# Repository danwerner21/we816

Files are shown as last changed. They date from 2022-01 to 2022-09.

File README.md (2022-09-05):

# WE816
The WE816 is a 16-bit 65816 based system with 512K of System RAM, 96K of System ROM, 32K of video RAM, a TMS9918 graphics processor and an AY-3-8910 Sound chip.  The system runs a custom version of BASIC and supports commodore compatible IEC disk drives.

EhBASIC by Lee Davison was ported to the 65816 CPU on the WE816 computer.   It is designed to allow a full 64K bank for BASIC code and variables with the BASIC interpreter running in a totally different bank. Full documentation on the basic intrepreter can be found in the support folder

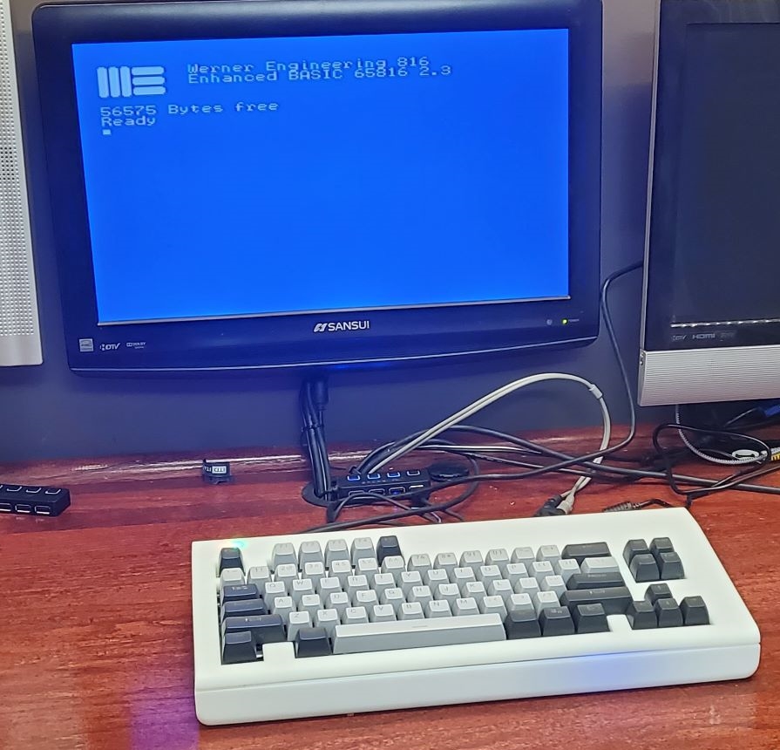
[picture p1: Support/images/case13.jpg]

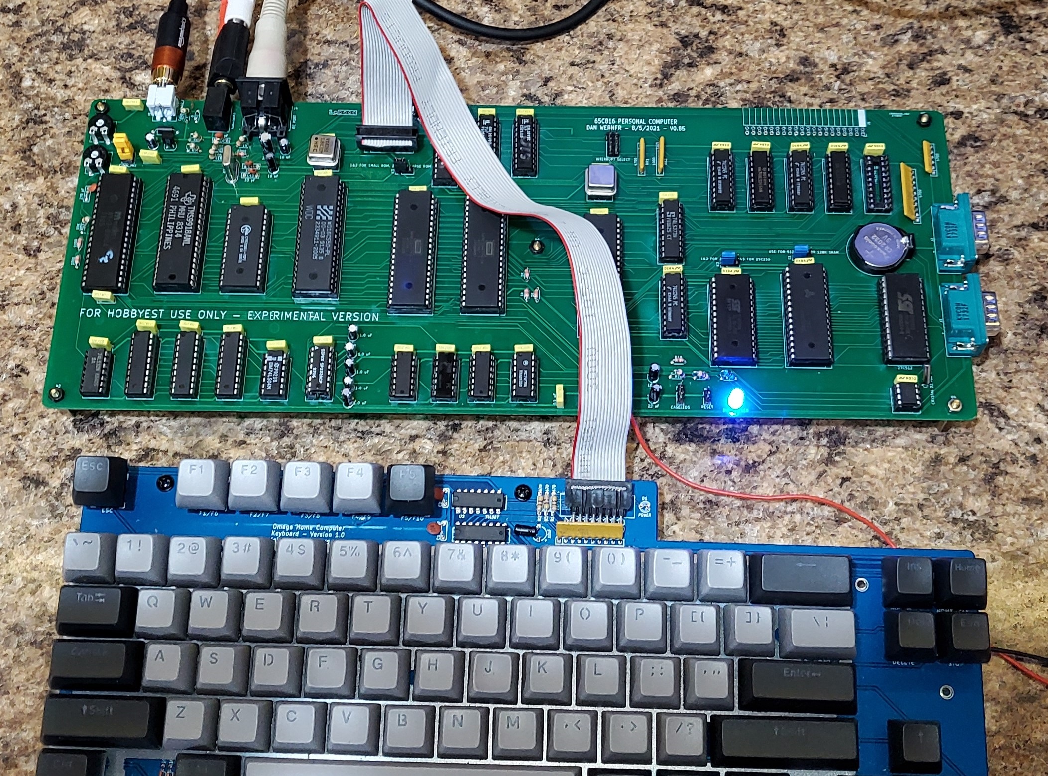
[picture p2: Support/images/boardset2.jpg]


---

## To Do:

* RTC Hardware (fixed needs PCB created and tested)

* BIOS RTC Code

* Basic Access to RTC

* Fix Video RAM paging

* Document BIOS Calls

---

## What is included in this repo?
As of this time, the repo includes

1. The WE816 Mainboard PCB Kicad design and Gerber files
2. The source code and binaries for the WE816 BASIC interpreter
3. The source code and binaries for the WE816 BIOS firmware
4. The source code and binaries for several hardware test programs
5. The logic equasions for the 3 GALs
6. **OpenSCAD and STL files for a 3d printed case

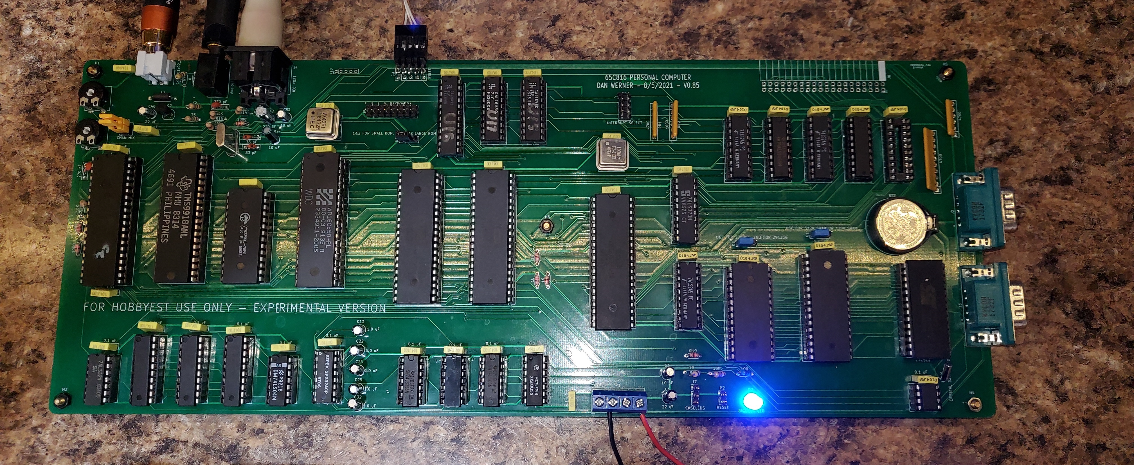
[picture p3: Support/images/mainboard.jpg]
Mainboard

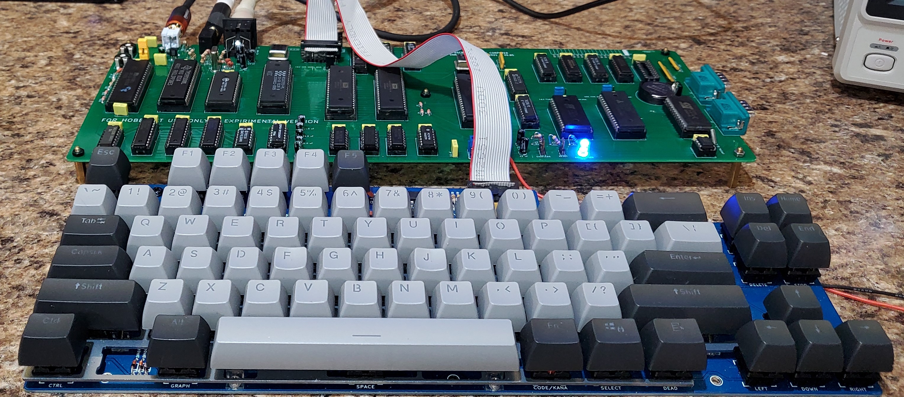
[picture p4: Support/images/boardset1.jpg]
Assembled


---

## Known Bugs

 * Note that the Real Time clock circuit on the 8/5/2021 .85 verson of the board is broken and will not work.  The schematic in this repo has been updated to a working version, but this board still has U12 Pin 6 & 7  connected to CB1 & 2 of U36 which has a broken shift register implementation.   I was under the mistaken impression that the shift register bug had been corrected on the WDC version of the 6522, but this is not the case.

### System Jumpers

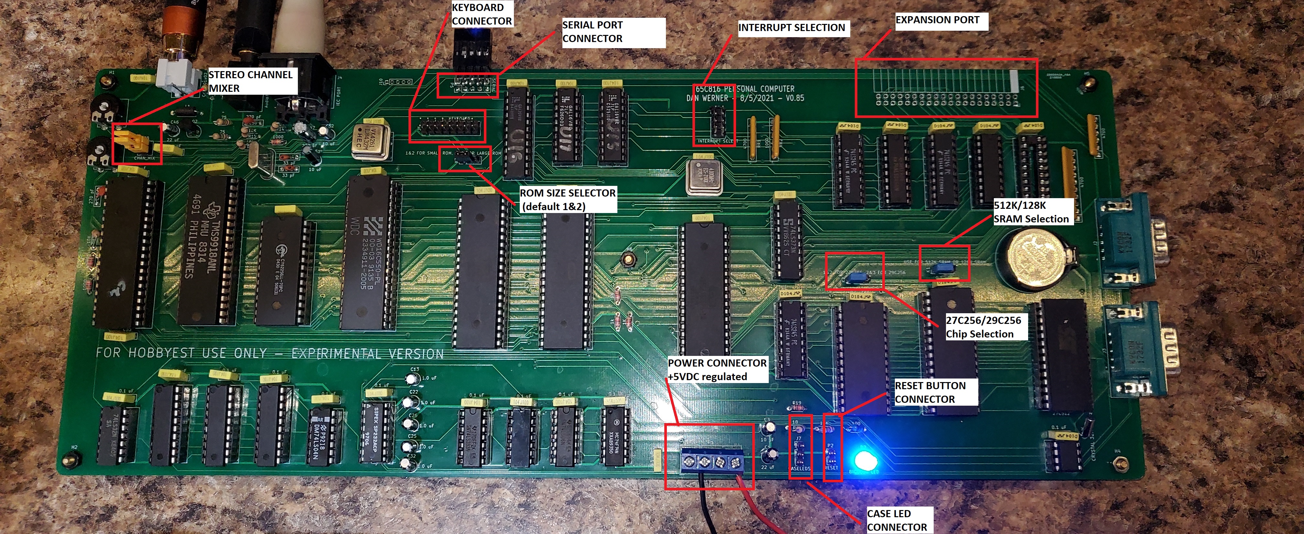
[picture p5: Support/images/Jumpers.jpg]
jumpers


Jumper P9 -- stereo channel mixer

 *  no jumpers, channel a left, channel c right, channel b left and right
 *  1-2 and 2-3 , channel a,b,c mixed to left and right

Jumper K1 - SRAM chip selection

 * 1&2 - 512K chip used (AS6C4008)
 * 2&3 - 128K chip used (AS6C1008)

Jumper K2 - ROM chip selection

 * 1&2 - 27c256 chip used
 * 2&3 - 29c256 chip used

Jumper K3 - ROM size

 * 1&2 - 16K rom page 0 memory map @ $C000
 * 2&3 - 32K rom page 0 memory map @ $8000

Power P1

 * 1- NC
 * 2-GND
 * 3-GND
 * 4-+5VDC 2A Regulated

Reset P2

 * NO Switch (Short to put system in reset)

Jumper J1, Interrupt Select

* 1&8 UART Interrupt enabled
* 2&7 VIA 1 Interrupt enabled
* 3&6 VIA 2 Interrupt enabled
* 4&5 TMS9918 Interrupt enabled

interrupt

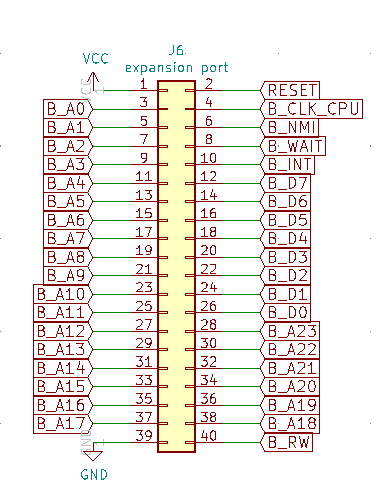
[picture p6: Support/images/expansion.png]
expansion


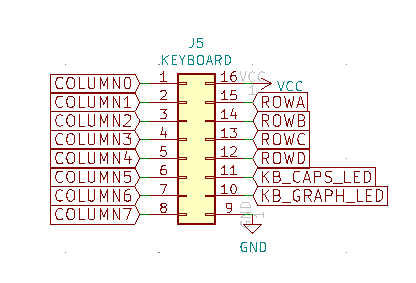
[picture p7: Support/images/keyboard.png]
keyboard


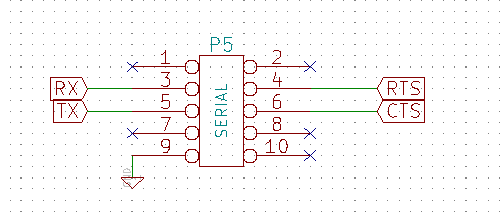
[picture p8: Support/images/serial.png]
serial


---

## Bill Of Materials

### Mainboard

Qty|Reference(s)|Value
--------|--------|----------
1|BT1|Battery_Cell
35|C1-C33, C37, C49|0.1 uF
2|C34, C35|33 pF
2|C36, C48|22 uF
1|C38|220 uF
5|C39-C43|1.0 uF
2|C44, C45|270 pF
3|C46, C47, C50|10 uF
1|D1|BICOLOR LED
1|J1|Conn_01x02_Male
1|J2|Conn_01x06_Male
1|J3|Conn_02x08_Counter_Clockwise
1|J4|DIN-5
1|J5|Conn_01x03_Male
1|J6|Conn_02x04_Counter_Clockwise
1|J7|Conn_02x20_Odd_Even
1|J8|AudioJack3
2|J9, J10|DB9_Male
1|K1|Conn_01x03_Male
1|K2|Conn_01x03_Male
1|K3|Conn_01x03_Male
1|L1|INDUCTOR (BEAD)
1|P1|Conn_02x05_Odd_Even
1|P2|Conn_02x02_Odd_Even
1|P3|Screw_Terminal_01x02
1|P4|Conn_01x02_Male
1|P5|Oscillator:CXO_DIP8
1|Q1|2N3904
1|R1|0 ohm
1|R2|470 ohm
2|R3, R4|75 ohm
3|R5, R6, R7|1K ohm
4|R8, R9, R10, R18|1K ohm
5|R11, R12, R13, R14, R17|10K ohm
1|R15|100 ohm
1|R16|10 ohm
1|RR1|1K ohm Bussed 6 pin
2|RR2, RR3|4700 ohm Bussed 6 pin
1|RR4|4700 ohm Bussed 10 pin
2|RV1, RV2|4700 ohm variable
1|U1|74LS393
1|U2|7406
1|U3|74LS06N
1|U4|74F14  (should be F)
1|U5|74LS04
1|U6|TMS9918
1|U7|74LS574
2|U8, U9|74LS574
1|U10|RAM_32KO
1|U11|74LS32
2|U12, U14|GAL16V8 (7ns)
1|U13|GAL20V8 (7ns)
1|U15|16550
1|U16|DS1302
1|U17|MAX232
2|U18, U19|W65C22NxP
5|U20, U22, U23, U24, U31|74LS245
1|U21|74LS244
1|U25|AY-3-8910
1|U26|SRAM_512KO
1|U27|658C16
1|U28|27C256
1|U29|27C512
1|U30|74LS373
1|X1|10.7 MHz
1|X2|CXO_DIP8
1|X3|CRYSTAL 32.768 KHz

### Keyboard
The Keyboard used in the WE816 is identical to the keyboard used in Sergey Kiselev's MSX compatible OMEGA computer.  See the Schematics, PCB layout and build instructions
[here](https://github.com/skiselev/omega/blob/master/Keyboard.md)

### Case
The case in the following images is a 3D print manufactured by the 3D print service offered by JLCPCB.com.  The case was originally designed to be 3D printed by a FDM printer such as the Anycubic Chiron.   It was originally intended that threaded inserts be melted into the stand off posts so the diameter of the holes were sized accordingly.  If a printing service (such as JLCPCB) is used that uses resin printing, it is necessary to slightly drill out the holes in the stand offs so that threaded inserts can be glued in.   It should also be noted that the design tolerances are quite tight and variations in printing can mean that some slight adjusting may be needed in order to get a good fit.

A 12V to 5V converter can be seen in the image that was added into the case in order to convert the 12V power input to the 5B required by the main board.

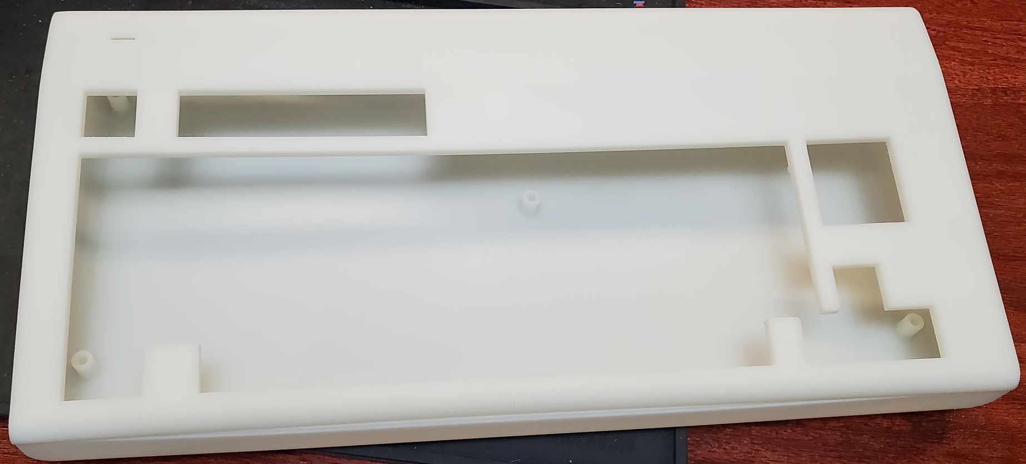
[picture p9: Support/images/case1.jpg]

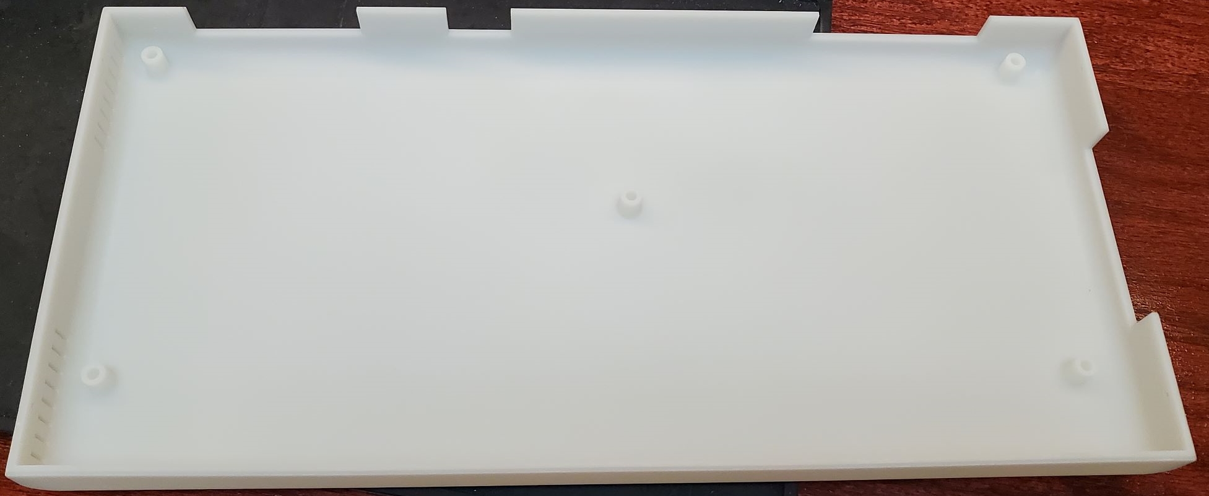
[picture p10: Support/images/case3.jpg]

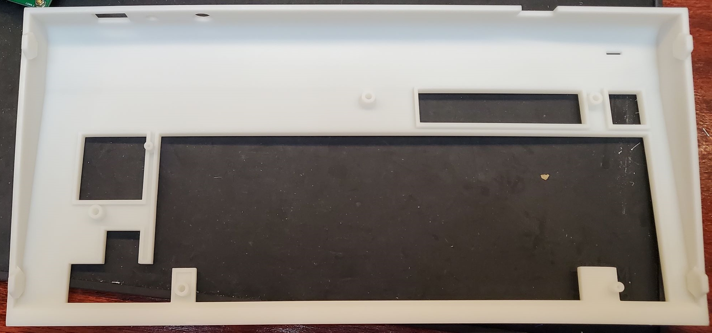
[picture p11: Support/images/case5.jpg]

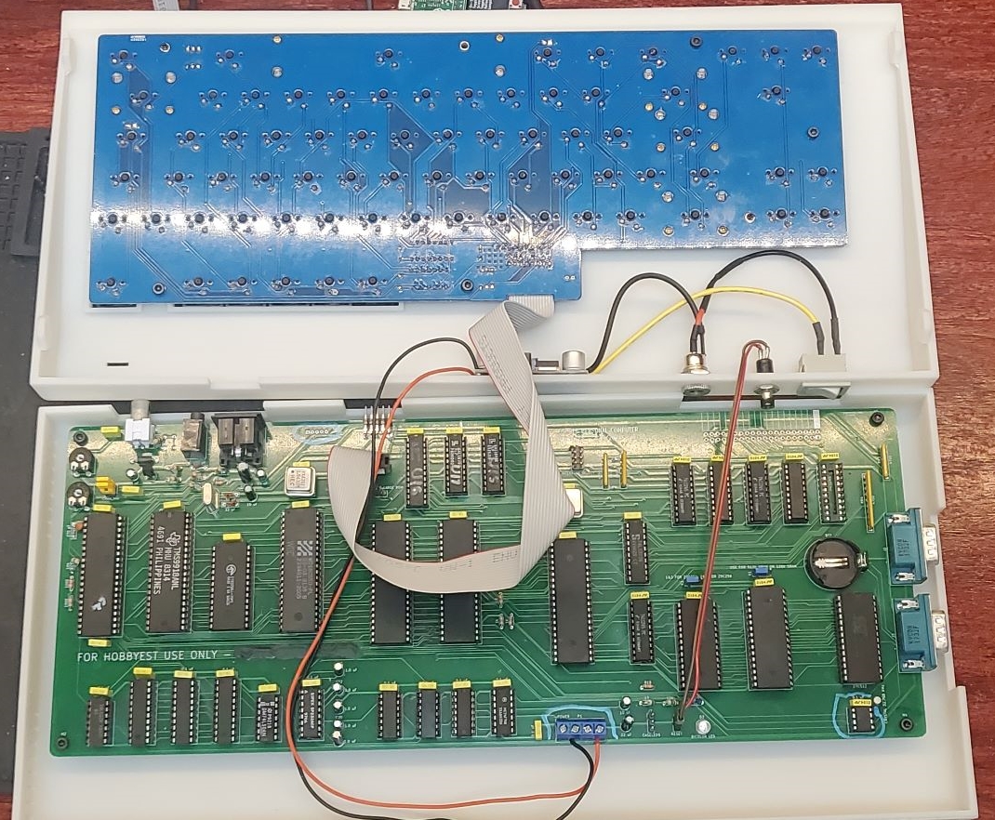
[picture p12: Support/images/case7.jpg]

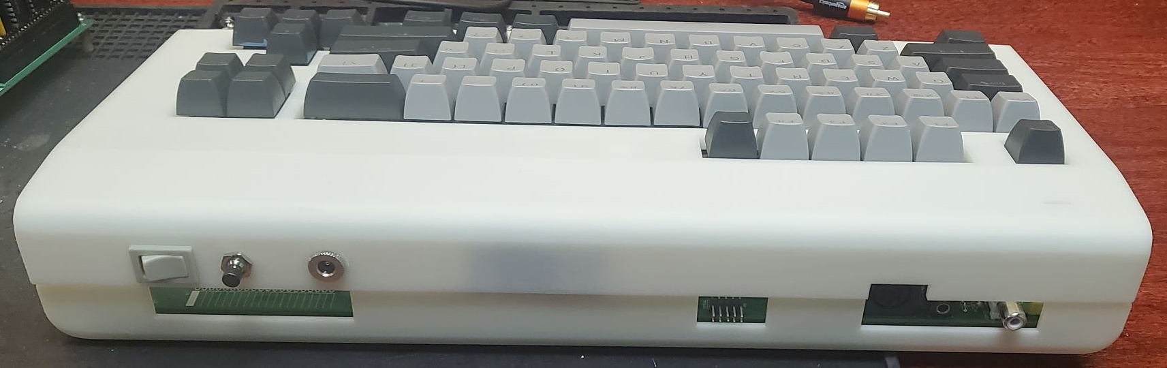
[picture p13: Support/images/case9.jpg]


### Questions?

If there are any questions, I can be reached at vic2020Dan at gmail dot com.

---

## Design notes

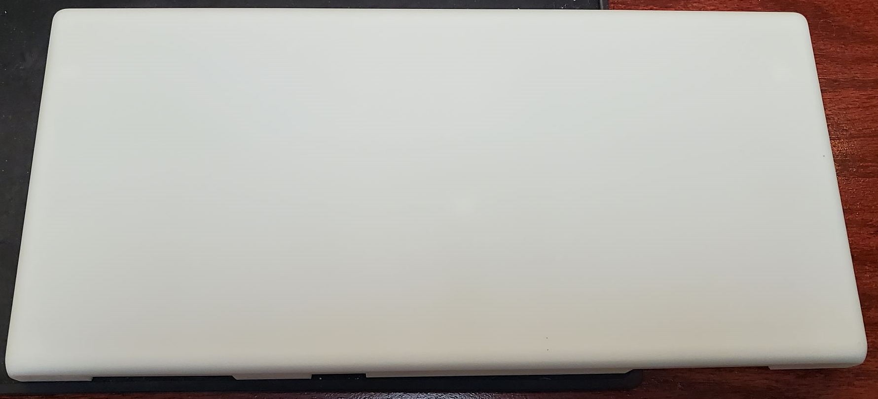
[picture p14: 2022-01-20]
Support/images/case4.jpg

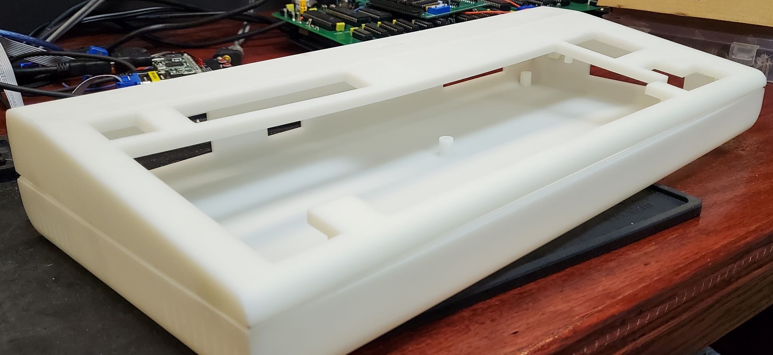
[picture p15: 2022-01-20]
Support/images/case2.jpg

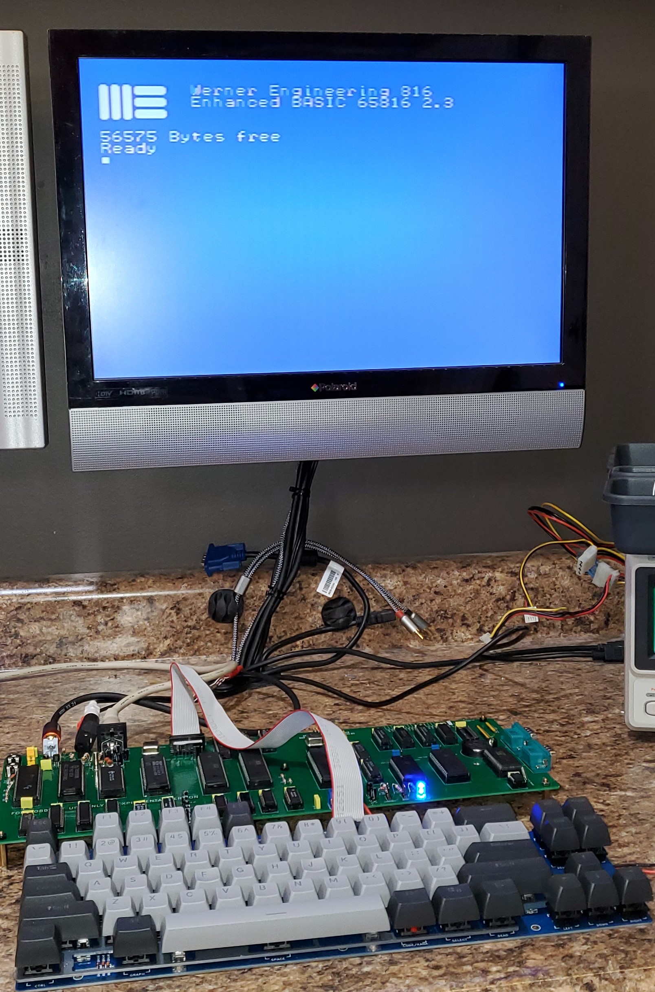
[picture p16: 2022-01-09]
Support/images/bare_system.jpg

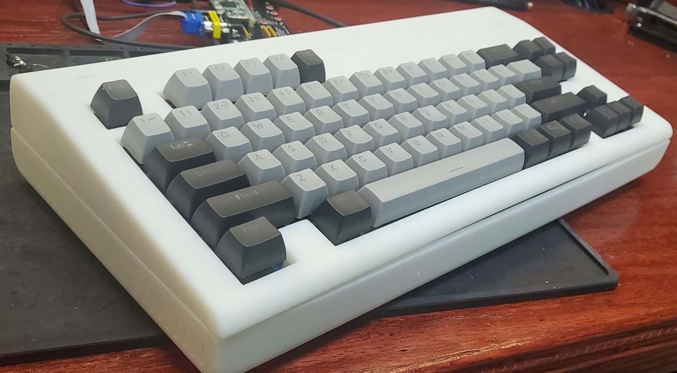
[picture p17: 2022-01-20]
Support/images/case10.jpg

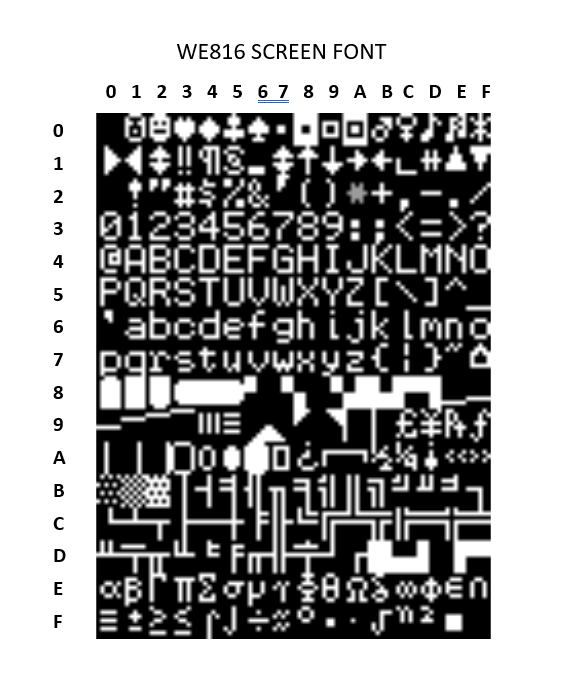
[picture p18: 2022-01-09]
Support/images/font.png

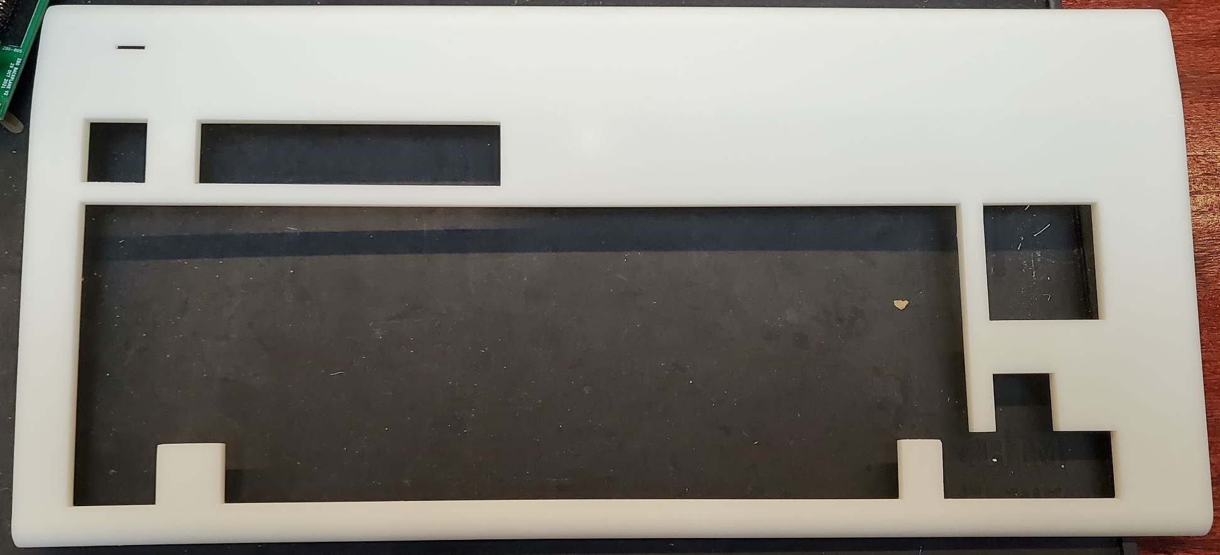
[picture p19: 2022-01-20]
Support/images/case6.jpg

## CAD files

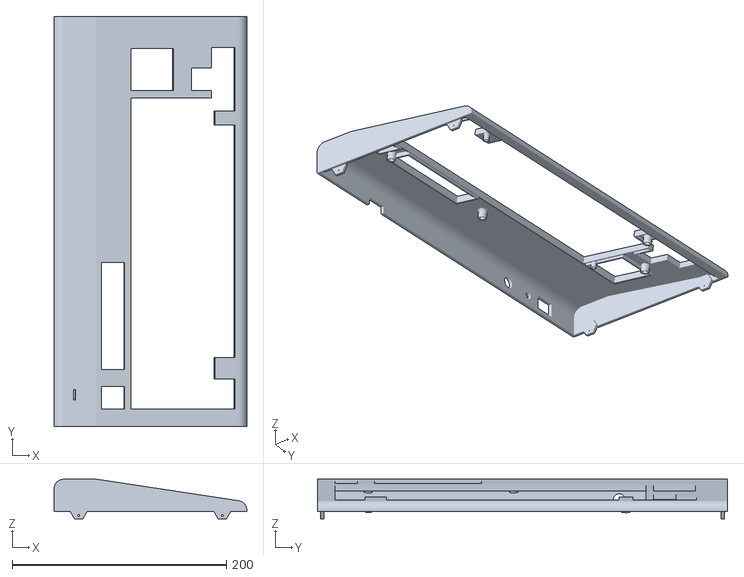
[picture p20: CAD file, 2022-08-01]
Support/WE816case_top.stl
180.0 x 382.5 x 36.9

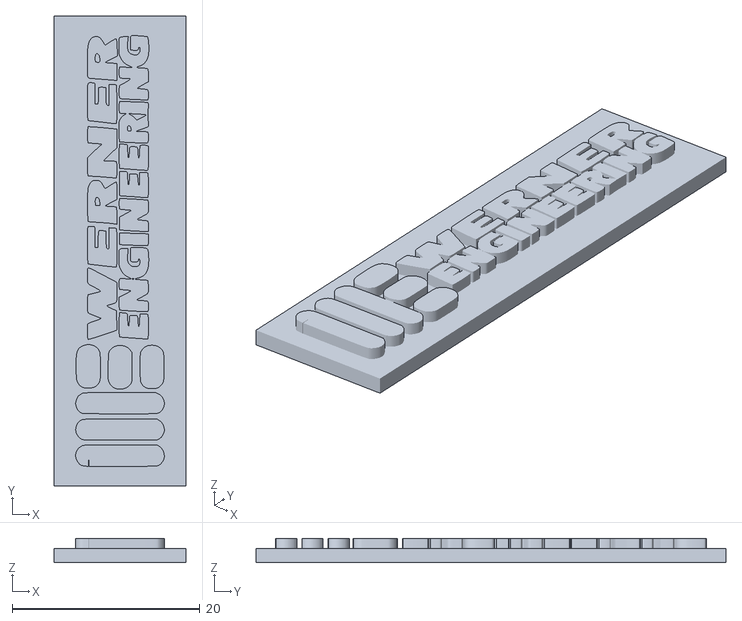
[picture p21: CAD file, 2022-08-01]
Support/WE816case_logo.stl
14.0 x 50.0 x 2.60

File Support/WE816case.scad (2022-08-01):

/* [Box dimensions] */
  Length        = 180;       
  Width         = 385;                     
  TopHeight        = 10;  
  BottomHeight     = 21;  
  SlopeHeight      = 20;
  Thick         = 3;//[2:5]  


  
/* [Box options] */
  PCBFeet       = 1;// [0:No, 1:Yes]
  Vent          = 1;// [0:No, 1:Yes]
  Vent_width    = 1.5;   



  Filet         = 9;//[0.1:12] 
  Resolution    = 50;//[1:100] 
  m             = 0.9;
  
/* [PCB_Feet--the_board_will_not_be_exported) ] */
PCBPosX         = 0;
PCBPosY         = 0;
PCBLength       = 142;
PCBWidth        = 360;
FootHeight      = 5;
FootDia         = 8;
FootHole        = 4.4;  
  

/* [STL element to export] */
//Top shell
  TShell        = 1;// [0:No, 1:Yes]
//Bottom shell
  BShell        = 0;// [0:No, 1:Yes]
// logo plate  
  RLogo         = 0;// Logo


  
/* [Hidden] */
Couleur1        = "Orange";       
Couleur2        = "OrangeRed";    
Dec_Thick       = Vent ? Thick*2 : Thick; 
Dec_size        = Vent ? Thick*2 : 0.8;

PCBL=PCBLength;
PCBW=PCBWidth;



   
module SlopeRoundBox($a=Length, $b=Width, $c=TopHeight+BottomHeight){
                    $fn=Resolution;     
                         
                        translate([Filet,-Filet/2,Filet])
                        {  
                    minkowski ()
                    {  
              
                    translate([0,($b/2)+1,TopHeight])
                       rotate(a=[0,-90,90])
                          linear_extrude(height =(($b/2)-Filet/2)+1, center = false, convexity = 0, twist = 0)
                              polygon(points=[[0,0],[(SlopeHeight+TopHeight)*-1,0],[(SlopeHeight+TopHeight)*-1,-30],  [TopHeight*-1,($a-Filet*2)*-1],[0,($a-Filet*2)*-1]], paths=[[3,2,1,0]]);                      
                        
                     rotate([270,0,0]){    
                        cylinder(r=Filet,h=Width/2+1, center = false);
                            } 
                        }
                    }
                }// End of SlopeRoundBox Module                


module RoundBox($a=Length, $b=Width, $c=TopHeight+BottomHeight){
                    $fn=Resolution;            
                    translate([0,Filet,Filet]){  
                    minkowski (){                                              
                        cube ([$a-(Length/2),$b-(2*Filet),$c-(2*Filet)], center = false);
                        rotate([0,90,0]){   
                           translate([0,0,Filet]){  
                        cylinder(r=Filet,h=Length/2-(2*Filet), center = false);}
                            } 
                        rotate([270,0,0]){    
                        cylinder(r=Filet,h=.1, center = false);
                            } 
                        }
                    }
                }// End of RoundBox Module

      


module TopShell(){
    Thick = Thick*2;  
    difference(){    
        difference(){
            union(){    
                     difference() {
                      
                        difference(){
                            union() {
                                        KeyboardCutoutReinforcement();

                            difference(){
                                SlopeRoundBox();
                                translate([Thick/2,Thick/2,Thick/2]){     
                                        SlopeRoundBox($a=Length-Thick*2, $b=Width-Thick*2, $c=TopHeight+BottomHeight-Thick);
                                        }
                                        }
                                    }
                               translate([-Thick,-Thick,TopHeight]){
                                   cube ([Length+100, Width+100, TopHeight+BottomHeight], center=false);
                                            }                                            
                                      }
                                }                                          

                difference(){
                    union(){
                        translate([3*Thick +5,Thick,TopHeight]){
                            rotate([90,0,0]){
                                    $fn=6;
                                    cylinder(d=16,Thick/2);
                                    }   
                            }
                            
                       translate([Length-((3*Thick)+5),Thick,TopHeight]){
                            rotate([90,0,0]){
                                    $fn=6;
                                    cylinder(d=16,Thick/2);
                                    }   
                            }

                    translate([3*Thick +5,Width-Thick/2-2.4,TopHeight]){
                            rotate([90,0,0]){
                                    $fn=6;
                                    cylinder(d=16,Thick/2);
                                    }   
                            }
                            
                       translate([Length-((3*Thick)+5),Width-Thick/2-2.4,TopHeight]){
                            rotate([90,0,0]){
                                    $fn=6;
                                    cylinder(d=16,Thick/2);
                                    }   
                            }


                        }
                            
                    } 
                    
                    
            }

       }


///Put Difference Keyboard Cutout Here

            union(){ //sides holes
                $fn=50;
                translate([3*Thick+5,20,TopHeight+4]){
                    rotate([90,0,0]){
                    cylinder(d=2,20);
                    }
                }
                translate([Length-((3*Thick)+5),20,TopHeight+4]){
                    rotate([90,0,0]){
                    cylinder(d=2,20);
                    }
                }
                translate([3*Thick+5,Width+5,TopHeight+4]){
                    rotate([90,0,0]){
                    cylinder(d=2,20);
                    }
                }
                translate([Length-((3*Thick)+5),Width+5,TopHeight+4]){
                    rotate([90,0,0]){
                    cylinder(d=2,20);
                    }
                }
            }//fin de sides holes

         // IEC Opening    
            translate([-1,(Thick)+281,Thick-3]){
              cube([21,21,BottomHeight-7]);
            }   

         // Power Switch Opening    
            translate([-1,(Thick)+31,Thick-13]){
              cube([13,20,13]);
            }   


         // Reset Switch Opening    
            translate([-1,(Thick)+65,Thick-7]){
             rotate([0,90,0])
                    cylinder(d=7,20);
            }   


        // Power Jack Opening    
            translate([-1,(Thick)+95,Thick-7]){
             rotate([0,90,0])
                    cylinder(d=11,20);
            }   

        KeyboardCutout();

        }//fin de difference holes
        KeyboardFeet();
        

        
        

}// fin coque 





module BottomShell(){
    Thick = Thick*2;  
    translate([0,2,0]){
    
    difference(){    
        difference(){
            //Main Box
            union(){    
                     difference() {
                      
                        difference(){
                            union() {
                            difference(){
                                RoundBox($a=Length, $b=Width-2, $c=TopHeight+BottomHeight);
                                translate([Thick/2,Thick/2,Thick/2]){     
                                        RoundBox($a=Length-Thick, $b=Width-Thick-2, $c=TopHeight+BottomHeight-Thick);
                                        }
                                        }

                                    }
                               translate([-Thick,-Thick,BottomHeight]){// Cube à soustraire
                                   cube ([Length+100, Width+100, TopHeight+BottomHeight], center=false);
                                            }                                            
                                      }
                                }                                          


              
            }

       
            // vent holes
            union(){           
            for(i=[0:Thick:Length/4]){
                    translate([10+i,-Dec_Thick+Dec_size,1]){
                    cube([Vent_width,Dec_Thick,BottomHeight/2]);
                    }
                    translate([(Length-10) - i,-Dec_Thick+Dec_size,1]){
                    cube([Vent_width,Dec_Thick,BottomHeight/2]);
                    }
               
                  }
                }
                
        
            // Joystick Opening    
            translate([53,Width-Dec_size-2,Thick]){    
              cube([75,Dec_Thick+2,BottomHeight-5]);
            }
                

            // expansion Opening    
            translate([-1,(Thick)+270,Thick]){
              cube([12,70,BottomHeight-3]);
            }
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

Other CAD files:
BASIC/DBASIC816.obj
firmware/ROMBIOS816.obj
firmware/supermon816.obj

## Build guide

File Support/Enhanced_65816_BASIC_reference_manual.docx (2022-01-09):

Enhanced 65816 BASIC reference manual

Preface

The manual this was based on was compiled in October 2013 from a snapshot of Lee Davison’s website http://mycorner.no-ip.org/6502/ehbasic/index.html after it had been off air for quite a while.

Most of the content of this manual is the sole intellectual property of the original author Lee Davison. See the copyright notice in the introduction, for what you can and what you cannot do with the source code and with the documentation. Conversion to run on the WE816 platform and the associated disk, graphics, and sound commands was done by Dan Werner.

Content

# The original Enhanced 6502 BASIC By Lee Davison

## Introduction

Enhanced BASIC is a BASIC interpreter for the 6502 and compatible microprocessors. It is constructed to be quick and powerful and easily ported to most 6502 systems. It requires few resources to run and includes instructions to facilitate easy low level handling of hardware devices. It also retains most of the powerful high level instructions from similar BASICs.

EhBASIC represents hundreds of hours work over nearly three years, lots of frustration, lots of joy and the occasional twinge from RSI induced tendonitis.

EhBASIC is free but not copyright free. For non commercial use there is only one restriction, any derivative work should include, in any binary image distributed, the string "Derived from EhBASIC" and in any distribution that includes human readable files a file that includes the above string in a human readable form e.g. not as a comment in an HTML file.

## EhBasic 65C816 Port

EhBASIC was ported to the 65816 CPU on the WE816 computer. It is designed to allow a full 64K bank for BASIC code and variables with the BASIC interpreter running in a totally different bank. Program Bank, Data Bank and Stack parameters can be adjusted in the definitions.asm file included in the archive, and zero page usage can be found in the zeropage.asm file.

# Enhanced BASIC language reference

Numbers

Numbers may range from zero to plus or minus 1.70141173x10^38 and will have an accuracy of just under 1 part in 1.68 x 10^7.

Numbers can be preceded by a sign, + or -, and are written as a string of numeric digits with or without a decimal point and can also have a positive or negative exponent as a power of 10 multiplier e.g.

-142 96.3 0.25 -136.42E-3 -1.3E7 1

.. are all valid numbers.

Integer numbers, i.e. with no decimal fraction or exponent, can also be in either hexadecimal or binary. Hexadecimal numbers should be preceded by $ and binary numbers preceded by %, e.g.

%101010 -$FFE0 $A0127BD -%10011001 %00001010 $0A

.. again are all valid numbers.

Strings

Strings are any string of printable characters enclosed in a pair of quotation marks. Non printing characters may be converted to single character strings using the CHR$() functions.

"Hello world" "-136.42E-3" "+----+----+" "[Y/n]" "Y"

Are all valid strings.

Variables

Variables of both numeric and string type are available. String variables are distinguished by the $ suffix. As well as simple variables arrays are also available and these may be either numeric or string and are distinguished by their bracketed indices after the variable name.

Variable names may be any length but only the first two name characters are significant so BL and BLANK will refer to the same variable. The first character must be one of "A" to "Z" or "a" to "z", following characters may also include numbers. E.g.

A A$ NAME$ x2LIM y colour s1 s2

Variable names are case sensitive so AB, Ab, aB and ab are all separate variables.

Variable names may not contain BASIC keywords. Keywords are only valid in upper case so 'PRINTER' is not allowed (it would be interpreted as PRINT ER) but 'printer' is.

Note that spaces in variable names are ignored so 'print e r', 'print er' and 'pri nter' will all be interpreted the same way.

### BASIC Keywords

Here is a list of BASIC keywords. They are only valid when entered in upper case as shown and spaces may not be included in them. So GOTO is a valid BASIC keyword but GO TO is not.

ABS | AND | ASC | ATN | BIN$ | BITCLR
BITSET | BITTST | CALL | CHR$ | CLEAR | CLOSE
COLOR | CON | CONT | COS | DATA | DEC
DEEK | DEF | DIM | DIRECTORY | DISKCMD | DISKSTATUS
DO | ELSE | END | EOR | EXP | FN
FOR | FRE | GET# | GET | GOSUB | GOTO
HEX$ | IECINPUT | IECOUTPUT | IECST | IF | INC
INPUT | INT | LCASE$ | LEFT$ | LEN | LET
LIST | LOAD | LOCATE | LOG | LOOP | MAX
MID$ | MIN | MONITOR | NEW | NEXT | NOISE
NOT | NULL | OFF | ON | OPEN | OR
PATTERN | PEEK | PI | PLOT | POKE | POS
PRINT | PUT# | READ | REM | RESTORE | RETURN
RIGHT$ | RND | RUN | SADD | SAVE | SCNCLR
SCREEN | SGN | SIN | SOUND | SPC | SPEEK
SPOKE | SPRDEF | SPRITE | SPRSIZE | SQR | STEP
STOP | STR$ | SWAP | SYS | TAB | TAN
THEN | TO | TONE | UCASE$ | UNTIL | USR
VAL | VARPTR | VOICE | VOLUME | WAIT | WHILE
WIDTH | * | + | - | / | <<
= | >> | < | >

### Manual Conventions

- Anything in upper case is part of the command/function structure and must be present
- Anything in lower case enclosed in < > is to be supplied by the user
- Anything enclosed in [ ] is optional
- Anything enclosed in { } and separated by | characters are multi choice options
- Any items followed by an ellipsis, ... , may be repeated any number of times
- Any punctuation and symbols, except those above, are part of the structure and must be included
- var is a valid variable name
- var$ is a valid string variable name
- var() is a valid array name
- var$() is a valid string array name
- expression is any expression returning a result
- expression$ is any expression returning a string result
- addr is an integer in the range +/- 16777215 that will be wrapped to the range 0 to 65535
- b is a byte value 0 to 255
- n is an integer in the range 0 to 63999 w is an integer in the range -32768 to 32767
- i is a positive integer value
- r is real number
- +r is a positive value real number (0 is considered positive)
- $ is a string literal

### BASIC Commands

#### BITCLR <addr>,<b>

Clears bit b of address addr. Valid bit numbers are 0, the least significant bit, to 7, the most significant bit. Values outside this range will cause a function call error.

#### BITSET <addr>,<b>

Sets bit b of address addr. Valid bit numbers are 0, the least significant bit, to 7, the most significant bit. Values outside this range will cause a function call error.

#### CALL <addr>

CALLs a user subroutine at address addr. No values are passed or returned and so this is much faster than using USR(). See extending CALL for details.

#### CLEAR

Erases all variables and functions and resets FOR .. NEXT, GOSUB .. RETURN and DO ..LOOP states.

#### CLOSE <Logical file b>

Close IEC logical File <b>. See Working with Files for more information.

#### COLOR <background b>,<foreground b>

Sets the background and foreground colors on the text screen.

1 Transparent
2 Black
3 Medium Green
4 Light Green
5 Dark Blue
6 Light Blue
7 Dark Red
8 Cyan
9 Medium Red
10 Light Red
11 Dark Yellow
12 Light Yellow
13 Dark Green
14 Magenta
15 Grey
16 White

#### CONT

Continues program execution after CTRL-C has been typed, a STOP has been encountered during program execution or a null input was given to an INPUT request.

#### DATA [{r|$}[,{r|$}]...]

Defines a constant or series of constants. Real constants are held as strings in program memory and can be read as numeric values or string values. String constants may contain spaces but if they need to contain commas then they must be enclosed in quotes.

DEC <var>[,var]...

Decrement variables. The variables listed will have their values decremented by one. Trying to decrement a string variable will give a type mismatch error. DEC A is much faster than doing A=A-1 and DEC A,A is slightly faster than doing A=A-2.

#### DEF FN <name>(<var>) = <statement>

Defines <statement> as function <name>. <name> can be any valid numeric variable name of one or more characters. <var> must be a simple variable and is used to pass a numeric argument into the function.

Note that the value of <var> will be unchanged if it is used in the function so <var> should be considered to be a local variable name.

DIM <var[$](i1[,i2[,in]...])>[,var[$](i1[,i2[,in]...])]...

Dimension arrays. Creates arrays of either string or numeric variables. The arrays can have one or more dimensions. The lower limit of any dimension is always zero and the upper limit is i. If you do not explicitly dimension an array then it's number of dimensions will be set when you first access it and the upper bound will be set to 10 for each dimension.

#### DIRECTORY <IEC DEVICE b>

Prints the disk directory from device <b>.

#### DISKCMD <command$>,<IEC DEVICE b>

Sends the disk command to device b. See the disk device documentation for a list of commands and syntax.

Example: DISKCMD “S0:FILENAME”,8

DO

Marks the beginning of a DO .. LOOP loop (See LOOP). No parameters. This command can be nested like FOR .. NEXT or GOSUB .. RETURN.

ELSE

See IF.

#### END

Terminates program execution and returns control to the command line (direct mode). END may be placed anywhere in a program, it does not have to be on the last line, and there may be any number, including none, of ENDs in total.

Note. CONT may be used after an END to resume execution from the next statement.

FN<name>(<expression>)

See DEF.

#### FOR <var> = <expression> TO <expression> [STEP expression]

Assigns a variable to a loop counter and optionally sets the start value, the end value and the step size. If STEP expression is omitted then a default step size of +1 will be assumed.

#### GET# <Logical File b>,<var[$]>

Gets a character, if there is one, from the input channel <b>. This command must be preceded by OPEN and IECINPUT commands. See Working with Files for more information.

#### GET <var[$]>

Gets a key, if there is one, from the input device. If there is no key waiting then var will be set to 0 and var$ will return a null string "". GET does not halt and execution will continue.

#### GOSUB <n>

Call a subroutine at line n. Program execution is diverted to line n but the calling point is remembered. Upon encountering a RETURN statement program execution will continue with the next statement (line) after the GOSUB.

GOTO <n>

Continue execution from line number n.

IECINPUT <Logical File b>

Designate IEC channel <b> as input. See Working with Files for more information.

IECOUTPUT <Logical File b>

Designate IEC channel <b> as output. See Working with Files for more information.

#### IF <expression> {GOTO<n>|THEN<{n|statement}>}[ELSE<{n|statement}>]

Evaluates expression. If the result of expression is non zero then the GOTO or the statement after the THEN is executed. If the result of expression is zero then execution continues with the next line.

If the result of expression is zero and the optional ELSE clause is included then the statement after the ELSE is executed.

IF .. THEN .. ELSE .. behaves as a single statement so in the line ..

IF <expression> THEN <statement one> ELSE <statement two> :

<statement three>

.. statement three will always be executed regardless of the outcome of the IF as long as the executed statement was not a GOTO.

INC <var>[,var]...

Increment variables. The variables listed will have their values incremented by one. Trying to increment a string variable will give a type mismatch error. INC A is much faster than doing A=A+1 and INC A,A is slightly faster than doing A=A+2.

INPUT ["$";] <var>[,var]...

Get a variable, or list of variables from the input stream. A question mark, "?", is always output, after the string if there is one, and if further input is required, i.e. there are more variables in the list than the user entered values, then a double question mark, "??", will be output until enough values have been entered.

There are two possible messages that may appear during the execution of an input statement:

##### Extra ignored

The user has attempted to enter more values than are required. Program execution will continue but the extraneous data entered has been discarded.

##### Redo from start

The user has attempted to enter a string where a number was expected. The reverse never causes an error as numbers are also valid strings.

#### LET <var> = <expression>

Assign the value of expression to var. Both var and expression bust be of the same type. The LET command word is optional and just <var> = <expression> will give exactly the same result. It is only maintained for historical reasons.

#### LIST [n1][-n2]

Lists the entire program held in memory. If n1 is specified then the listing will start from line n1 and run to the end of the program. If -n2 is specified then the listing will terminate after line n2 has been listed. If n1 and -n2 are specified then all the lines from n1 to n2 inclusive will be listed.

Note. If n1 does not exist then the list will start from the next line numbered after n1. If n2 does not exist then the listing will stop with the last line numbered before n2.

Also note. LIST can be executed from within a program, first a [CR][LF] is printed and then the specified lines, if any, each terminated with another [CR][LF]. Program execution then continues as normal.

LOAD var[$] ,<b>

Load a program named var[$] from IEC channel <b>.

#### LOOP [{UNTIL|WHILE} expression]

Marks the end of a DO .. LOOP loop. There are three possible variations on the LOOP command ..

#### LOOP

This loop repeats forever. With just this command control is passed back to the next command after the corresponding DO.

#### LOOP UNTIL expression

This loop will repeat until the value of expression is non zero. Once that occurs execution will continue with the next command after the LOOP UNTIL.

#### LOOP WHILE expression

This loop will repeat while the value of expression is non zero. When the value of expression is zero execution will continue with the next command after the LOOP WHILE.

MONITOR

Exit to the system monitor. See WE816 system documentation for more information on how to use the system monitor.

NEW

Deletes the current program and all variables from memory.

#### NEXT [var[,var]...]

Increments or decrements a loop variable and checks for the terminating condition. If the terminating condition has been reached then execution continues with the next command, else execution continues with the command after the FOR assignment. See FOR.

NOISE <channel b>,<noise period b>

Selects a given channel (0-2) to generate NOISE, rather than TONE, and configures the noise period.

NOT <expression>

Generates the bitwise NOT of then signed integer value of <expression>.

#### NULL <n>

Sets the number of null characters printed by BASIC after every carriage return. n may be specified in the range 0 to 255.

ON <expression> {GOTO|GOSUB} <n>[,n]...

The integer value of expression is calculated and then the nth number after the GOTO or GOSUB is taken (where n is the result of expression). Note that valid results for expression range only from zero to 255. Any result outside this range will cause a Function call error.

#### OPEN <Logical File b>,<IEC Device Number b>,<Secondary Address b>,<file name var[$]>

Open a file to an IEC Device. See Working with Files for more information.

PATTERN <pattern number b>,<Color b>, <b>,<b>,<b>,<b>, <b>,<b>,<b>,<b>

Defines Pattern for a graphics Character. See Working with Graphics for more information.

PLOT <b>,<b>,<b>,<b>

Video Mode 0 and 3:

Plot a pattern to the screen X,Y,Pattern

Video Mode 1:

Plot a pixel to the screen X,Y,Color

Video Mode 4:

Plot a pixel to the screen X,Y,Priority,Color.

See Working with Graphics for more information.

POKE <addr,b>

Writes the byte value b into the address addr.

#### PRINT [expression][{;|,}expression]...[{;|,}]

Outputs the value of each expressions. If the list of expressions to be output does not end with a comma or a semi-colon, then a carriage return and linefeed is output after the values.

Expressions on the line can be separated with either a semi-colon, causing the next expression to follow immediately, or a comma which will advance the output to the next tab stop before continuing to print. If there are no expressions and no comma or semi-colon after the PRINT statement then a carriage return and linefeed is output.

When entering a program line, or immediate statement, PRINT can be abbreviated to ?

#### PUT# <Logical File b>,<var[$]>

Outputs the char value to IEC channel <b>. This must be preceded with Open and IECOUTPUT commands. See Working with Files for more information.

READ <var>[,var]...

Reads values from DATA statements and assigns them to variables. Trying to read a string literal into a numeric variable will cause a syntax error.

REM

Everything following this statement on this program line will be ignored, even colons.

#### RESTORE [n]

Reset the DATA pointer. If n is specified then the pointer will be reset to the beginning of line n else it will be reset to the start of the program. If n is specified but doesn't exist an error will be generated.

#### RETURN

Returns program execution to the next statement (line) after the last GOSUB encountered. See GOSUB. Also returns program execution to the next statement after an interrupt but does not restore the enabled flags.

#### RUN [n]

Begins execution of the program currently in memory at the lowest numbered line. RUN erases all variables and functions, resets FOR .. NEXT, GOSUB .. RETURN and DO ..LOOP states and sets the data pointer to the program start.

If n is specified then programme execution will start at the specified line number.

#### SAVE <var[$]>,<b>

Save the program in memory to filename <$> on IEC Device <b>.

#### SCNCLR

Clear the Text Screen.

#### SCREEN <b>

Set the graphics screen mode. Note that this will only change modes within a running basic program, immediate mode must always be in the text screen mode. See Working with Graphics for more information.

1 Graphics Mode (32x24 patterns)
2 Multicolor (64x64 blocks)
3 Text Mode (40x24)

4 Hires Graphics Mode (256x192)

SOUND <channel b>, <frequency var>

Play a sound on channel (0-2), at the frequency var. See Appendix for musical note to frequency values. Note that “frequency” does not equate to actual frequency of the note provided.

SPC(<expression>)

Prints <expression> spaces. This command is only valid in a PRINT statement.

SPOKE <addr>,<b>

Poke a value <b> into screen memory at address <addr>.

SPRDEF <b>,<b> . . . <b>

Define a sprite pattern <b>, followed by a pattern of 8 bytes.

SPRITE <Sprite #b>,<Sprite Pattern b>,<X b>,<Y b>,<Color b>,<LeftShift b>

Set sprite parameters, SpriteNum,SpritePattern,X,Y,Color,LeftShift(0/1). See Working with Sprites for more information.

SPRSIZE <b>

Set Sprite sizes.

1 8x8 Sprites, 1x magnification
2 8x8 Sprites, 2x magnification
3 16x16 Sprites, 1x magnification
4 16x16 Sprites, 2x magnification

STEP

Sets the step size in a FOR .. NEXT loop. See FOR.

#### STOP

Halts program execution and generates a "Break in line n" message where n is the line in which the STOP was encountered.

#### SWAP <var[$]>,<var[$]>

Swap two variables. The variables listed will have their values exchanged. Both must be of the same type, numeric or string, and either, or both, may be array elements. Trying to swap a numeric and string variable will give a type mismatch error.

#### TAB(<expression>)

Sets the cursor position to <expression>. If the cursor is already beyond that point then the cursor will be left where it is. This command is only valid in a PRINT statement.

THEN

See IF.

TO

Sets the range in a FOR .. NEXT loop. See FOR.

TONE <channel b>

Sets the channel (0-2) to generate TONEs rather than NOISE.

UNTIL

See DO and LOOP.

#### VOICE <shape b>,<period var>

Set the envelope generator on the chip to a given shape, and period (duration of one cycle).

Shapes:

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
#### VOLUME <channel b>,<volume b>

Set the volume of a given channel (0-2) to <B>.

For solid tones, use values 0-15. To use the envelope generator on the chip, use values 16-31.

#### WAIT <addr,b1>[,b2]

Program execution will wait at this point until the value of the location addr exclusive ORed with b2 then ANDed with b1 is non zero. If b2 is not defined then it is assumed to be zero. Note b1 and b2 must both be byte values.

WHILE

See DO and LOOP.

#### WIDTH {b1|,b2|b1,b2}

Sets the terminal width and TAB spacing. b1 is the terminal width and b2 is the tab spacing, default is 80 and 14. Width can be zero, for "infinite" terminal width, or from 16 to 255. The tab size is from 2 to width-1 or 127, whichever is smaller.

### BASIC Operators

Operators perform mathematical or logical operations on values and return the result. The operation is usually preceded by a variable name and equality sign or is part of an IF .. THEN statement.

+ Add. c = a + b will assign the sum of a and b to c.

- Subtract. c = a - b will assign the result of a minus b to c.

* Multiply. c = a * b will assign the product of a and b to c.

/ Divide. c = a / b will assign the result of a divided by b to c.

^ Raise to the power of. c = a ^ b will assign the result of a raised to the power of b to c.

AND Logical AND. c = a AND b will assign the logical AND of a and b to c

EOR Logical Exclusive OR. c = a EOR b will assign the logical exclusive OR of a and b to c.

OR Logical OR. c = a OR b will assign the logical inclusive OR of a and b to c.

<< Shift left. c = a << b will assign the result of a shifted left by b bits to c.

>> Shift right. c = a >> b will assign the result of a shifted right by b bits to c.

= Equals. c = a = b will assign the result of the comparison a = b to c.

> Greater than. c = a < b will assign the result of the comparison a > b to c.

< Less than. c = a < b will assign the result of the comparison of a < b to c.

The three comparison operators can be mixed to provide further operators ..

>= or => Greater than or equal to.

<= or =< Less than or equal to.

<> or >< Not equal to (greater than or less than).

<=> any order Always true (greater than or equal to or less than).

### BASIC Functions

Functions always return a value, be it numeric or string, so are used on the right hand side of the = sign in assignments, on either side of operators and in commands requiring an expression e.g. after PRINT, within expressions, or in other functions.

ABS(<expression>)

Returns the absolute value of <expression>.

ASC(<expression$>)

Returns the ASCII value of the first character of <expression$>.

ATN(<expression>)

Returns, in radians, the arctangent of <expression>.

#### BIN$(<expression>[,b])

Returns <expression> as a binary string. If b is omitted, or if b = 0, then the string is returned with all leading zeroes removed and is of variable length. If b is set, permissible values range from 1 to 24, then a string of length b will be returned. The result is always unsigned and calling this function with expression > 2^24-1 or b > 24 will cause a function call error.

#### BITTST(<addr>,<b>)

Tests bit b of address addr. Valid bit numbers are 0, the least significant bit, to 7, the most significant bit. Values outside this range will cause a function call error. Returns zero if the bit was zero, returns -1 if the bit was 1.

#### CON(<b>)

Takes game controller number as one parameter (0,1) and returns the state of that game controller. The status of the controller is encoded like this:

BIT 7 | BIT 6 | BIT 5 | BIT 4 | BIT 3 | BIT 2 | BIT 1 | BIT 0
| | BUTTON B | BUTTON A | RIGHT | LEFT | DOWN | UP

COS(<expression>)

Returns the cosine of the angle <expression> radians.

#### DISKSTATUS(<b>)

Returns the string value of the disk status of device <b>

EXP(<expression>)

Returns e^<expression>. Natural antilog.

#### FRE(<expression>)

Returns the amount of free program memory. The value of expression is ignored and can be numeric or string.

#### HEX$(<expression>[,b])

Returns <expression> as a hex string. If b is omitted, or if b = 0, then the string is returned with all leading zeroes removed and is of variable length. If b is set, permissible values range from 1 to 6, then a string of length b will be returned. The result is always unsigned and calling this function with expression > 2^24-1 or b > 6 will cause a function call error.

IECST(<b>)

Returns the IEC status of channel <b>.

INT(<expression>)

Returns the integer of <expression>.

LCASE$(<expression$>)

Returns <expression$> with all the alpha characters in lower case.

LEFT$(<expression$,b>)

Returns the leftmost b characters of <expression$>.

LEN(<expression$>)

Returns the length of <expression$>.

LOG(<expression>)

Returns the natural logarithm (base e) of <expression>.

#### MAX(<expression>[,<expression>]...)

Returns the maximum value from a list of numeric expressions. There must be at least one expression but the upper limit is dictated by the line length. Each expression is evaluated in turn and the largest of them returned.

#### MID$(<expression$,b1>[,b2])

Returns the substring string from character b1 of expression$ of length b2. The characters of expression$ are numbered from 1 starting with the leftmost. If b2 is omitted then all the characters from b1 to the end of the string are returned.

#### MIN(<expression>[,<expression>]...)

Returns the minimum value from a list of numeric expressions. There must be at least one expression but the upper limit is dictated by the line length. Each expression is evaluated in turn and the smallest of them returned.

PEEK(<addr>)

Returns the byte value of <addr>.

PI

Returns the value of pi as 3.14159274 (closest floating value).

POS(<expression>)

Returns the POSition of the cursor on the terminal line. The value of expression is ignored.

RIGHT$(<expression$,b>)

Returns the rightmost b characters of <expression$>.

#### RND(<expression>)

Returns a random number in the range 0 to 1. If the value of <expression> is non zero then it will be used as the seed for the returned pseudo random number otherwise the next number in the sequence will be returned.

#### SADD(<{var$|var$()}>)

Returns the address of var$ or var$(). This returns a pointer to the actual string in memory not the descriptor. If you want the pointer to the descriptor use VARPTR instead.

#### SGN(<expression>)

Returns the sign of <expression>. If the value is positive SGN returns +1, if the value is negative then SGN returns -1. If expression=0 then SGN returns 0.

SIN(<expression>)

Returns the sine of the angle <expression> radians.

SPEEK (<addr>)

Return the value at screen memory address <addr>.

SQR(<expression>)

Returns the square root of <expression>.

STR$(<expression>)

Returns the result of <expression> as a string.

TAN(<expression>)

Returns the tangent of the angle <expression> radians.

UCASE$(<expression$>)

Returns <expression$> with all the alpha characters in upper case.

CHR$(b)

Returns single character string of character <b>.

#### USR(<expression>)

Takes the value of <expression> and places it in FAC1 and then calls the USeR routine pointed to by the vector at $0B,$0C. What the routine does with this value is entirely up to the user, it can even be safely ignored if it isn't needed. The routine, after the user code has done an RTS, takes whatever is in FAC1 and returns that. Note it can be either a numeric or string value. See using USR() for details.

If no value needs to be passed or returned then CALL is a better option.

VAL(<expression$>)

Returns the value of <expression$>.

#### VARPTR(<var[$]>)

Returns a pointer to the variable memory space. If the variable is numeric, or a numeric array element, then VARPTR returns the pointer to the packed value of that variable in memory. If the variable is a string, or a string array element, then VARPTR returns a pointer to the descriptor for that string. If you want the pointer to the string itself use SADD instead.

### BASIC Error Messages

These all occur from time to time and, if the error occurred while executing a program, will be followed by "in line " where is the number of the line in which the error occurred.

##### Array bounds Error

An attempt was made to access an element of an array that was outside it's bounding dimensions.

##### Can't continue Error

Execution can't be continued because either the program execution ended because an error occurred, NEW or CLEAR have been executed since the program was interrupted or the program has been edited.

Divide by zero Error

The right hand side of an A/B expression was zero.

##### Double dimension Error

An attempt has been made to dimension an already dimensioned array. This could be because the array was accessed previously causing it to be dimensioned by default.

##### Function call Error

Some parameter of a function was outside it's limits. E.g. Trying to POKE a value of less than 0 or greater than 255.

##### Illegal direct Error

An attempt was made to execute a command or function in direct mode which is disallowed in that mode e.g. INPUT or DEF.

LOOP without DO Error

LOOP has been encountered and no matching DO could be found.

NEXT without FOR Error

NEXT has been encountered and no matching FOR could be found.

##### Out of DATA Error

A READ has tried to read data beyond the last item. Usually because you either mistyped the DATA lines, miscounted the DATA, RESTOREd to the wrong place or just plain forgot to restore.

##### Overflow Error

The result of a calculation has exceeded the numerical range of BASIC. This is plus or minus

1.7014117+E38

##### Out of memory Error

Anything that uses memory can cause this but mostly it's writing and running programmes that does it.

RETURN without GOSUB Error

RETURN has been encountered and no matching GOSUB could be found.

##### String too complex Error

A string expression caused an overflow on the descriptor stack. Try splitting the expression into smaller pieces.

String too long Error

String lengths can be from zero to 255 characters, more than that and you will see this.

Syntax Error

Just generally wrong. 8^)=

##### Type mismatch Error

An attempt was made to assign a numeric value to a string variable, a string value to a numeric variable or a value of one type was returned when a value of the other type was expected or an attempt at a relational operation between a string and a number was made.

Undefined function Error

FN <var> was called but not found.

##### Undefined statement Error

Either a GOTO, GOSUB, RUN or RESTORE was attempted to a line that doesn't exist or the line referred to in an ON <expression> {GOTO|GOSUB} or ON {IRQ|NMI} doesn't exist.

## Enhanced BASIC, advanced examples

Working with Files.

The following is an example BASIC program that writes and reads back a sequential file to the Commodore 1541 Disk Drive. For more advanced drive functions, please see the reference guide for the IEC device you are communicating with.

10 OPEN 3,8,4,"TFI2,SEQ,W"

20 IECOUTPUT 3

30 PUT#3,"OUT"+CHR$(13)

31 PUT#3,"OUT1"+CHR$(13)+CHR$(5)

32 PUT#3,"OUT2"+CHR$(13)+CHR$(10)+CHR$(5)

40 CLOSE 3

70 OPEN 4,8,8,"TFI2,SEQ,R"

80 IECINPUT 4

90 GET#4,A

100 PRINT A, IECST

101 IF IECST=0 THEN GOTO 90

110 CLOSE 4

Working with Sound.

The AY-3-8910 sound chip is a simple (by today’s standards) sound generation chip. It contains 3 voices that can be configured as either tone or noise, and has a simple envelope generator. More specific information on the AY-3-8910 can be found online or in the AY-3-8910 datasheet.

Here are a few sample BASIC programs to generate a series of tones from the WE816.

Program 1:

5 REM SIMPLE SERIES OF TONES ON VOICE 0

10 VOLUME 0,15

20 TONE 0

30 I=100

30 FOR I = 100 TO 4000 STEP 100

40 SOUND 0,I

50 FOR X = 0 TO 500: NEXT X

60 NEXT I

70 SOUND 0,0

Program 2:

4 REM MORE COMPLEX SOUNDS USING THE ENVELOPE

6 REM GENERATOR AND A SAWTOOTH WAVEFORM

10 VOLUME 0,31

20 TONE 0

25 VOICE 8,2000

30 FOR I = 100 TO 4000 STEP 100

40 SOUND 0,I

50 FOR X = 0 TO 500: NEXT X

60 NEXT I

70 SOUND 0,0

Working with Graphics.

EhBasic supports working with graphics in 3 modes, on the WE816.

- 0 - Graphics Mode (32x24 tiled patterns)
- 1 - Multicolor (64x64 blocks)
- 4 - Hires Graphics Mode (256x192)

Each mode has different constraints and a different mode of operation. Note that graphics modes can only be accessed from inside a running BASIC program. Direct mode operation is not allowed.

Mode 0 Example:

10 SCREEN 0 Set screen mode 0

20 REM BUILD A GRAPHICS PATTERN

30 PATTERN 1,5,255,0,255,0,255,0,255,0 Define a pattern

40 PLOT 5,5,1 Place the pattern on the screen

50 INPUT G$ Wait!! (stop program from exiting out of graphics mode)

Mode 1 Example:

10 SCREEN 1 Set screen mode 1

20 PLOT 5,5,3 Place A block on the screen (location 5,5 color 3)

30 PLOT 6,6,4 Place A block on the screen (location 6,6 color 4)

40 PLOT 7,7,5 Place A block on the screen (location 7,7 color 5)

50 INPUT G$ Wait!! (stop program from exiting out of graphics mode)

Mode 4 Example:

10 SCREEN 4 Set screen mode 4

20 PLOT 5,5,0,3 Place A block on the screen (location 5,5 color 3)

30 PLOT 6,6,0,4 Place A block on the screen (location 6,6 color 4)

40 PLOT 7,7,0,5 Place A block on the screen (location 7,7 color 5)

50 INPUT G$ Wait!! (stop program from exiting out of graphics mode)

Working with Sprites.

Sprites are a powerful feature of the TMS9918 graphics chip. All modes except for 2 can render sprites. There can be up to 32 monochrome sprites of either 8×8 or 16×16 pixels on screen, each sprite with its own, single color. The illusion of multicolor sprites can be created by stacking multiple sprites on top of each other. There can be no more than 4 sprites on a single scanline; any additional sprites' horizontal pixels are dropped. Sprites with a higher priority are drawn first. See the TI TMS9918 programmers guide for more information on sprites.

10 SCREEN 1 place the system in a graphics mode, no sprites in mode 2.

20 SPRDEF 0,255,0,255,0,255,0,255,0 define sprite patten 0

30 SPRSIZE 0 set 1x 8x8 sprites

40 FOR I = 0 TO 255 let’s loop to move our sprite! (location 7,7 color 5)

50 SPRITE 0,0,I,40,3,0 Place sprite 0, pattern 0 at I,40 on the screen color 3

60 NEXT I loop!

70 GOTO 40 Rinse and repeat

Creating buffer space.

Sometimes there is a need for a byte oriented buffer space. This can be achieved by lowering the top of BASIC memory and using the "protected" space created thus. The main problem with this is that there may not be the same RAM configuration in all the systems this code is to run on.

One way round this is to allocate the space from BASIC's array memory by dimensioning an array big enough to hold your data. As arrays always start from zero then to work out the array size needed you do ..

Array dimension = (bytes needed/4)-1. E.g.

10 DIM b1(19) : REM need 80 bytes for input buffer

20 DIM b2($100) : REM need $0400 bytes for screen buffer

So you've allocated the buffer but where is it? This is one use of the VARPTR function, it is used in this case to return the start of the array's data space.

E.g.

100 a1 = VARPTR(b1(0)) : REM get the address of the buffer space

But wait, there is another problem here. Because variables are created when they are first assigned a value any new variable created after the array is dimensioned will move the array in memory. So the following will not work..

10 DIM b1(19) : REM 80 bytes for buffer

20 a1 = VARPTR(b1(0)) : REM get the address of the buffer space

40 FOR x = 0 to 79

50 POKE a1+x,ASC(" ") 60 NEXT

When we get to line 40, a1, the pointer to the array data space, is wrong because the variable x has been created and moved all the arrays up by six bytes. The way round this is to ensure that all variables that you will use have been created prior to getting the pointer. This also means you start with known values in all your variables.

10 DIM b1(19) : REM 80 bytes for buffer

20 x = 0 : REM loop counter

30 a1 = VARPTR(b1(0)) : REM get the address of the buffer space

40 FOR x = 0 to 79

50 POKE a1+x,ASC(" ") 60 NEXT

Another way is to get the pointer every time you use it. This has the advantage of always being correct but is somewhat slower.

10 DIM b1(19) : REM 80 bytes for buffer

40 FOR x = 0 to 79

50 POKE VARPTR(b1(0))+x,ASC(" ") 60 NEXT

One thing to remember, never try to use a string array as a buffer. Everything will seem to work until you run out of string space and the garbage collection routine is called. Once this happens it's likely that your buffer will get trashed and you may even find that the program freezes because the garbage collection routine now thinks that there are more string bytes than there are memory.

Creating short code space.

While the techniques explained above can also be used to create space for machine code routines there is a simpler way for position independent routines up to 255 bytes long to be held in memory.

Assemble the code and use the hex output from your assembler to create a set of BASIC data statements.

E.g.

1000 DATA $A5,$11,$C9,$3A,$B0,$08,$38,$E9

1010 DATA $30,$38,$E9,$D0,$90,$0D,$09,$20

1020 DATA $38,$E9,$61,$90,$0B,$C9,$06,$B0

1030 DATA $07,$69,$3A,$E9,$2F,$85,$11,$60

1040 DATA $18,$60 1050 DATA -1

Now we just use a loop like this to load this hex code into a string.

10 RESTORE 1000

20 READ by : REM assume at least one byte

30 DO

40 co$ = co$+CHR$(by)

50 READ by

60 LOOP UNTIL by=-1

The code can now be called by doing ..

140 CALL(SADD(co$))

Note that you must always use the SADD() function to get the address for the CALL as the garbage collection routine may move the string in memory and this is the best way to ensure that the address is always correct.

Coding for speed

Spaces

Remove spaces from your code. Spaces, while they don't affect the program flow, do take a finite time to skip over. The only space you don't need to worry about is the one between the line number and the code as this is stripped during input parsing and the apparent space is generated by the LIST command output.

E.g. the following ..

10 REM line 10

20 REM line 20

30 REM line 30

.. reads as follows when LISTed

10 REM line 10

20 REM line 20

30 REM line 30

Removing REM.

Remove remarks from your code. Remarks like spaces don't do anything, program wise, but take time to skip. Removing remarks, especially from time critical code, can make a big difference.

Variables.

Use variables. One place where time is wasted, especially in loops, is repeatedly interpreting numeric values or unchanging functions.

E.g.

140 FOR x = 0 to 79

150 POKE $F400+x,ASC(" ") 160 NEXT .

This loop can be improved in a number of ways. First assign a variable the value $F400 and use that. Doing this is faster after only three uses.

E.g.

10 a1 = $F400 .

140 FOR x = 0 to 79

150 POKE a1+x,ASC(" ") 160 NEXT

The other way to make this loop faster is to assign the value of the (unchanging) function to a variable, then move the function outside the loop.

E.g.

10 a1 = $F400 .

130 sp = ASC(" ")

140 FOR x = 0 to 79

150 POKE a1+x,sp 160 NEXT

Now the ASC(" ") is only evaluated once and the loop is executed faster.

GOTO and GOSUB

When EhBASIC encounters a GOTO or GOSUB it has to search through memory for the target line. If the target line follows the command then it searches from the next line, if the target line precedes the command then the search starts from the beginning of program memory. So keeping this distance, in lines, as short as possible will make the program run faster.

One place that this is difficult is in a conditional loop. In calculating points in the Mandelbrot set, for example, code like this is used ..

230 INC it

235 tp = mx*mx-my*my+x

240 my = 2*mx*my+y

245 mx = tp

250 co = (mx*mx + my*my)

255 IF (it<128) AND (co<4.0) THEN 230 .

Each time the condition in line 255 is met the interpreter has to search from the start of memory for line 230. While this may not take long if the program is short it can slow longer programs considerably.

This can easily be resolved though by using a DO .. LOOP instead. So our example code becomes..

220 DO

230 INC it

235 tp = mx*mx-my*my+x

240 my = 2*mx*my+y

245 mx = tp

250 co = (mx*mx + my*my)

255 LOOP WHILE (it<128) AND (co<4.0) .

This is quicker because the location of the start of the loop, the DO, is placed on the stack and the interpreter doesn't have to search for it.

Packing them in.

Another way to speed up time critical code is to place as many commands as possible on each line, this can make a noticeable speed gain.

E.g.

10 a1 = $F400 .

130 sp = ASC(" ")

140 FOR x = 0 to 79 : POKE a1+x,sp : NEXT .

INC and DEC.

INCrement and DECrement are quick and clear ways of altering a numeric value by plus or minus one and are faster than using add or subtract.

E.g.

100 INC a

.. is quicker than ..

100 a = a+1

.. and ..

100 INC a,a

.. is still quicker than ..

100 a = a+2

Also combine increments or decrements if you can.

E.g.

100 INC so,d

.. is quicker than ..

100 INC so : INC de

>> and <<

Using >> and << can be quicker than using / or * where integer math and a power of two is involved.

E.g. you want to find the byte that holds the pixel at x,y in a 256 x 32 display

100 ad = y*32 + INT(x/8) : REM pixel address

.. is done quicker with.

100 ad = y<<5 + x>>3 : REM pixel address

Coding for space

Most of the techniques used to improve the speed of a program can also reduce the number of bytes used by that program.

Spaces.

Remove spaces from your code. The only space you don't need to worry about is the one between the line number and the code as this is stripped during input parsing and the apparent space is generated by the LIST command output.

Removing REM.

Remove remarks from your code. Remarks like spaces don't do anything, removing remarks, can save a lot of space.

Variables.

Use variables. Often you will find yourself using the same numeric value again and again. If this value has many digits, such as the value for e (2.718282), then assigning that value at the beginning of the program can start to save space with the third use.

Re-use variables. Every time you assign a new variable a value it takes up six more bytes of the available memory. If you have a variable that is only used as a loop counter then try to use it for temporary values or GET values elsewhere in the program.

Constants.

There are two constants defined in EhBASIC, PI and TWOPI. They are the closest floating values to pi and 2*pi and will save you seven bytes each time you can use them.

Packing them in.

Another way to save space is to place as many commands as possible on each line, this will save you five bytes every time you put another command on an existing line compared to using a new line.

INC and DEC.

INCrement and DECrement also save space. Either will save you three bytes for each variable INCremented or DECremented.

Derived functions

The following functions, while not part of BASIC, can be calculated using the existing BASIC functions.

Secant | SEC(X)=1/COS(X)
Cosecant | CSC(X)=1/SIN(X)
Cotangent | COT(X)=1/TAN(X)
Inverse sine | ARCSIN(X)=ATN(X/SQR(X*X+1))
Inverse cosine | ARCCOS(X)=-ATN(X/SQR(X*X+1))+PI/2
Inverse secant | ARCSEC(X)=ATN(SQR(X*X-1))+(SGN(X)-1)*PI/2
Inverse cosecant | ARCCSC(X)=ATN(1/SQR(X*X-1))+(SGN(X)- 1)*PI/2
Inverse cotangent | ARCCOT(X)=-ATN(X)+PI/2
Hyperbolic sine | SINH(X)=(EXP(X)-EXP(-X))/2
Hyperbolic cosine | COSH(X)=(EXP(X)+EXP(-X))/2
Hyperbolic tangent | TANH(X)=-EXP(-X)/(EXP(X)+EXP(-X))*2+1
Hyperbolic secant | SECH(X)=2/(EXP(X)+EXP(-X))
Hyperbolic cosecant | CSCH(X)=2/(EXP(X)-EXP(-X))
Hyperbolic cotangent | COTH(X)=EXP(-X)/(EXP(X)-EXP(-X))*2+1
Inverse hyperbolic sine | ARCSINH(X)=LOG(X+SQR(X*X+1))
Inverse hyperbolic cosine | ARCCOSH(X)=LOG(X+SQR(X*X-1))
Inverse hyperbolic tangent | ARCTANH(X)=LOG((1+X)/(X))/2
Inverse hyperbolic secant | ARCSECH(X)=LOG((SQR(X*X+1)+1)/X)
Inverse hyperbolic cosecant | ARCCSCH(X)=LOG((SGN(X)*SQR(X*X+1)+1)/X)
Inverse hyperbolic cotangent | ARCCOTH(X)=LOG((X+1)/(X-1))/2

## Enhanced BASIC, extending CALL

Introduction.

CALL <address> calls a machine code routine at location address. While this in itself is useful it can be extended by adding parameters to the CALL and parsing them from within the routine.

This technique can also be used to pass extra parameters to the USR() function.

How to.

First you need to define the parameters for your CALL. This example is for an imaginary bitmapped graphic device.

CALL PLOT,x,y Set the pixel at x,y

PLOT routine address

x x axis value, range 0 to 255

y y axis value, range 0 to 64

This will then be the form that the call will always take.

Now you need to write the code.

.include BASIC.DIS ; include the BASIC labels file. this allows you

; easy access to the internal routines you need

; to parse the command stream and access some of

; the internals of BASIC. It is usually output ; by the assembler as part of the listing or as a ; separate, optional, file.

; for now we'll put this in the spare RAM @ $F400

*= $F400

PLOT

JSR LAB_SCGB ; scan for "," and get byte

STX PLOT_XBYT ; save plot x

JSR LAB_SCGB ; scan for "," and get byte

CPX #$40 ; compare with max+1

BCS PLOT_FCER ; if 64d or greater do function call error

STX PLOT_YBYT ; save plot y

; now would be your code to perform the plot command

;.

;.

;.

;.

;.

RTS ; return to BASIC

; does BASIC function call error

PLOT_FCER

JMP LAB_FCER ; do function call error, then warm start

; now we just need the variable storage

PLOT_XBYT

.byte $00 ; set default

PLOT_YBYT

.byte $00 ; set default

END

Finally you need to set the value of PLOT in your BASIC program and use that to call it.

E.g.

10 PLOT = $F400

145 CALL PLOT,25,14 : REM set pixel .

## Enhanced BASIC, using USR()

Introduction.

USR(<expression[$]>) calls the machine code function pointed to by the user jump vector after evaluating <expression[$]> and placing the result in the first floating accumulator. Once the user function exits, via an RTS, the value in the floating accumulator is passed back to EhBASIC.

Either a numeric value or a string can be passed, and either type can be returned depending on the setting of the data type flag at the end of the user code and the return point (see code examples for details).

It can also be extended by adding parameters to USR() and parsing them from within the routine in the same way that CALL can be extended, just remember to get the value from FAC1 first.

How to - numeric source, numeric result.

First you need to write the code.

; this code demonstrates the use of USR() to quickly calculate the square of a

; byte value. Compare this with doing SQ=A*A or even SQ=A^2.

.include BASIC.DIS ; include the BASIC labels file. this allows

; you easy access to the internal routines you

; need to parse the command stream and access

; some of the internals of BASIC. It is usually ; output by the assembler as part of the listing ; or as a separate, optional, file.

; for now we'll put this in the spare RAM @ $F400

*= $F400

Square

JSR LAB_EVBY ; evaluate byte expression, result in X and FAC1_3

LDA #$00 ; clear A

STA FAC1_2 ; clear square low byte (use FAC1 as the workspace)

; (no need to clear the high byte, it gets shifted out)

TXA ; copy byte to A

LDX #$08 ; set bit count

Nextr2bit

ASL FAC1_2 ; low byte *2

ROL FAC1_1 ; high byte *2+carry from low
ASL | A | ; shift byte
BCC | NoSqadd | ; don't do add if C = 0
TAY | | ; save A
CLC | | ; clear carry for add
LDA | FAC1_3 | ; get number
ADC | FAC1_2 | ; add number^2 low byte
STA | FAC1_2 | ; save number^2 low byte
LDA | #$00 | ; clear A
ADC | FAC1_1 | ; add number^2 high byte
STA | FAC1_1 | ; save number^2 high byte
TYA | | ; get A back
NoSqadd DEX | | ; decrement bit count
BNE | Nextr2bit | ; go do next bit
LDX | #$90 | ; set exponent=2^16 (integer)
SEC | | ; set carry for positive result
JMP | LAB_STFA | ; set exp=X, clearFAC1 mantissa3, normalise & return

Now you need to set up the address for your function. This is done by DOKEing an address into the USR() vector e.g.

DOKE $0B,$F400 | ; set the user function address to addr ; $0B - user function vector address ; $F400 - routine address

Finally you need to set the vector in your BASIC program and use that to call the function

10 DOKE $0B,$F400

145 SQ=USR(A) .

How to - numeric source, string result.

AS before, first you need to write the code.

; this code demonstrates the use of USR() to generate a string of # characters.

; the length of the required string is the parameter passed.

.include BASIC.DIS ; include the BASIC labels file. this allows

; you easy access to the internal routines you

; need to parse the command stream and access

; some of the internals of BASIC. It is usually ; output by the assembler as part of the listing ; or as a separate, optional, file.

; for now we'll put this in the spare RAM @ $F400

*= $F400

STRING

JSR LAB_EVBY ; evaluate byte expression, result in X and FAC1_3

TXA ; string is byte length

BEQ | NUL_STRN | ; branch if null string
JSR | LAB_MSSP | ; make string space A bytes long A=$AC=length, ; X=$AD=Sutill=ptr low byte, ; Y=$AE=Sutilh=ptr high byte
LDA | #"#" | ; set character
LDY | FAC1_3 | ; get length
SAV_HASH DEY | | ; decrement bytes to do
STA | (str_pl),Y | ; save byte in string
BNE | SAV_HASH | ; loop if not all done
NUL_STRN PLA | | ; dump return address (return via get value
PLA | | ; from line, this skips the type checking and ; so allows a string result to be returned)
JMP | LAB_RTST | ; check for space on descriptor stack then put ; string address and length on descriptor stack ; & update stack pointers

Now you need to set up the address for your function. This is done by DOKEing an address into the USR() vector e.g.

DOKE $0B,$F400 | ; set the user function address to addr ; $0B - user function vector address ; $F400 - routine address

Finally you need to set the vector in your BASIC program and use that to call the function

10 DOKE $0B,$F400

145 HA$=USR(A) .

How to - string source, numeric result.

AS before, first you need to write the code.

; this code demonstrates the use of USR() to test a string of characters.

; if all the string is alpha -1 is returned, else 0 is returned.

.include BASIC.DIS ; include the BASIC labels file. this allows

; you easy access to the internal routines you

; need to parse the command stream and access

; some of the internals of BASIC. It is usually ; output by the assembler as part of the listing ; or as a separate, optional, file.

; for now we'll put this in the spare RAM @ $F400

*= $F400

ALPHA

JSR LAB_EVST ; evaluate string

TAX | | ; copy length to X
BEQ | NOT_ALPH | ; branch if null string
LDY | #$00 | ; clear index
ALP_LOOP LDA | (ut1_pl),Y | ; get byte from string
JSR | LAB_CASC | ; is character "a" to "z" (or "A" to "Z")
BCC | NOT_ALPH | ; branch if not alpha
INY | | ; increment index
DEX | | ; decrement count
BNE | ALP_LOOP | ; loop if not all done
LDA | #$FF | ; set for -1
BNE | IS_ALPHA | ; branch always
NOT_ALPH LDA | #$00 | ; set for 0
IS_ALPHA TAY | | ; copy byte
LDX | #$00 | ; clear byte
STX | Dtypef | ; clear data type flag, $00=numeric
JMP | LAB_AYFC | ; save & convert integer AY to FAC1 & return

Now you need to set up the address for your function. This is done by DOKEing an address into the USR() vector e.g.

DOKE $0B,$F400 | ; set the user function address to addr ; $0B - user function vector address ; $F400 - routine address

Finally you need to set the vector in your BASIC program and use that to call the function

10 DOKE $0B,$F400

145 AL=USR(A$) .

How to - string source, string result.

AS before, first you need to write the code.

; this code demonstrates the use of USR() invert the case of a string of

; characters. only alpha characters will be affected.

.include BASIC.DIS ; include the BASIC labels file. this allows

; you easy access to the internal routines you

; need to parse the command stream and access

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

; for now we'll put this in the spare RAM @ $F400

*= $F400

ALPHA JSR | LAB_EVST | ; evaluate string
STA | str_ln | ; set string length
STX | str_pl | ; set string pointer low byte
STY | str_ph | ; set string pointer high byte
TAX | | ; copy length to X
BEQ | NO_STRNG | ; branch if null string
LDY | #$00 | ; clear index
ALP_LOOP LDA | (ut1_pl),Y | ; get byte from string
JSR | LAB_CASC | ; is character "a" to "z" (or "A" to "Z")
BCC | NOT_ALPH | ; branch if not alpha
EOR | #$20 | ; toggle case
STA | (ut1_pl),Y | ; save byte back to string
NOT_ALPH INY | | ; increment index
DEX | | ; decrement count
BNE | ALP_LOOP | ; loop if not all done
NO_STRNG PLA | | ; dump return address (return via get value
PLA | | ; from line, this skips the type checking and ; so allows a string result to be returned)
JMP | LAB_RTST | ; check for space on descriptor stack then put ; string address and length on descriptor stack ; & update stack pointers

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

10 DOKE $0B,$F400

145 A$=USR(A$) .

## Enhanced BASIC internals

Floating point numbers.

Floating point numbers are stored in memory in four bytes. The format of the numbers is as follows.

Exponent | S | Mantissa 1 | Mantissa 2 | Mantissa 3

#### Exponent

This is the power of two to which the mantissa is to be raised. This number is biased to +$80 i.e. 2^0 is represented by $80, 2^1 by $81 etc. Zero is a special case and is used to represent the value zero for the whole of the number.

S

Sign bit. This bit (b7 of mantissa 1) is one if the number is negative.

#### Mantissa 1/2/3

This is the 24 bit mantissa of the number and is normalised to make the highest bit (b7 of mantissa 1) always one. So the absolute value of the mantissa varies between 0.5 and 0.9999999403954 . As we know that the highest bit is always one it is replaced by the sign bit in memory.

Example.

$82,$49,$0F,$DB = +3.14159274 nearest floating equivalent to pi

| |\--+---+- = 0.785398185 absolute value of mantissa | |

| \--------- = + b7 of mantissa 1 is zero

\------------- = x 2^2 = 4 mantissa to be multiplied by 4

Values represented in this way range between + and - 1.70141173x10^38

BASIC program memory use.

A BASIC program is stored in memory from Ram_base upwards. It's format is ..

$00 Start of program marker byte

.. then each BASIC program line which is stored as ..

start of next line pointer low byte start of next line pointer high byte

line number low byte line number high byte code byte(s)

$00 End of line marker byte

.. and finally ..

$00 End of program marker byte 1 $00 End of program marker byte 2

If there is no program in memory only the start and end marker bytes are present.

BASIC variables memory use.

After the program come the variables and function references, all six bytes long, which are stored as ..

1st character of variable or function name (+$80 if FN name)

2nd character of variable or function name (+$80 if string)

.. then for each type ..

Numeric String Function

Exponent String length BASIC execute pointer low byte

Sign (bit 7) + mantissa 1 String pointer low byte BASIC execute pointer high byte

Mantissa 2 String pointer high byte Function variable name 1st character

Mantissa 3 $00 Function variable name 2nd character

After the variables come the arrays, which are stored as ..

1st character of variable name

2nd character of variable name (+$80 if string) array size in bytes low byte (size includes this header) array size in bytes high byte number of dimensions

[dimension 3 size high byte] (lowest element is zero)

[dimension 3 size low byte]

[dimension 2 size high byte] (lowest element is zero)

[dimension 2 size low byte]

dimension 1 size high byte (lowest element is zero) dimension 1 size low byte

.. and then each element ..

Numeric String

Exponent String length

Sign (bit 7) + mantissa 1 String pointer low byte

Mantissa 2 String pointer high byte

Mantissa 3 $00

The elements of every array are stored in the order ..

index1 [0-n], index2 [0-n], index3 [0-n]

i.e. element (1,2,3) in an array of (3,4,5) would be the ..

1 + 1 + 2*(3+1) + 3*(3+1)*(4+1) = 70th element

(As array dimensions range from 0 to n element n will always be the (n+1)th element in memory.)

String placement in memory.

Strings are generally stored from the top of available RAM, Ram_top, working down, however if the interpreter encounters a line such as ..

100 A$ = "This is a string"

.. then the high/low pointer in the A$ descriptor will point to the string in program memory and will not make a copy of the string in the string memory.

String descriptors in BASIC.

A string descriptor is a three byte table that describes a string, it is of the format ..

base = string length base+1 = string pointer low byte base+2 = string pointer high byte

Stack use in BASIC.

GOSUB and DO both push on the stack ..

BASIC execute pointer high byte BASIC execute pointer low byte

current line high byte

current line low byte

command token (TK_GOSUB or TK_DO)

FOR pushes on the stack ..

BASIC execute pointer low byte

BASIC execute pointer high byte

FOR line high byte

FOR line low byte

TO value mantissa3

TO value mantissa2

TO value mantissa1

TO value exponent

STEP sign

STEP value mantissa3

STEP value mantissa2

STEP value mantissa1 STEP value exponent var pointer for FOR/NEXT high byte var pointer for FOR/NEXT low byte token for FOR (TK_FOR)

## Enhanced BASIC, useful routines

Introduction.

There are many subroutines within BASIC that can be useful if you wish to use your own assembly routines with it. Here are some of them with a brief description of their function. For full details see the source code.

Note that most, if not all, of these routines need EhBASIC to be initialised before they will work properly and can not be used in isolation from EhBASIC.

The routines.

#### LAB_IGBY

BASIC increment and get byte routine. gets the next byte from the BASIC command stream. If the byte is a numeric character then the carry flag will be set, if the byte is a termination byte, either null or a statement separator, then the zero flag will be set. Spaces in the command stream will automatically be ignored.

#### LAB_GBYT

BASIC get byte routine. Gets the current byte from the BASIC command stream but does not change the pointer. Otherwise the same as above.

LAB_COLD

Performs a cold start. BASIC is reset and all BASIC memory is cleared.

LAB_WARM

Performs a warm start. Execution is stopped and BASIC returns to immediate mode.

LAB_OMER

Do "Out of memory" error, then warm start. The same as error $0C below.

#### LAB_XERR

With X set, do error #X, then warm start.

X | Error | X | Error
$00 | NEXT without FOR | $02 | syntax
$04 | RETURN without GOSUB | $06 | out of data
$08 | function call | $0A | overflow
$0C | out of memory | $0E | undefined statement
$10 | array bounds | $12 | double dimension array
$14 | divide by 0 | $16 | illegal direct
$18 | type mismatch | $1A | long string
$1C | string too complex | $1E | continue error
$20 | undefined function | $22 | LOOP without DO

#### LAB_INLN

Print "? " and get BASIC input. Returns XY (low/high) as a pointer to the start of the input line. The input is null terminated.

#### LAB_SSLN

Search Basic for a line, the line number required is held in the temporary integer, from start of program memory. Returns carry set and a pointer to the line in Baslnl/Baslnh if found, if not it returns carry and a pointer to the next numbered line in Baslnl/Baslnh.

#### LAB_SHLN

Search Basic for temporary integer line number from AX. Same as above but starts the search from AX (low/high).

LAB_SNBS

Scan for next BASIC statement (: or [EOL]). Returns Y as index to : or [EOL] from (Bpntrl).

LAB_SNBL

Scan for next BASIC line. Same as above but only returns on [EOL].

LAB_REM

Perform REM, skip (rest of) line.

LAB_GFPN

Get fixed-point number into temporary integer.

LAB_CRLF

Print [CR]/[LF] to output device.

LAB_PRNA

Print character in A to output device.

#### LAB_GVAR

Get variable address. Returns a pointer to the variable in Lvarpl/h and sets the data type flag, $FF=string, $00=numeric.

#### LAB_EVNM

Evaluates an expression and checks the result is numeric, if not it does a type mismatch. The result of the expression is returned in FAC1.

LAB_CTNM

Check if source is numeric, else do type mismatch.

LAB_CTST

Check if source is string, else do type mismatch.

LAB_CKTM

Type match check, set carry for string, clear carry for numeric.

LAB_EVEX

Evaluate expression.

LAB_GVAL

Get numeric value from line. Returns the result in FAC1.

LAB_SCCA

Scan for the byte in A as the next byte. If so return here, else do syntax error then warm start.

LAB_SNER

Do syntax error, then warm start.

LAB_CASC

Check byte is alpha ("A" to "Z" or "a" to "z"), return carry clear if so.

LAB_EVIN

Evaluate integer expression. Return integer in FAC1_3/FAC1_2 (low/high).

LAB_EVPI

Evaluate positive integer expression.

LAB_EVIR

Evaluate integer expression, check is in range -32786 to 32767

LAB_FCER

Do function call error, then warm start.

#### LAB_CKRN

Check that the interpreter is not in immediate mode. If not then return, if so do illegal direct error.

LAB_GARB

Perform garbage collection routine.

LAB_EVST

Evaluate string.

LAB_ESGL

Evaluate string, return string length in Y.

LAB_SGBY

Scan and get byte parameter, return the byte in X.

#### LAB_GTBY

Get byte parameter and ensure numeric type, else do type mismatch error. Return the byte in X.

LAB_EVBY

Evaluate byte expression, return the byte in X.

#### LAB_GADB

Get two parameters as in POKE or WAIT. Return the byte (second parameter) in X and the integer (first parameter) in the temporary integer pair, Itempl/Itemph.

LAB_SCGB

Scan for "," and get byte, else do Syntax error then warm start. Return the byte in X.

#### LAB_F2FX

New convert float to fixed routine. accepts any value that fits into 24 bits, positive or negative and converts it into a right truncated integer in the temporary integer pair, Itempl/Itemph.

LAB_UFAC

Unpack the four bytes starting (AY) into FAC1 as a floating point number.

LAB_PFAC

Pack the floating point number in FAC1 into the current variable (Lvarpl).

#### LAB_STFA

Stores a 16 bit number in FAC1. Set X to the exponent required (usually $90) and the carry set for positive numbers and clear for negative numbers. The routine will clear FAC1 mantissa3 and then normalise it.

#### LAB_AYFC

Save integer AY (A = high byte, Y = low byte) in FAC1 and convert to float. The result will be -32768 to +32767.

#### LAB_MSSP

Make string space A bytes long. This returns the following. str_ln = A = string length str_pl = Sutill = string pointer low byte str_ph = Sutilh = string pointer high byte

#### LAB_RTST

Return string. Takes the string described instr_ln, str_pl and str_ph and puts it on the string stack. This is how you return a string to BASIC.

## WE816 Hardware Reference

Using Supermon

The WE816 computer utilizes BCS Technology’s (http://sbc.bcstechnology.net/) Supermon 816 monitor program for its machine language monitor. To access Supermon, type ‘MONITOR’ from BASIC. You will be greeted by Supermon’s welcome screen.

__ _____ ___ __ __

/ /| ____|/ _ \/_ | / /

/ /_| |__ | (_) || |/ /_

| _ \___ \ > _ < | | _ \

| (_) |__) | (_) || | (_) |

\___/____/ \___/ |_|\___/

65c816 BIOS (NATIVE MODE)

v0.55 4/9/2021 - D.WERNER

PB PC NVmxDIZC .C .X .Y SP

F2 4F58 00110000 0000 0000 0000 7FFF

DP DB

0000 00

From the ‘.’ Prompt, you can enter any of Supermon’s commands.

- A Assemble code
- C Compare memory regions
- D Disassemble code
- F Fill memory region (cannot span banks)
- G Execute code (stops at BRK)
- H Search (hunt) memory
- J Execute code as a subroutine (stops at BRK or RTS)
- L Load Motorola S28-records
- M Dump & display memory range
- R Dump & display 65C816 registers
- T Copy (transfer) memory region
- > Modify up to 32 bytes of memory
- ; Modify 65C816 registers

Supermon 816 accepts binary (%), octal (@), decimal (+) and hexadecimal ($) as input for numeric parameters. Additionally, the H and > operations accept an ASCII string in place of numeric values by preceding the string with ', e.g.:

h 042000 042FFF 'BCS Technology Limited

If no radix symbol is entered hex is assumed.

Numeric conversion is also available. For example, typing:

+1234567 [CR]

at the monitor's prompt will display:

$12D687

+1234567

@04553207

%100101101011010000111

In the above example, [CR] means the console keyboard's return or enter key.

All numeric values are internally processed as 32 bit unsigned integers. Addresses may be entered as 8, 16 or 24 bit values. During instruction assembly immediate mode operands may be forced to 16 bits by preceding the operand with an exclamation point if the instruction can accept a 16 bit operand, e.g.:

a 1f2000 lda !#4

The above will assemble as:

A 1F2000 A9 04 00 LDA #$0004

Entering:

a 1f2000 ldx !#+157

will assemble as:

A 1F2000 A2 9D 00 LDX #$009D

Absent the ! in the operand field, the above would have been assembled as:

A 1F2000 A2 9D LDX #$9D

If an immediate mode operand is greater than $FF, assembly of a 16 bit operand is implied.

Redirecting Console to the Serial Port

The WE816 computer defaults console input/output to it’s built in keyboard and display, however it is possible to change the console display from internal to the serial port. Location $0341 in memory tells the computer which to use. If $341 contains a $01, the system will use the internal console, and value $00 designates the serial port.

To change the console using Supermon 816, enter:

>0341 00[ENTER]

And the system will change to the serial console. Entering:

>0341 01[ENTER]

Will change back to the internal video and keyboard.

Returning to BASIC

To return to BASIC from Supermon 816, just execute the “G” command with the address of the BASIC startup code.

G FF1000[ENTER]

## Screen Font

The following is the screen font for the WE816.


## Musical Note to “Frequencies”

value | Produced freq | note | Note freq | variance | out of tune
14 | 7990.313 | B8 | 7902.13 | -88.1825 | 1%
15 | 7457.625 | A8 | 7040 | -417.625 | 6%
16 | 6991.523 | G#8/Ab8 | 6644.88 | -346.643 | 5%
17 | 6580.257 | G8 | 6271.93 | -308.327 | 5%
18 | 6214.688 | F#8/Gb8 | 5919.91 | -294.778 | 5%
20 | 5593.219 | F8 | 5587.65 | -5.56875 | 0%
21 | 5326.875 | E8 | 5274.04 | -52.835 | 1%
22 | 5084.744 | D#8/Eb8 | 4978.03 | -106.714 | 2%
23 | 4863.668 | D8 | 4698.63 | -165.038 | 3%
25 | 4474.575 | C#8/Db8 | 4434.92 | -39.655 | 1%
26 | 4302.476 | C8 | 4186.01 | -116.466 | 3%
28 | 3995.156 | B7 | 3951.07 | -44.0862 | 1%
29 | 3857.392 | A#7/Bb7 | 3729.31 | -128.082 | 3%
31 | 3608.528 | A7 | 3520 | -88.5282 | 2%
33 | 3389.83 | G#7/Ab7 | 3322.44 | -67.3895 | 2%
37 | 3023.361 | F#7/Gb7 | 2959.96 | -63.4015 | 2%
42 | 2663.438 | E7 | 2637.02 | -26.4175 | 1%
44 | 2542.372 | D#7/Eb7 | 2489.02 | -53.3522 | 2%
47 | 2380.093 | D7 | 2349.32 | -30.7731 | 1%
50 | 2237.288 | C#7/Db7 | 2217.46 | -19.8275 | 1%
53 | 2110.649 | C7 | 2093 | -17.6486 | 1%
56 | 1997.578 | B6 | 1975.53 | -22.0481 | 1%
59 | 1896.006 | A#6/Bb6 | 1864.66 | -31.3464 | 2%
63 | 1775.625 | A6 | 1760 | -15.625 | 1%
67 | 1669.618 | G#6/Ab6 | 1661.22 | -8.39754 | 1%
71 | 1575.555 | G6 | 1567.98 | -7.57458 | 0%
75 | 1491.525 | F#6/Gb6 | 1479.98 | -11.545 | 1%
84 | 1331.719 | E6 | 1318.51 | -13.2088 | 1%
89 | 1256.903 | D#6/Eb6 | 1244.51 | -12.3931 | 1%
95 | 1177.52 | D6 | 1174.66 | -2.85974 | 0%
100 | 1118.644 | C#6/Db6 | 1108.73 | -9.91375 | 1%
106 | 1055.324 | C6 | 1046.5 | -8.82429 | 1%
113 | 989.9502 | B5 | 987.77 | -2.18022 | 0%
119 | 940.0368 | A#5/Bb5 | 932.33 | -7.70676 | 1%
127 | 880.8219 | A5 | 880 | -0.82185 | 0%
134 | 834.8088 | G#5/Ab5 | 830.61 | -4.19877 | 1%
142 | 787.7773 | G5 | 783.99 | -3.78729 | 0%
151 | 740.8237 | F#5/Gb5 | 739.99 | -0.83368 | 0%
160 | 699.1523 | F5 | 698.46 | -0.69234 | 0%
169 | 661.9194 | E5 | 659.25 | -2.66938 | 0%
179 | 624.9406 | D#5/Eb5 | 622.25 | -2.69064 | 0%
190 | 588.7599 | D5 | 587.33 | -1.42987 | 0%
201 | 556.5392 | C#5/Db5 | 554.37 | -2.16918 | 0%
213 | 525.1849 | C5 | 523.25 | -1.93486 | 0%
226 | 494.9751 | B4 | 493.88 | -1.09511 | 0%
239 | 468.0518 | A#4/Bb4 | 466.16 | -1.89178 | 0%
254 | 440.4109 | A4 | 440 | -0.41093 | 0%
269 | 415.8527 | G#4/Ab4 | 415.3 | -0.5527 | 0%
285 | 392.5066 | G4 | 392 | -0.50658 | 0%
302 | 370.4118 | F#4/Gb4 | 369.99 | -0.42184 | 0%
339 | 329.9834 | E4 | 329.63 | -0.35341 | 0%
359 | 311.5999 | D#4/Eb4 | 311.13 | -0.46993 | 0%
380 | 294.3799 | D4 | 293.66 | -0.71993 | 0%
403 | 277.5791 | C#4/Db4 | 277.18 | -0.39909 | 0%
427 | 261.9775 | C4 | 261.63 | -0.34746 | 0%
453 | 246.9412 | B3 | 246.94 | -0.00123 | 0%
479 | 233.5373 | A#3/Bb3 | 233.08 | -0.45732 | 0%
508 | 220.2055 | A3 | 220 | -0.20546 | 0%
570 | 196.2533 | G3 | 196 | -0.25329 | 0%
604 | 185.2059 | F#3/Gb3 | 185 | -0.20592 | 0%
640 | 174.7881 | F3 | 174.61 | -0.17809 | 0%
678 | 164.9917 | E3 | 164.81 | -0.1817 | 0%
719 | 155.5833 | D#3/Eb3 | 155.56 | -0.02328 | 0%
761 | 146.9966 | D3 | 146.83 | -0.16655 | 0%
807 | 138.6176 | C#3/Db3 | 138.59 | -0.02757 | 0%
855 | 130.8355 | C3 | 130.81 | -0.02553 | 0%
906 | 123.4706 | B2 | 123.47 | -0.00061 | 0%
959 | 116.6469 | A#2/Bb2 | 116.54 | -0.1069 | 0%
1016 | 110.1027 | A2 | 110 | -0.10273 | 0%
1077 | 103.8666 | G#2/Ab2 | 103.83 | -0.03664 | 0%
1141 | 98.04064 | G2 | 98 | -0.04064 | 0%
1209 | 92.52636 | F#2/Gb2 | 92.5 | -0.02636 | 0%
1281 | 87.32582 | F2 | 87.31 | -0.01582 | 0%
1357 | 82.43506 | E2 | 82.41 | -0.02506 | 0%
1438 | 77.79164 | D#2/Eb2 | 77.78 | -0.01164 | 0%
1523 | 73.45002 | D2 | 73.42 | -0.03002 | 0%
1614 | 69.30878 | C#2/Db2 | 69.3 | -0.00878 | 0%
1710 | 65.41776 | C2 | 65.41 | -0.00776 | 0%
1811 | 61.7694 | B1 | 61.74 | -0.0294 | 0%
1919 | 58.29306 | A#1/Bb1 | 58.27 | -0.02306 | 0%
2033 | 55.02429 | A1 | 55 | -0.02429 | 0%
2154 | 51.93332 | G#1/Ab1 | 51.91 | -0.02332 | 0%
2282 | 49.02032 | G1 | 49 | -0.02032 | 0%
2418 | 46.26318 | F#1/Gb1 | 46.25 | -0.01318 | 0%
2562 | 43.66291 | F1 | 43.65 | -0.01291 | 0%
2715 | 41.20235 | E1 | 41.2 | -0.00235 | 0%
2876 | 38.89582 | D#1/Eb1 | 38.89 | -0.00582 | 0%
3047 | 36.71296 | D1 | 36.71 | -0.00296 | 0%
3228 | 34.65439 | C#1/Db1 | 34.65 | -0.00439 | 0%
3420 | 32.70888 | C1 | 32.7 | -0.00888 | 0%
3623 | 30.87617 | B0 | 30.87 | -0.00617 | 0%
3838 | 29.14653 | A#0/Bb0 | 29.14 | -0.00653 | 0%
4067 | 27.50538 | A0 | 27.5 | -0.00538 | 0%

## Memory Map

Address (Decimal) | Address (Hex) | Label | Comment
0 | 00:0000 | LAB_WARM | BASIC warm start entry point
1 | 00:0001 | Wrmjpl | BASIC warm start vector jump low byte
2 | 00:0002 | Wrmjph | BASIC warm start vector jump high byte
4 | 00:0004 | TMPFLG | BASIC Temp area
6 | 00:0006 | VIDEOMODE | BASIC Current Video Mode
7 | 00:0007 | LOCALWORK | word (2 bytes)
10 | 00:000A | Usrjmp | USR function JMP address
11 | 00:000B | Usrjpl | USR function JMP vector low byte
12 | 00:000C | Usrjph | USR function JMP vector high byte
13 | 00:000D | Nullct | nulls output after each line
14 | 00:000E | TPos | BASIC terminal position byte
15 | 00:000F | TWidth | BASIC terminal width byte
16 | 00:0010 | Iclim | input column limit
17 | 00:0011 | Itempl | temporary integer low byte
18 | 00:0012 | Itemph | temporary integer high byte
17 | 00:0011 | nums_1 | number to bin/hex string convert MSB
18 | 00:0012 | nums_2 | number to bin/hex string convert
19 | 00:0013 | nums_3 | number to bin/hex string convert LSB
91 | 00:005B | Srchc | search character
91 | 00:005B | Temp3 | temp byte used in number routines
92 | 00:005C | Scnquo | scan-between-quotes flag
92 | 00:005C | Asrch | alt search character
91 | 00:005B | XOAw_l | eXclusive OR, OR and AND word low byte
92 | 00:005C | XOAw_h | eXclusive OR, OR and AND word high byte
93 | 00:005D | Ibptr | input buffer pointer
93 | 00:005D | Dimcnt | # of dimensions
93 | 00:005D | Tindx | token index
94 | 00:005E | Defdim | default DIM flag
95 | 00:005F | Dtypef | data type flag, $FF=string, $00=numeric
96 | 00:0060 | Oquote | open quote flag (b7) (Flag: DATA scan
96 | 00:0060 | Gclctd | garbage collected flag
97 | 00:0061 | Sufnxf | subscript/FNX flag, 1xxx xxx = FN(0xxx xxx)
98 | 00:0062 | Imode | input mode flag, $00=INPUT, $80=READ
99 | 00:0063 | Cflag | comparison evaluation flag
100 | 00:0064 | TabSiz | TAB step size (was input flag)
101 | 00:0065 | next_s | next descriptor stack address
| | | these two bytes form a word pointer to the item
| | | currently on top of the descriptor stack
102 | 00:0066 | last_sl | last descriptor stack address low byte
103 | 00:0067 | last_sh | last descriptor stack address high byte (always $00)
104 | 00:0068 | des_sk | descriptor stack start address (temp strings)
112 | 00:0070 | | End of descriptor stack
113 | 00:0071 | ut1_pl | utility pointer 1 low byte
114 | 00:0072 | ut1_ph | utility pointer 1 high byte
115 | 00:0073 | ut2_pl | utility pointer 2 low byte
116 | 00:0074 | ut2_ph | utility pointer 2 high byte
113 | 00:0071 | Temp_2 | temp byte for block move
117 | 00:0075 | FACt_1 | FAC temp mantissa1
118 | 00:0076 | FACt_2 | FAC temp mantissa2
119 | 00:0077 | FACt_3 | FAC temp mantissa3
118 | 00:0076 | dims_l | array dimension size low byte
119 | 00:0077 | dims_h | array dimension size high byte
120 | 00:0078 | TempB | temp page 0 byte
121 | 00:0079 | Smeml | start of mem low byte (Start-of-Basic)
122 | 00:007A | Smemh | start of mem high byte (Start-of-Basic)
123 | 00:007B | Svarl | start of vars low byte (Start-of-Variables)
124 | 00:007C | Svarh | start of vars high byte (Start-of-Variables)
125 | 00:007D | Sarryl | var mem end low byte (Start-of-Arrays)
126 | 00:007E | Sarryh | var mem end high byte (Start-of-Arrays)
127 | 00:007F | Earryl | array mem end low byte (End-of-Arrays)
128 | 00:0080 | Earryh | array mem end high byte (End-of-Arrays)
129 | 00:0081 | Sstorl | string storage low byte (String storage (moving down))
130 | 00:0082 | Sstorh | string storage high byte (String storage (moving down))
131 | 00:0083 | Sutill | string utility ptr low byte
132 | 00:0084 | Sutilh | string utility ptr high byte
133 | 00:0085 | Ememl | end of mem low byte (Limit-of-memory)
134 | 00:0086 | Ememh | end of mem high byte (Limit-of-memory)
135 | 00:0087 | Clinel | current line low byte (Basic line number)
136 | 00:0088 | Clineh | current line high byte (Basic line number)
137 | 00:0089 | Blinel | break line low byte (Previous Basic line number)
138 | 00:008A | Blineh | break line high byte (Previous Basic line number)
139 | 00:008B | Cpntrl | continue pointer low byte
140 | 00:008C | Cpntrh | continue pointer high byte
141 | 00:008D | Dlinel | current DATA line low byte
142 | 00:008E | Dlineh | current DATA line high byte
143 | 00:008F | Dptrl | DATA pointer low byte
144 | 00:0090 | Dptrh | DATA pointer high byte
145 | 00:0091 | Rdptrl | read pointer low byte
146 | 00:0092 | Rdptrh | read pointer high byte
147 | 00:0093 | Varnm1 | current var name 1st byte
148 | 00:0094 | Varnm2 | current var name 2nd byte
149 | 00:0095 | Cvaral | current var address low byte
150 | 00:0096 | Cvarah | current var address high byte
151 | 00:0097 | Frnxtl | var pointer for FOR/NEXT low byte
151 | 00:0097 | Tidx1 | temp line index
151 | 00:0097 | Lvarpl | let var pointer low byte
152 | 00:0098 | Frnxth | var pointer for FOR/NEXT high byte
152 | 00:0098 | Lvarph | let var pointer high byte
153 | 00:0099 | prstk | precedence stacked flag
155 | 00:009B | comp_f | compare function flag, bits 0,1 and 2 used
| | | bit 2 set if >
| | | bit 1 set if =
| | | bit 0 set if <
156 | 00:009C | func_l | function pointer low byte
157 | 00:009D | func_h | function pointer high byte
156 | 00:009C | garb_l | garbage collection working pointer low byte
157 | 00:009D | garb_h | garbage collection working pointer high byte
158 | 00:009E | des_2l | string descriptor_2 pointer low byte
159 | 00:009F | des_2h | string descriptor_2 pointer high byte
160 | 00:00A0 | g_step | garbage collect step size
161 | 00:00A1 | Fnxjmp | jump vector for functions
162 | 00:00A2 | Fnxjpl | functions jump vector low byte
162 | 00:00A2 | g_indx | garbage collect temp index
163 | 00:00A3 | Fnxjph | functions jump vector high byte
163 | 00:00A3 | FAC2_r | FAC2 rounding byte
164 | 00:00A4 | Adatal | array data pointer low byte
164 | 00:00A4 | Nbendl | new block end pointer low byte
165 | 00:00A5 | Adatah | array data pointer high byte
165 | 00:00A5 | Nbendh | new block end pointer high byte
166 | 00:00A6 | Obendl | old block end pointer low byte
167 | 00:00A7 | Obendh | old block end pointer high byte
168 | 00:00A8 | numexp | string to float number exponent count
168 | 00:00A8 | numbit | bit count for array element calculations
169 | 00:00A9 | expcnt | string to float exponent count
170 | 00:00AA | numdpf | string to float decimal point flag
170 | 00:00AA | Astrtl | array start pointer low byte
171 | 00:00AB | expneg | string to float eval exponent -ve flag
171 | 00:00AB | Astrth | array start pointer high byte
170 | 00:00AA | Histrl | highest string low byte
171 | 00:00AB | Histrh | highest string high byte
170 | 00:00AA | Baslnl | BASIC search line pointer low byte
171 | 00:00AB | Baslnh | BASIC search line pointer high byte
170 | 00:00AA | Fvar_l | find/found variable pointer low byte
171 | 00:00AB | Fvar_h | find/found variable pointer high byte
170 | 00:00AA | Ostrtl | old block start pointer low byte
171 | 00:00AB | Ostrth | old block start pointer high byte
170 | 00:00AA | Vrschl | variable search pointer low byte
171 | 00:00AB | Vrschh | variable search pointer high byte
172 | 00:00AC | FAC1_e | FAC1 exponent
173 | 00:00AD | FAC1_1 | FAC1 mantissa1
174 | 00:00AE | FAC1_2 | FAC1 mantissa2
175 | 00:00AF | FAC1_3 | FAC1 mantissa3
176 | 00:00B0 | FAC1_s | FAC1 sign (b7)
172 | 00:00AC | str_ln | string length
173 | 00:00AD | str_pl | string pointer low byte
174 | 00:00AE | str_ph | string pointer high byte
174 | 00:00AE | des_pl | string descriptor pointer low byte
175 | 00:00AF | des_ph | string descriptor pointer high byte
175 | 00:00AF | mids_l | MID$ string temp length byte
177 | 00:00B1 | negnum | string to float eval -ve flag
177 | 00:00B1 | numcon | series evaluation constant count
178 | 00:00B2 | FAC1_o | FAC1 overflow byte
179 | 00:00B3 | FAC2_e | FAC2 exponent
180 | 00:00B4 | FAC2_1 | FAC2 mantissa1
181 | 00:00B5 | FAC2_2 | FAC2 mantissa2
182 | 00:00B6 | FAC2_3 | FAC2 mantissa3
183 | 00:00B7 | FAC2_s | FAC2 sign (b7)
184 | 00:00B8 | FAC_sc | FAC sign comparison, Acc#1 vs #2
185 | 00:00B9 | FAC1_r | FAC1 rounding byte
184 | 00:00B8 | ssptr_l | string start pointer low byte
185 | 00:00B9 | ssptr_h | string start pointer high byte
184 | 00:00B8 | sdescr | string descriptor pointer
186 | 00:00BA | csidx | line crunch save index
186 | 00:00BA | Asptl | array size/pointer low byte
187 | 00:00BB | Aspth | array size/pointer high byte
186 | 00:00BA | Btmpl | BASIC pointer temp low byte
187 | 00:00BB | Btmph | BASIC pointer temp low byte
186 | 00:00BA | Cptrl | BASIC pointer temp low byte
187 | 00:00BB | Cptrh | BASIC pointer temp low byte
186 | 00:00BA | Sendl | BASIC pointer temp low byte
187 | 00:00BB | Sendh | BASIC pointer temp low byte
188 | 00:00BC | LAB_IGBY | get next BASIC byte subroutine
194 | 00:00C2 | LAB_GBYT | get current BASIC byte subroutine
195 | 00:00C3 | Bpntrl | BASIC execute (get byte) pointer low byte
196 | 00:00C4 | Bpntrh | BASIC execute (get byte) pointer high byte
197 | 00:00C5 | Bpntrp | BASIC execute (get byte) pointer PAGE byte
224 | 00:00E0 | | end of get BASIC char subroutine
225 | 00:00E1 | Rbyte4 | extra PRNG byte
226 | 00:00E2 | Rbyte1 | most significant PRNG byte
227 | 00:00E3 | Rbyte2 | middle PRNG byte
228 | 00:00E4 | Rbyte3 | least significant PRNG byte
229 | 00:00E5 | NmiBase | NMI handler enabled/setup/triggered flags
| | | bit function
| | | === ========
| | | 7 interrupt enabled
| | | 6 interrupt setup
| | | 5 interrupt happened
230 | 00:00E6 | | NMI handler addr low byte
231 | 00:00E7 | | NMI handler addr high byte
232 | 00:00E8 | IrqBase | IRQ handler enabled/setup/triggered flags
233 | 00:00E9 | | IRQ handler addr low byte
234 | 00:00EA | | IRQ handler addr high byte
235 | 00:00EB | FCBPTR | POINTER TO FCB FOR FILE OPS
239 | 00:00EF | Decss | number to decimal string start
240 | 00:00F0 | Decssp1 | number to decimal string start
253 | 00:00FD | TEMPW
255 | 00:00FF | | decimal string end
256-511 | 00:0100-00:01FF | 6502Stack | Left Free for 6502 Emulation Mode Stack
512-767 | 00:0200-00:02FF | KEYBUFF | 256 BYTE KEYBOARD BUFFER
| | | NATIVE VECTORS
768 | 00:0300 | ICOPVECTOR | COP handler indirect vector...
770 | 00:0302 | IBRKVECTOR | BRK handler indirect vector...
772 | 00:0304 | IABTVECTOR | ABT handler indirect vector...
774 | 00:0306 | INMIVECTOR | NMI handler indirect vector...
776 | 00:0308 | IIRQVECTOR | IRQ handler indirect vector...
| | | 6502 Emulation Vectors
778 | 00:030A | IECOPVECTOR | ECOP handler indirect vector...
780 | 00:030C | IEABTVECTOR | EABT handler indirect vector...
782 | 00:030E | IENMIVECTOR | ENMI handler indirect vector...
784 | 00:0310 | IEINTVECTOR | EINT handler indirect vector...
| | | IEC Driver work Area
786 | 00:0312 | IECDCF | Serial output: deferred char flag
787 | 00:0313 | IECDC | Serial deferred character
788 | 00:0314 | IECBCI | Serial bit count/EOI flag
789 | 00:0315 | IECBTC | Countdown, bit count
790 | 00:0316 | IECCYC | Cycle count
791 | 00:0317 | IECSTW | Status word
792 | 00:0318 | IECFNLN | File Name Length
793 | 00:0319 | IECSECAD | IEC Secondary Address
794 | 00:031A | IECBUFFL | low byte IEC buffer Pointer
795 | 00:031B | IECBUFFH | High byte IEC buffer Pointer
796 | 00:031C | IECDEVN | IEC Device Number
797 | 00:031D | IECSTRTL | low byte IEC Start Address Pointer
798 | 00:031E | IECSTRTH | High byte IEC Start Address Pointer
799 | 00:031F | IECMSGM | message mode flag,
| | | $C0 = both control and kernal messages,
| | | $80 = control messages only,
| | | $40 = kernal messages only,
| | | $00 = neither control or kernal messages
800 | 00:0320 | IECFNPL | File Name Pointer Low,
801 | 00:0321 | IECFNPH | File Name Pointer High,
802 | 00:0322 | LOADBUFL | low byte IEC buffer Pointer
803 | 00:0323 | LOADBUFH | High byte IEC buffer Pointer
804 | 00:0324 | LOADBANK | BANK buffer Pointer
805 | 00:0325 | IECOPENF | OPEN FILE COUNT
806 | 00:0326 | IECLFN | IEC LOGICAL FILE NUMBER
807 | 00:0327 | IECIDN | input device number
808 | 00:0328 | IECODN | output device number
| | | VIDEO/KEYBOARD PARAMETER WORK AREA
816 | 00:0330 | CSRX | CURRENT X POSITION
817 | 00:0331 | CSRY | CURRENT Y POSITION
818 | 00:0332 | LEDS | Current Keyboard LED status
819 | 00:0333 | KeyLock | Current Keylock status
820 | 00:0334 | ScannedKey | Current Scanned Key
821 | 00:0335 | ScrollCount | Current Scroll Count
822 | 00:0336 | TEMP | TEMP AREA
833 | 00:0341 | ConsoleDevice | Current Console Device
| | | $00 Serial, $01 On-Board 9918/KB
834 | 00:0342 | CSRCHAR | Character under the Cursor
835 | 00:0343 | VIDEOWIDTH | SCREEN WIDTH -- 32 or 40 (80 in the future)
848 | 00:0350 | ScrollBuffer | at least 80 bytes?
944 | 00:03B0 | PTRLFT | .. to $03B9 logical file table
954 | 00:03BA | PTRDNT | .. to $03C3 device number table
964 | 00:03C4 | PTRSAT | .. to $03CD secondary address table
976-1000 | 00:03D0-00:03E9 | LINEFLGS | 24 BYTES OF LINE POINTERS (3D0 - 3E9 , one ext
1001-32767 | 00:03F0-00:7FFF | | OPEN/STACK
32767 | 00:7FFF | STACK | TOP OF 65816 STACK
32768-65535 | 00:8000-00:FFFF | ROM
32768-37611 | 00:8000-00:92EB | SUPERMON | ROM: SUPERMON
57344-65535 | 00:e000-00:FFFF | BIOS | ROM: BIOS
| | | IO Area
65024 | 00:FE00 | UART0: | DATA IN/OUT
65025 | 00:FE01 | UART1: | CHECK RX
65026 | 00:FE02 | UART2: | INTERRUPTS
65027 | 00:FE03 | UART3: | LINE CONTROL
65028 | 00:FE04 | UART4: | MODEM CONTROL
65029 | 00:FE05 | UART5: | LINE STATUS
65030 | 00:FE06 | UART6: | MODEM STATUS
65034 | 00:FE0A | DATAP: | VDP Data port
65035 | 00:FE0B | CMDP: | VDP Command port
65040 | 00:FE10 | via1regb | Register (Sound Data)
65041 | 00:FE11 | via1rega | Register (IEC,RTC, & Sound)
| | | B0 - Serial Clock in
| | | B1- Serial Data in
| | | B2- Sound BDIR
| | | B3- Sound BC1
| | | B4- Sound BC2
| | | B5- RTC DQ
| | | B6- RTC RST
| | | B7 - Serial ATN Out
65042 | 00:FE12 | via1ddrb | Register
65043 | 00:FE13 | via1ddra | Register
65044 | 00:FE14 | via1t1cl | Register
65045 | 00:FE15 | via1t1ch | Register
65046 | 00:FE16 | via1t1ll | Register
65047 | 00:FE17 | via1t1lh | Register
65048 | 00:FE18 | via1t2cl | Register
65049 | 00:FE19 | via1t2ch | Register
65050 | 00:FE1A | via1sr | Register
65051 | 00:FE1B | via1acr | Register
65052 | 00:FE1C | via1pcr | Register
65053 | 00:FE1D | via1ifr | Register
65054 | 00:FE1E | via1ier | Register
65055 | 00:FE1F | via1ora | Register
65056 | 00:FE20 | via2regb | Register (KB ROW & LED control)
65057 | 00:FE21 | via2rega | Register (KB Column)
65058 | 00:FE22 | via2ddrb | Register
65059 | 00:FE23 | via2ddra | Register
65060 | 00:FE24 | via2t1cl | Register
65061 | 00:FE25 | via2t1ch | Register
65062 | 00:FE26 | via2t1ll | Register
65063 | 00:FE27 | via2t1lh | Register
65064 | 00:FE28 | via2t2cl | Register
65065 | 00:FE29 | via2t2ch | Register
65066 | 00:FE2A | via2sr | Register
65067 | 00:FE2B | via2acr | Register
65068 | 00:FE2C | via2pcr | Register
65069 | 00:FE2D | via2ifr | Register
65070 | 00:FE2E | via2ier | Register
65071 | 00:FE2F | via2ora | Register
| 01:0000-07:FFFF | RAM
| FF:0000-FF:FFFF | BASIC ROM
| | | BIOS Jump Table (Native Long JSR)
64768 | 00:FD00 | LPRINTVEC | Print a character to the active console
64772 | 00:FD04 | LINPVEC | Get a character from the active console (no wait)
64776 | 00:FD08 | LINPWVEC | Get a character from the active console (wait)
64780 | 00:FD0C | LSetXYVEC | Set the Cursor position on the 9918 screen
64784 | 00:FD10 | LCPYVVEC | Copy 9918 VRAM
64788 | 00:FD14 | LSrlUpVEC | Scroll up the 9918 Screen
64792 | 00:FD18 | LSetColorVEC | Set the Color for the 9918 Screen
64796 | 00:FD1C | LCURSORVEC | Turn on the 9918 Cursor
64800 | 00:FD20 | LUNCURSORVEC | Turn Off the 9918 Cursor
64804 | 00:FD24 | LWRITERTC | Write a RTC register
64808 | 00:FD28 | LREADRTC | Read a RTC register
64812 | 00:FD2C | LIECIN | Read byte from serial bus. (Must call TALK and TALKSA beforehands.)
64816 | 00:FD30 | LIECOUT | Write byte to serial bus. (Must call LISTEN and LSTNSA beforehands.)
64820 | 00:FD34 | LUNTALK | Send UNTALK command to serial bus.
64824 | 00:FD38 | LUNLSTN | Send UNLISTEN command to serial bus.
64828 | 00:FD3C | LLISTEN | Send LISTEN command to serial bus.
64832 | 00:FD40 | LTALK | Send TALK command to serial bus.
64836 | 00:FD44 | LSETLFS | Set file parameters.
64840 | 00:FD48 | LSETNAM | Set file name parameters.
64844 | 00:FD4C | LLOAD | Load or verify file. (Must call SETLFS and SETNAM beforehand.)
64848 | 00:FD50 | LSAVE | Save file. (Must call SETLFS and SETNAM beforehand.)
64852 | 00:FD54 | LIECINIT | INIT IEC
64856 | 00:FD58 | LIECCLCH | close input and output channels
64860 | 00:FD5C | LIECOUTC | open a channel for output
64864 | 00:FD60 | LIECINPC | open a channel for input
64868 | 00:FD64 | LIECOPNLF | open a logical file
64872 | 00:FD68 | LIECCLSLF | close a specified logical file
64876 | 00:FD6C | LClearScrVec | clear the 9918 Screen
64880 | 00:FD70 | LLOADFONTVec | LOAD THE FONT
| | | BIOS Jump Table (Emulation, short JSR)
65393 | 00:FF71 | PRINTVEC | Print a character to the active console
65396 | 00:FF74 | INPVEC | Get a character from the active console (no wait)
65399 | 00:FF77 | INPWVEC | Get a character from the active console (wait)
65402 | 00:FF7A | SetXYVEC | Set the Cursor position on the 9918 screen
65405 | 00:FF7D | CPYVVEC | Copy 9918 VRAM
65408 | 00:FF80 | SrlUpVEC | Scroll up the 9918 Screen
65411 | 00:FF83 | SetColorVEC | Set the Color for the 9918 Screen
65414 | 00:FF86 | CURSORVEC | Turn on the 9918 Cursor
65417 | 00:FF89 | UNCURSORVEC | Turn Off the 9918 Cursor
65420 | 00:FF8C | WRITERTC | Write a RTC register
65423 | 00:FF8F | READRTC | Read a RTC register
65426 | 00:FF92 | IECIN | Read byte from serial bus. (Must call TALK and TALKSA beforehands.)
65429 | 00:FF95 | IECOUT | Write byte to serial bus. (Must call LISTEN and LSTNSA beforehands.)
65432 | 00:FF98 | UNTALK | Send UNTALK command to serial bus.
65435 | 00:FF9B | UNLSTN | Send UNLISTEN command to serial bus.
65438 | 00:FF9E | LISTEN | Send LISTEN command to serial bus.
65441 | 00:FFA1 | TALK | Send TALK command to serial bus.
65444 | 00:FFA4 | SETLFS | Set file parameters.
65447 | 00:FFA7 | SETNAM | Set file name parameters.
65450 | 00:FFAA | LOAD | Load or verify file. (Must call SETLFS and SETNAM beforehand.)
65453 | 00:FFAD | SAVE | Save file. (Must call SETLFS and SETNAM beforehand.)
65456 | 00:FFB0 | IECINIT | INIT IEC
65459 | 00:FFB3 | IECCLCH | close input and output channels
65462 | 00:FFB6 | IECOUTC | open a channel for output
65465 | 00:FFB9 | IECINPC | open a channel for input
65468 | 00:FFBC | IECOPNLF | open a logical file
65471 | 00:FFBF | IECCLSLF | close a specified logical file
65474 | 00:FFC2 | ClearScrVec | clear the 9918 Screen
65477 | 00:FFC5 | LOADFONTVec | LOAD THE FONT
| | VRAM Memory Map
0-1023 | $0000-$03FF | | Sprite Patterns
1024-1983 | $0400-$07BF | | Screen Memory ($06FF for Graphics Modes)
1792-2047 | $0700-$07FF | | Sprite Attributes
2048-8191 | $0800-$1FFF | | Patterns
8192-16385 | $2000-$3FFF | | Color Memory

EhBASIC reference manual page 10

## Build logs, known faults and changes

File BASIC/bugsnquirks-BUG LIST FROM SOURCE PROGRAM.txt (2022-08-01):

EhBASIC 2.22 has a few bugs and quirks that you should know about.

1. The interrupt system is severely broken.

When an IRQ occurs and IRQ_vec is called in min_mon.asm the interrupt is only
registered with IRQbase but the interrupt source is not serviced nor is the
interrupt disable bit set at RTI. As a consequence the interrupt is immediately
called again and again and IRQbase is trashed until the interrupt is serviced
by the ON IRQ handler in basic.

The problem is discussed in http://forum.6502.org/viewtopic.php?f=5&t=2411
How I solved the problem for my emulator:
https://github.com/Klaus2m5/AVR_emulated_6502_4SBC/tree/master/EhBASIC

However, you should keep in mind that the interrupt service capacity in EhBASIC
is very limited. In a 2MHz system more than 100 interrupts per second or
interrupts requiring less than 10ms service time should be handled in machine
language. The numbers are worse if the interrupt handler gets more complex.

Of course, a hybrid solution is always possible. You could service the interrupt
in machine language and flag an interrupt to basic only after a buffer is
filled/emptied or a count is reached.

2. String handling when the string is in the input buffer.
fixed in 2.22p3

When a string is entered via the input buffer (Ibuffs - Ibuffe) in Ehbasic it
is transient because it gets overwritten by the next input. In this case it
needs to be copied to the string area. In all other cases the string remains in
place and only a pointer needs to be set to the string location. 

There is a bug in EhBASIC to determine where the string is.

!! The original version of this patch broke the number to string conversion as
in STR$(). Github user mgcaret provided a fix included in version 2 !! 

LAB_20DC
      STX   Sendh             ; save string end high byte
      LDA   ssptr_h           ; get string start high byte
      CMP   #>Ram_base        ; compare with start of program memory
      BCS   LAB_RTST          ; branch if not in utility area
This does not work, if RAM_base is below the input buffer or EhBASIC itself is
below RAM_base. The fix requires the input buffer not to cross a page boundary:

LAB_20DC
      STX   Sendh             ; save string end high byte
      LDA   ssptr_h           ; get string start high byte
; *** begin RAM above code / Ibuff above EhBASIC patch V2 ***
; *** replace
;      CMP   #>Ram_base        ; compare with start of program memory
;      BCS   LAB_RTST          ; branch if not in utility area
; *** with
      BEQ   LAB_MVST          ; fix STR$() using page zero via LAB_296E
      CMP   #>Ibuffs          ; compare with location of input buffer page
      BNE   LAB_RTST          ; branch if not in utility area
LAB_MVST
; *** end   RAM above code / Ibuff above EhBASIC patch V2 ***

3. Output of some functions limited to integers is negative.

This is not a bug but documented behavior.

Affected functions FRE(), SADD(), VARPTR(), DEEK()

If you want to use FRE() with large RAM you must write:

? FRE(0)-(FRE(0)<0)*$10000

If you really want to deviate from the beaten path, you can add a routine to
convert unsigned integers and jump to it from the functions that you want to
respond with an unsigned number. It replaces LAB_AYFC for these functions.

; save and convert unsigned integer AY to FAC1
LAB_UAYFC
      LSR   Dtypef            ; clear data type flag, $FF=string, $00=numeric
      STA   FAC1_1            ; save FAC1 mantissa1
      STY   FAC1_2            ; save FAC1 mantissa2
      LDX   #$90              ; set exponent=2^16 (integer)
      SEC                     ; always positive
      JMP   LAB_STFA          ; set exp=X, clear FAC1_3, normalise and return
      
You cannot apply this routine to operators which also use LAB_AYFC (=, OR, AND
EOR <<, >>) as they require signed integers. The value -1 is asigned to a
comparison evaluating as TRUE. Therefore logical operators must be able to
evaluate -1 correctly.

4. Use of decimal mode and invalid BCD
fixed in 2.22p

There is only one place in EhBASIC where decimal mode is used. HEX$() uses
invalid BCD to convert a number to a hexadecimal string. Some processors do not
support decimal mode and emulators most of the time will not support invalid
BCD (nibbles in the range of $A - $F). 

LAB_AL2X
      CMP   #$0A              ; set carry for +1 if >9
      ADC   #'0'              ; add ASCII "0"
      STA   (str_pl),Y        ; save to temp string
      DEY                     ; decrement counter
      RTS

A patch is available to disable use of decimal mode in EhBASIC.

LAB_AL2X
      CMP   #$0A              ; set carry for +1 if >9
; *** begin disable decimal mode patch ***
; *** insert
      BCC   LAB_AL20          ; skip adjust if <= 9
      ADC   #$06              ; adjust for A to F
LAB_AL20
; *** end   disable decimal mode patch ***
      ADC   #'0'              ; add ASCII "0"
      STA   (str_pl),Y        ; save to temp string
      DEY                     ; decrement counter
      RTS
      
At the same time you must disable SED & CLD at the HEX$() function.

LAB_HEXS
      CPX   #$07              ; max + 1
      BCS   BinFErr           ; exit if too big ( > or = )

      STX   TempB             ; save # of characters

      LDA   #$06              ; need 6 bytes for string
      JSR   LAB_MSSP          ; make string space A bytes long
      LDY   #$05              ; set string index

; *** disable decimal mode patch - comment next line ***
;      SED                     ; need decimal mode for nibble convert
      LDA   nums_3            ; get lowest byte
      JSR   LAB_A2HX          ; convert A to ASCII hex byte and output
      LDA   nums_2            ; get middle byte
      JSR   LAB_A2HX          ; convert A to ASCII hex byte and output
      LDA   nums_1            ; get highest byte
      JSR   LAB_A2HX          ; convert A to ASCII hex byte and output
; *** disable decimal mode patch - comment next line ***
;      CLD                     ; back to binary

5. Ibuffs located at $xx00
fixed in 2.22p

If the input buffer is located at the beginning of a page then any direct
statement (RUN, LIST, ...) is read from Ibuffs-$100 resulting in unexpected
behavior of EhBASIC.

A patch is available from Daryl Rictor. I took the freedom to add conditional
assembly.

LAB_142A
      INY                     ; increment pointer
      INY                     ; increment pointer (makes it next line pointer high byte)
      STA   Ibuffs,Y          ; save [EOL] (marks [EOT] in immediate mode)
      INY                     ; adjust for line copy
      INY                     ; adjust for line copy
      INY                     ; adjust for line copy
; *** begin patch for when Ibuffs is $xx00 - Daryl Rictor ***
; *** insert
      .IF   Ibuffs&$FF==0
      LDA   Bpntrl            ; test for $00
      BNE   LAB_142P          ; not $00
      DEC   Bpntrh            ; allow for increment when $xx00
LAB_142P
      .ENDIF
; *** end   patch for when Ibuffs is $xx00 - Daryl Rictor ***
; end of patch
      DEC   Bpntrl            ; allow for increment
      RTS

The conditional in the patch above requires Ibuffs to be known at pass 1 during
assembly. The standard definition of Ibuffs does not satisfy this requirement.
We need to replace it like below:

; Ibuffs can now be anywhere in RAM, ensure that the max length is < $80,
; the input buffer must not cross a page boundary and must not overlap with
; program RAM pages!

;Ibuffs            = IRQ_vec+$14
Ibuffs            = VEC_SV+$16
                              ; start of input buffer after IRQ/NMI code
Ibuffe            = Ibuffs+$47; end of input buffer

6. First statement after direct mode does not set the continue pointer
fixed in 2.22p2

After a RUN or GOTO in direct mode CONT does not work for the first statement in
run mode. It throws a "Can't continue error". If that first statement is INPUT
then "Redo from start" causes a subsequent syntax error.

It is actually a hen and egg problem as the continue pointer (Cpntrh/l) is saved
during the inner loop if not in direct mode, but direct mode (Clineh = $FF) is
only cleared later in the same loop.

The fix is in the patched folder (version 2.22p2). The continue counter is now
always saved and the decision to continue is postponed until the CONT statement
is executed and based on the fact that the continue pointer must not point to
the input buffer in run mode.

LAB_1491
      LDX   #des_sk           ; set descriptor stack pointer
      STX   next_s            ; save descriptor stack pointer
      PLA                     ; pull return address low byte
      TAX                     ; copy return address low byte
      PLA                     ; pull return address high byte
      STX   LAB_SKFE          ; save to cleared stack
      STA   LAB_SKFF          ; save to cleared stack
      LDX   #$FD              ; new stack pointer
      TXS                     ; reset stack
      LDA   #$00              ; clear byte
;*** fix p2: no longer necessary as the continue pointer is saved anyway
;      STA   Cpntrh            ; clear continue pointer high byte
      STA   Sufnxf            ; clear subscript/FNX flag
.........................................................................
LAB_15C2
      JSR   LAB_1629          ; do CRTL-C check vector
      LDA   Bpntrl            ; get BASIC execute pointer low byte
      LDY   Bpntrh            ; get BASIC execute pointer high byte

      LDX   Clineh            ; continue line is $FFxx for immediate mode
                              ; ($00xx for RUN from immediate mode)
      INX                     ; increment it (now $00 if immediate mode)
;*** fix p2: skip no longer necessary as the continue pointer is saved anyway
;      BEQ   LAB_15D1          ; branch if null (immediate mode)

      STA   Cpntrl            ; save continue pointer low byte
      STY   Cpntrh            ; save continue pointer high byte
.........................................................................
LAB_163B
      BNE   LAB_167A          ; if wasn't CTRL-C or there is a following byte return

      LDA   Bpntrh            ; get the BASIC execute pointer high byte
;*** fix p2: skip no longer necessary as the continue pointer is saved anyway
;      EOR   #>Ibuffs          ; compare with buffer address high byte (Cb unchanged)
;      BEQ   LAB_164F          ; branch if the BASIC pointer is in the input buffer
;                              ; (can't continue in immediate mode)
;                              ; else ..
;      EOR   #>Ibuffs          ; correct the bits
      LDY   Bpntrl            ; get BASIC execute pointer low byte
.........................................................................
LAB_CONT
      BNE   LAB_167A          ; if following byte exit to do syntax error

      LDY   Cpntrh            ; get continue pointer high byte
      CPY   #>Ibuffs          ; *** fix p2: test direct mode
      BNE   LAB_166C          ; go do continue if we can
.........................................................................
LAB_1934
      JSR   LAB_CKRN          ; check not Direct, back here if ok
      JSR   LAB_INLN          ; print "? " and get BASIC input
      LDA   #$00              ; set mode = INPUT
      CMP   Ibuffs            ; test first byte in buffer
      BNE   LAB_1953          ; branch if not null input

; *** change p2: keep carry set to throw break message
;      CLC                     ; was null input so clear carry to exit program
      JMP   LAB_1647          ; go do BREAK exit

7. String compare of equal strings in direct mode returns FALSE
fixed in 2.22p4

The string descriptor pointer of the 1st string is loaded to FAC1 mantissa
bytes 2 & 3 and is later tranferred to FAC2 via the stack. The subroutine to put
FAC1 on the stack is rounding up if FAC1_r is > $7F. In string operations FAC1_r
is not initialized and rounding up may offset the string pointer high byte.

A patch is available to initialize FAC1_r to < $80 if the variable type is
string.

LAB_1C25
; *** begin patch  string pointer high byte trashed when moved to stack
; *** add
      LSR   FAC1_r            ; clear bit 7 (<$80) = do not round up
; *** end patch
      RTS

8. FALSE value stored to a variable after string compare is not exactly zero
fixed in 2.22p4

When strings are compared and the result is stored to a variable (x=a$=b$) a
FALSE result is not exactly 0 but only less than 1-E16. So IF var evaluates as
true and falsely executes the statements after THEN.

After a compare FAC1 contains the result. The LET command should store FAC1 into
the variable but actually stores a string pointer.

A patch is available to fix the LET command.

LAB_LET
      JSR   LAB_GVAR          ; get var address
      STA   Lvarpl            ; save var address low byte
      STY   Lvarph            ; save var address high byte
      LDA   #TK_EQUAL         ; get = token
      JSR   LAB_SCCA          ; scan for CHR$(A), else do syntax error then warm start
      LDA   Dtypef            ; get data type flag, $FF=string, $00=numeric
      PHA                     ; push data type flag
      JSR   LAB_EVEX          ; evaluate expression
      PLA                     ; pop data type flag
      ROL                     ; set carry if type = string
; *** begin patch  result of a string compare stores string pointer to variable
;                  but should store FAC1 (true/false value)
; *** replace
;      JSR   LAB_CKTM          ; type match check, set C for string
;      BNE   LAB_17D5          ; branch if string
; *** with
      JSR   LAB_CKTM          ; type match check, keep C (expected type)
      BCS   LAB_17D5          ; branch if string
; *** end patch

      JMP   LAB_PFAC          ; pack FAC1 into variable (Lvarpl) and return

9. The stack floor protection does not cater for background interrupts
fixed in 2.22p4

EhBASIC makes heavy use of the stack. FOR, DO and GOSUB put their data
structures on the stack and can be nested only limited by the stack size. The
remaining free bytes on the stack are checked everytime a data structure is to
be stored on the stack. However, this check is not catering for the additional
stack space required by background interrupts of a monitor or operating system.

A patch is available to configure a value to raise the protected stack floor.

LAB_1212
; *** patch - additional stack floor protection for background interrupts
; *** add
      .IF   Stack_floor
      CLC                     ; prep ADC
      ADC   #Stack_floor      ; stack pointer lower limit before interrupts
      .ENDIF
; *** end patch
      STA   TempB             ; save result in temp byte
      TSX                     ; copy stack
      CPX   TempB             ; compare new "limit" with stack
      BCC   LAB_OMER          ; if stack < limit do "Out of memory" error then warm start

      RTS

You should also define Stack_floor with other configuation items. I put it just
after RAM_top.

Stack_floor       = 16        ; bytes left free on stack for background interrupts

10. Conditional NEXT throws a "NEXT without FOR Error"
fixed in 2.22p4

If a NEXT statement is executed after IF THEN the FOR structure cannot be found.
The NEXT expects the FOR structure at a fixed offset on the stack but the
IF THEN puts an additional address on the stack. The additional address is
required as EhBASIC allows an ELSE statement on the same line and the statement
after the ELSE needs to be skipped.

The same is also true for other commands that need to find a data structure on
the stack. The code already contained a fix for a conditional RETURN but it
could not be used for LOOP (UNTIL/WHILE) or NEXT as it does not allow resuming
execution after falling through.

I have a fix that simply discards the original call to the "interpret statement"
routine (The one that executed the IF) and replaces the final RTS with a JMP to
the interpreter loop. This also eliminates the need to have a separate fix for
RETURN. To my big surprise even nested IFs work correctly.

LAB_174D
; *** patch       allow NEXT, LOOP & RETURN to find FOR, DO or GOSUB structure on stack
; *** replace
;      CMP   #TK_RETURN        ; compare the byte with the token for RETURN
;      BNE   LAB_174G          ; if it wasn't RETURN go interpret BASIC code from (Bpntrl)
;                              ; and return to this code to process any following code
;
;      JMP   LAB_1602          ; else it was RETURN so interpret BASIC code from (Bpntrl)
;                              ; but don't return here
;
;LAB_174G
;      JSR   LAB_15FF          ; interpret BASIC code from (Bpntrl)
;
;; the IF was executed and there may be a following ELSE so the code needs to return
;; here to check and ignore the ELSE if present
;
;      LDY   #$00              ; clear the index
;      LDA   (Bpntrl),Y        ; get the next BASIC byte
;      CMP   #TK_ELSE          ; compare it with the token for ELSE
;      BEQ   LAB_DATA          ; if ELSE ignore the following statement
;
;; there was no ELSE so continue execution of IF <expr> THEN <stat> [: <stat>]. any
;; following ELSE will, correctly, cause a syntax error
;
;      RTS                     ; else return to the interpreter inner loop
;
; *** with
      PLA                     ; discard interpreter loop return address
      PLA                     ; so data structures are at the correct stack offset
      JSR   LAB_GBYT          ; restore token or variable
      JSR   LAB_15FF          ; interpret BASIC code from (Bpntrl)

; the IF was executed and there may be a following ELSE so the code needs to return
; here to check and ignore the ELSE if present

      LDY   #$00              ; clear the index
      LDA   (Bpntrl),Y        ; get the next BASIC byte
      CMP   #TK_ELSE          ; compare it with the token for ELSE
      BNE   LAB_no_ELSE       ; no - continue on this line
      JSR   LAB_DATA          ; yes - skip the rest of the line

; there was no ELSE so continue execution of IF <expr> THEN <stat> [: <stat>]. any
; following ELSE will, correctly, cause a syntax error

LAB_no_ELSE
      JMP LAB_15C2            ; return to the interpreter inner loop
; *** end patch  allow NEXT, LOOP & RETURN to find FOR, DO or GOSUB structure on stack

11. Additional bugs brought up by users Ruud and dclxvi of the 6502.org forum

See http://forum.6502.org/viewtopic.php?f=5&t=5500
       sanity check for RAM top allows values below RAM base
    http://forum.6502.org/viewtopic.php?f=5&t=5606
       #1 TO expression with a subtract may evaluate with the sign bit flipped
       #3 call to LAB_1B5B may return to an address -$100 (page not incremented)
       #4 string concatenate followed by MINUS or NOT() crashes EhBASIC
       #5 garbage collection may cause an overlap with temporary strings
       #6 floating point multiply rounding bug
       #7 VAL() may cause string variables to be trashed
    All above have been fixed in 2.22p5. See the thread for additional quirks.

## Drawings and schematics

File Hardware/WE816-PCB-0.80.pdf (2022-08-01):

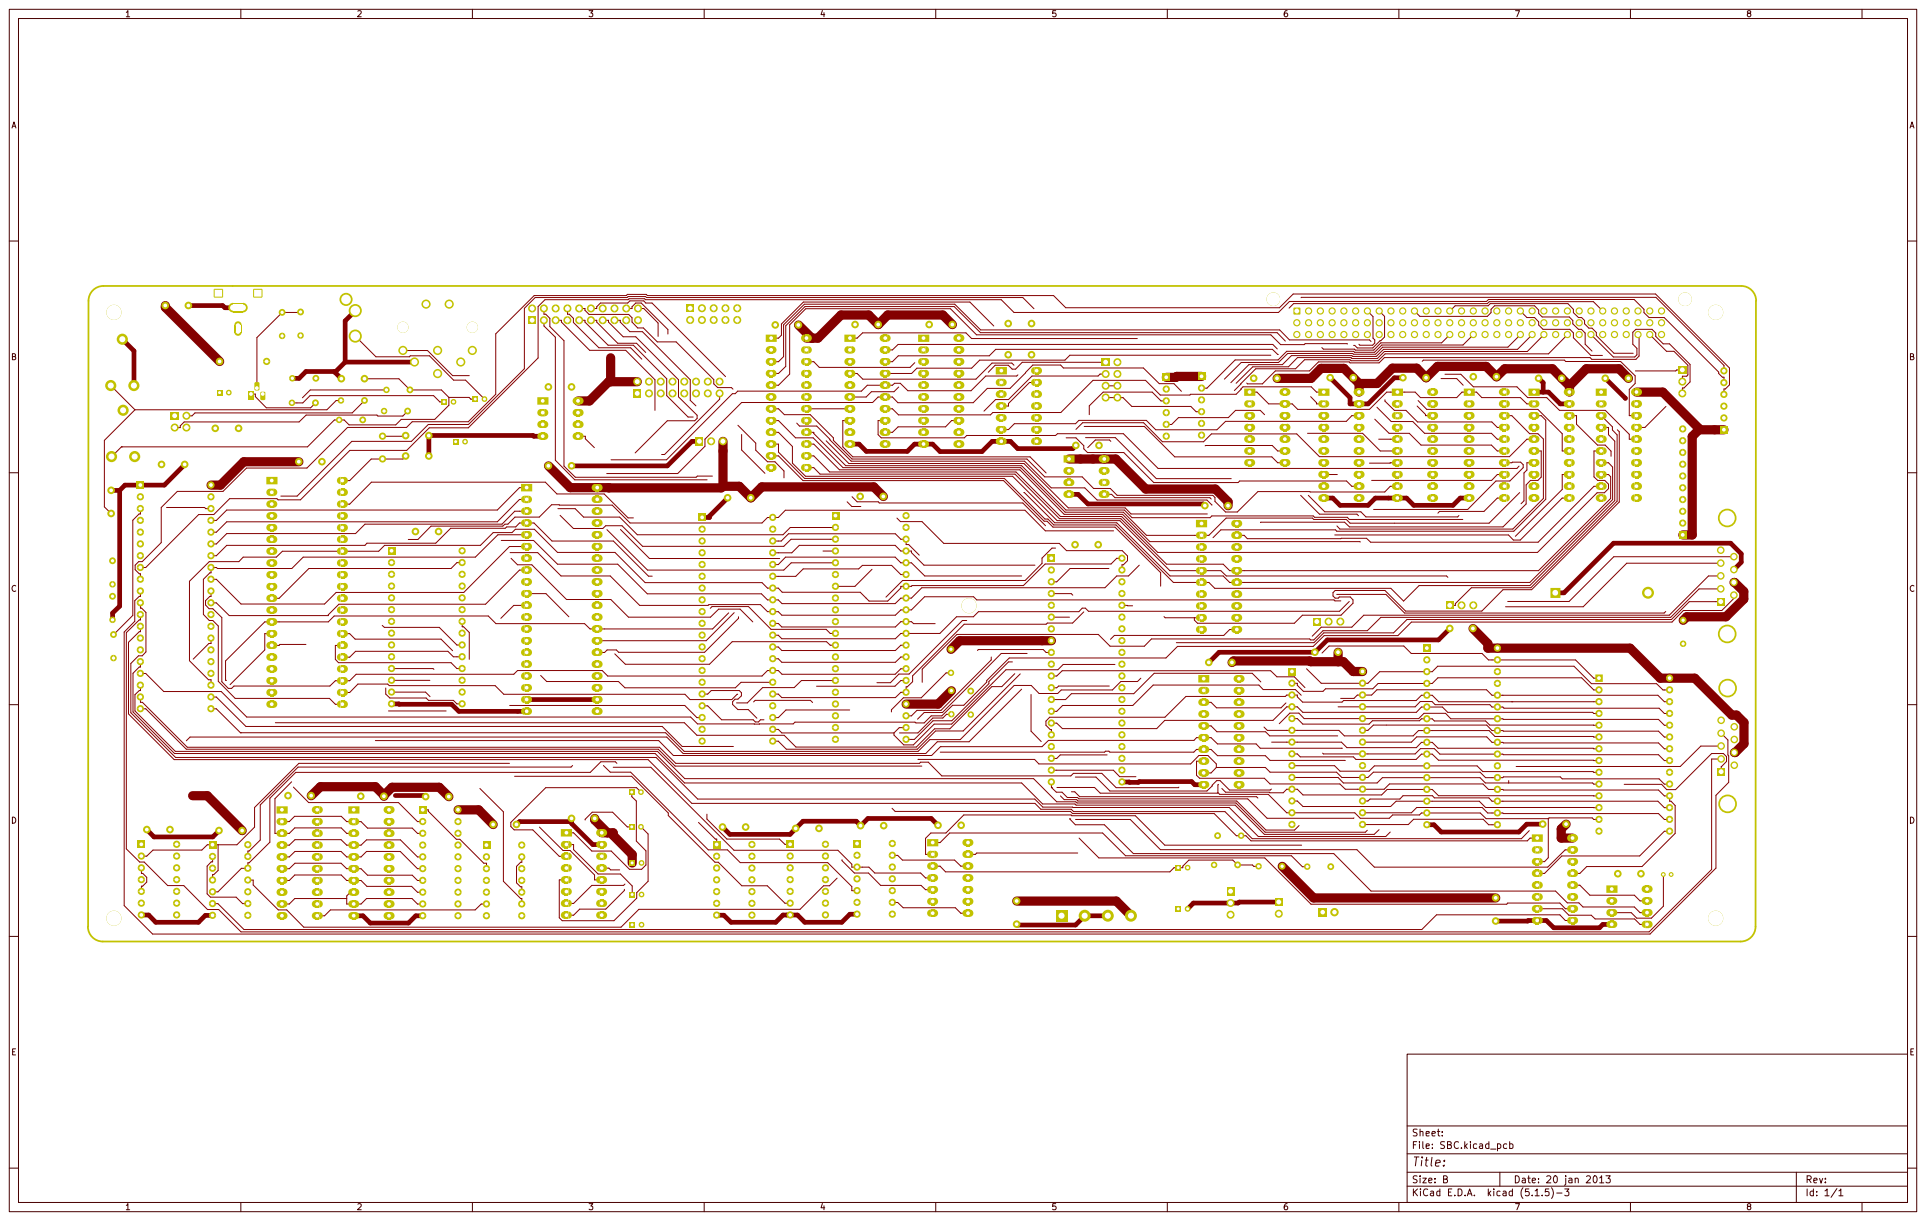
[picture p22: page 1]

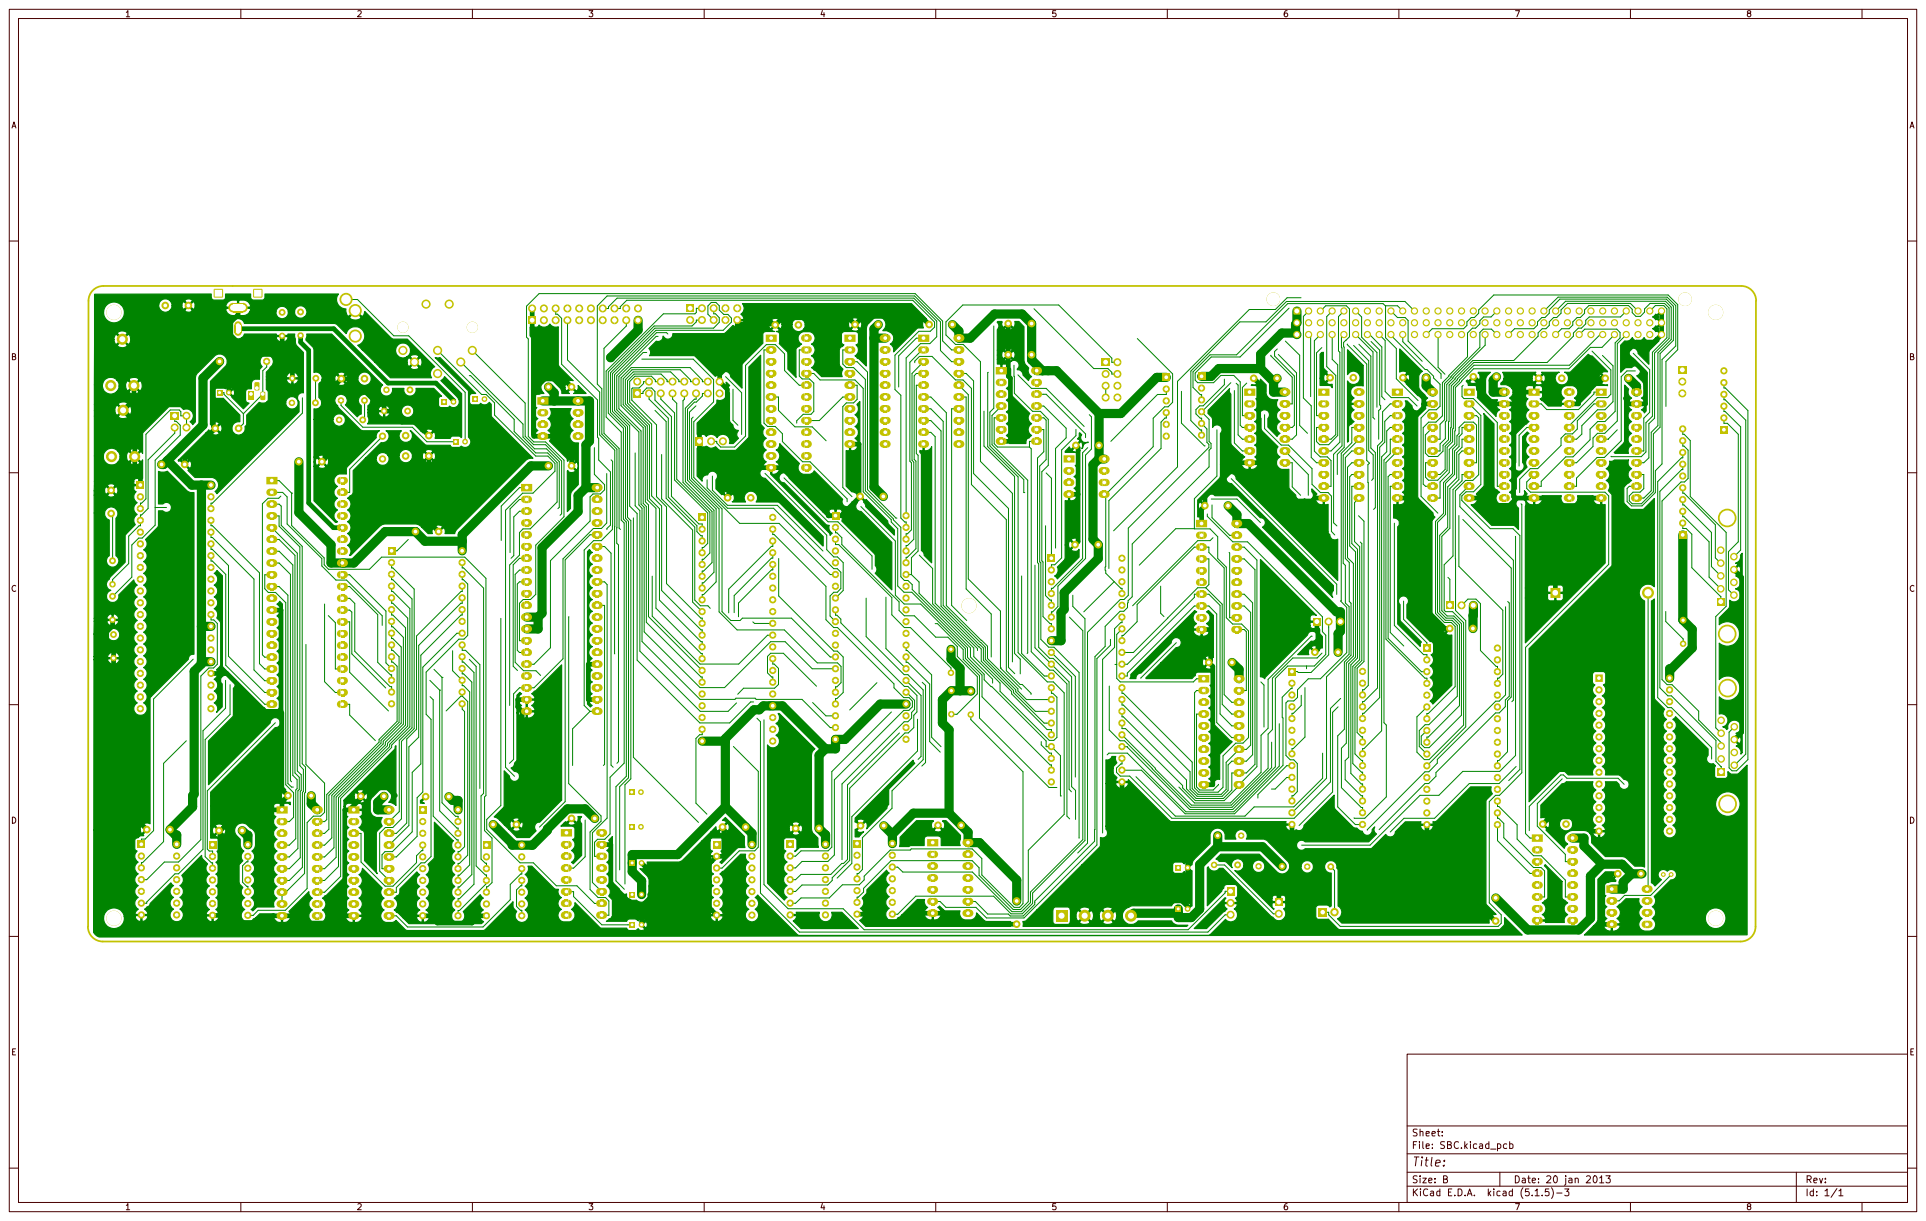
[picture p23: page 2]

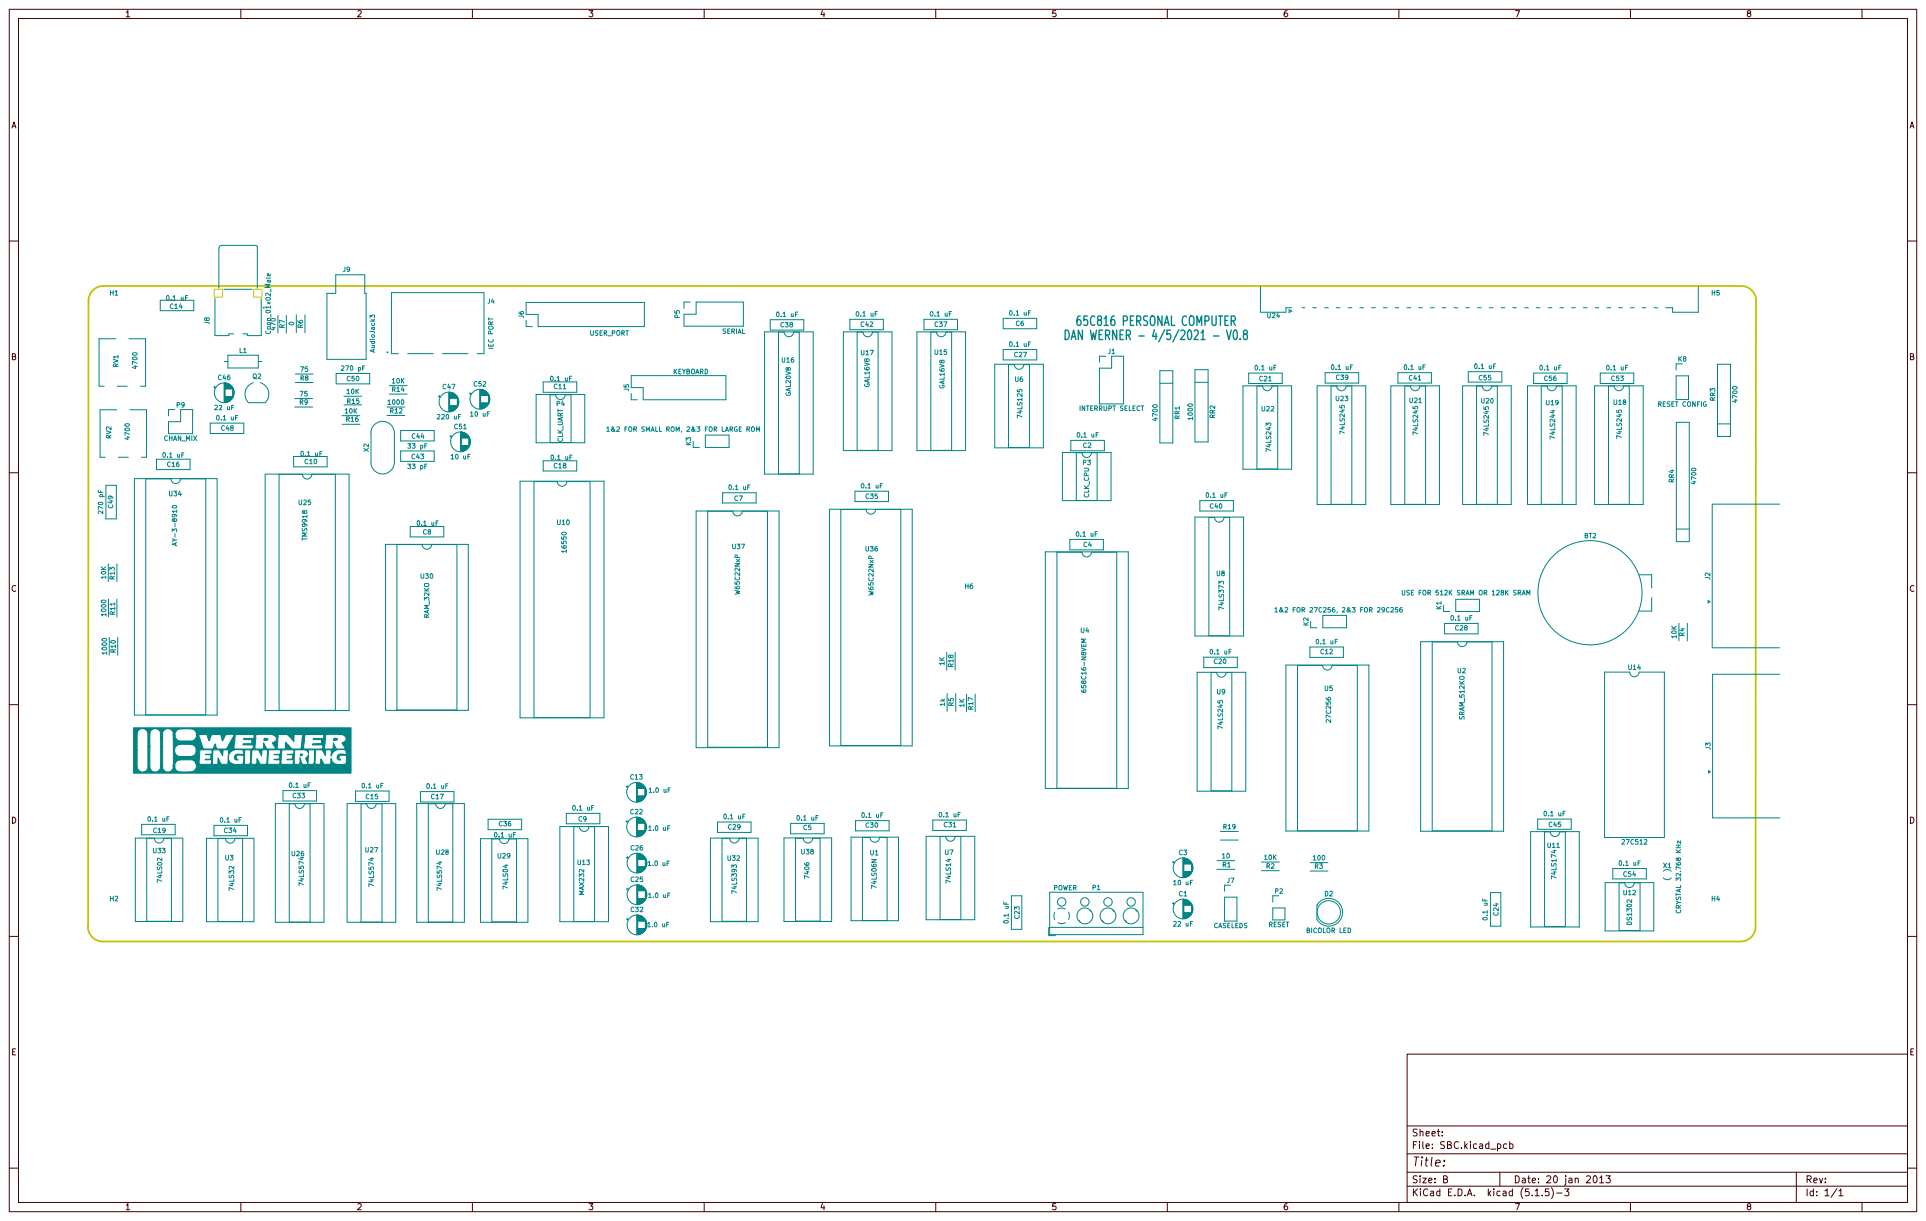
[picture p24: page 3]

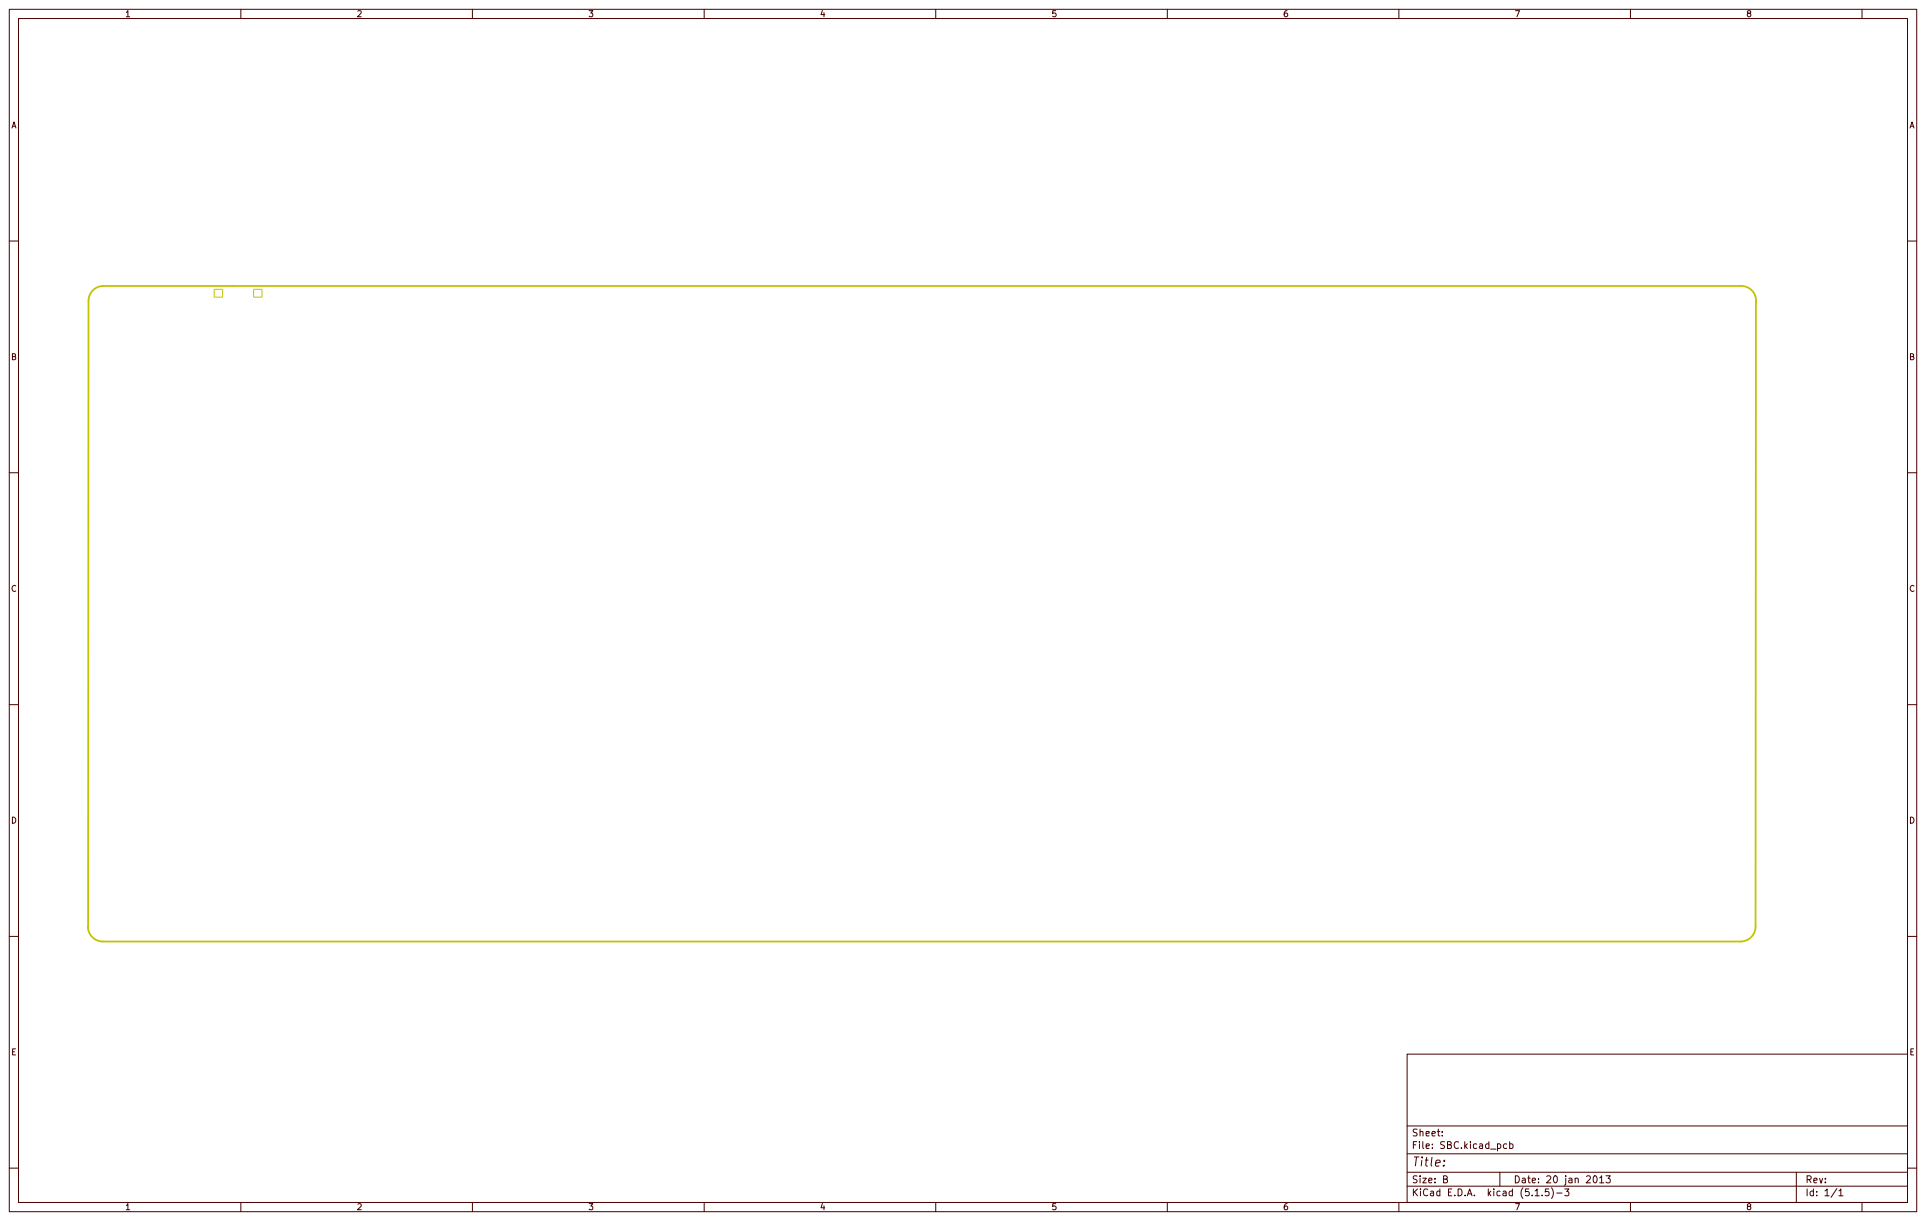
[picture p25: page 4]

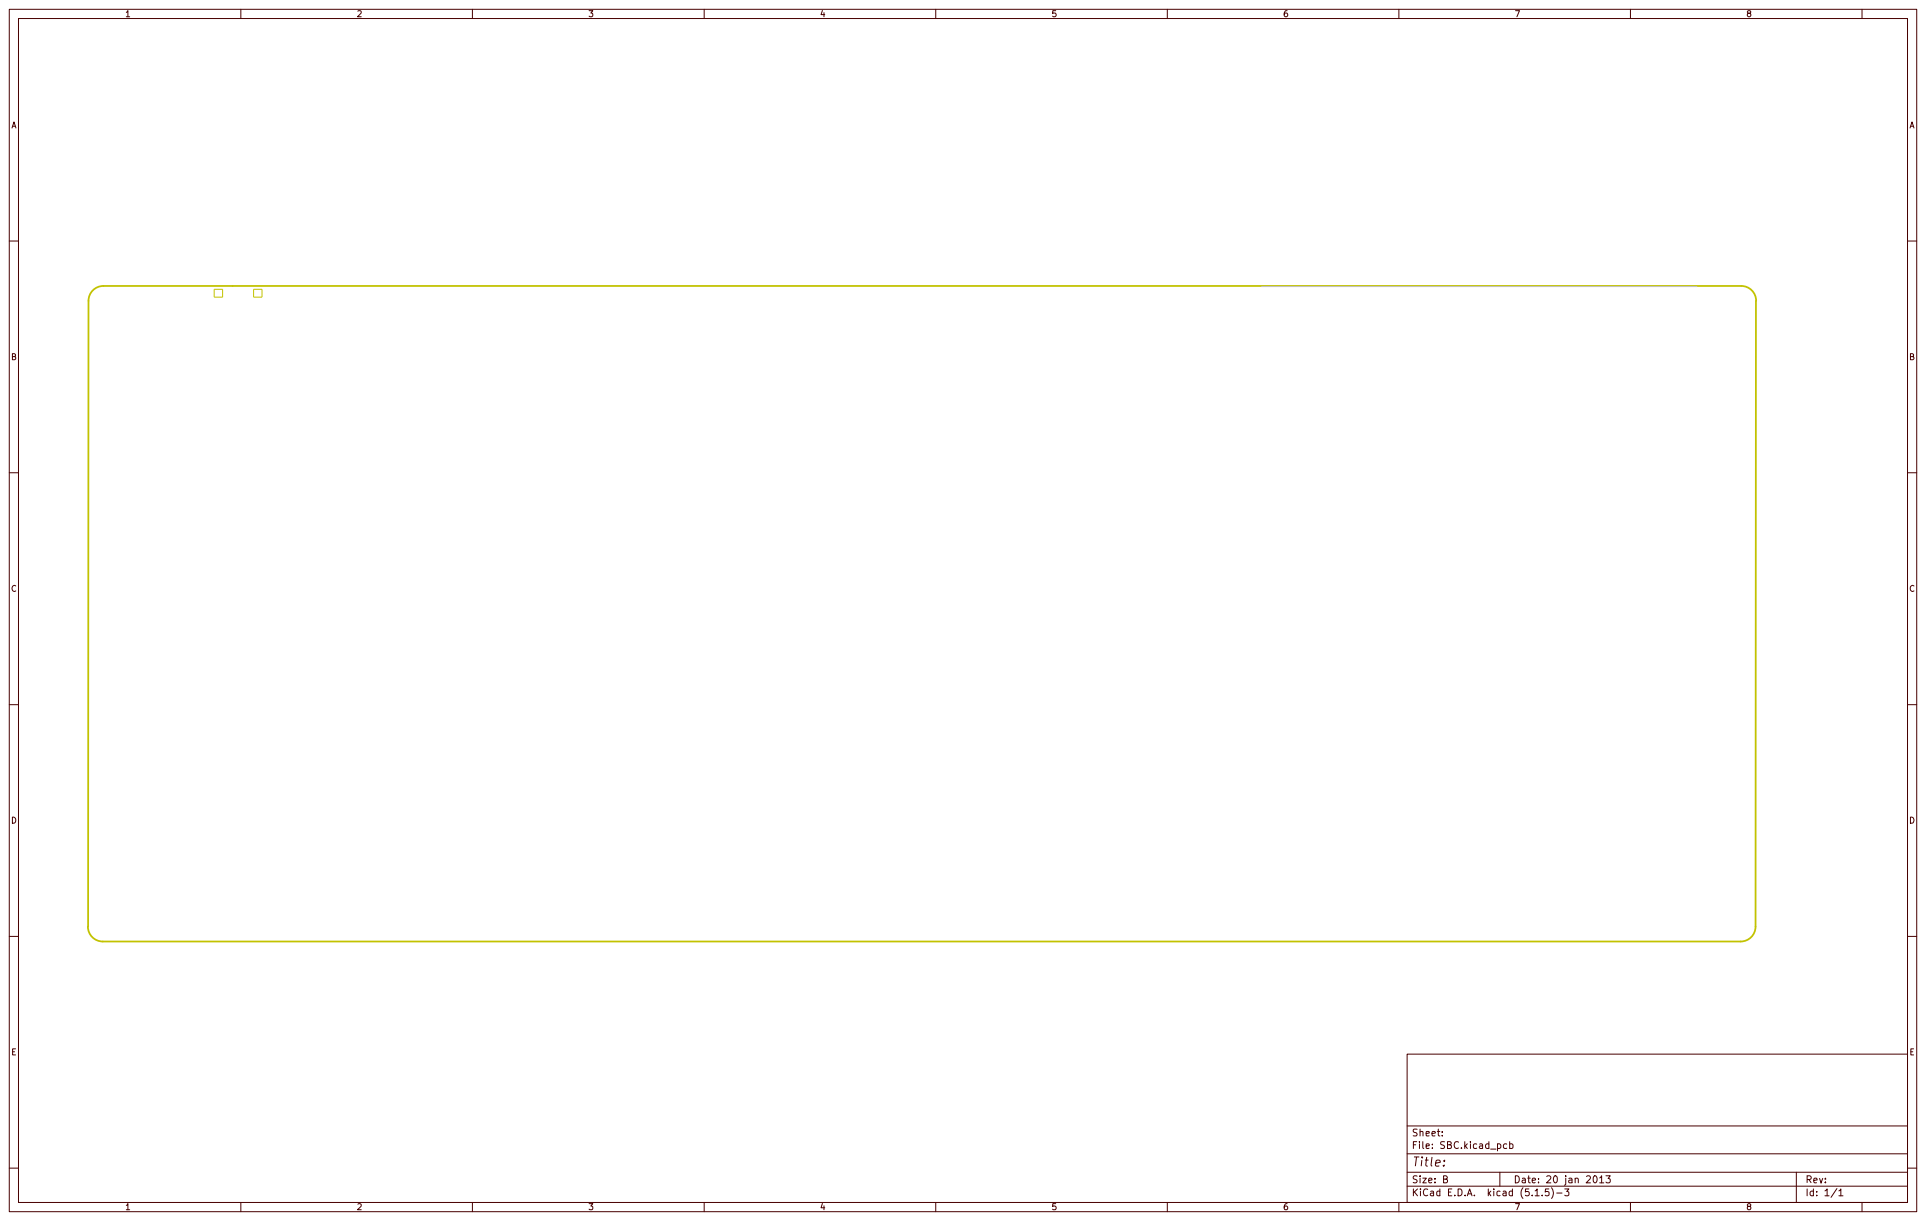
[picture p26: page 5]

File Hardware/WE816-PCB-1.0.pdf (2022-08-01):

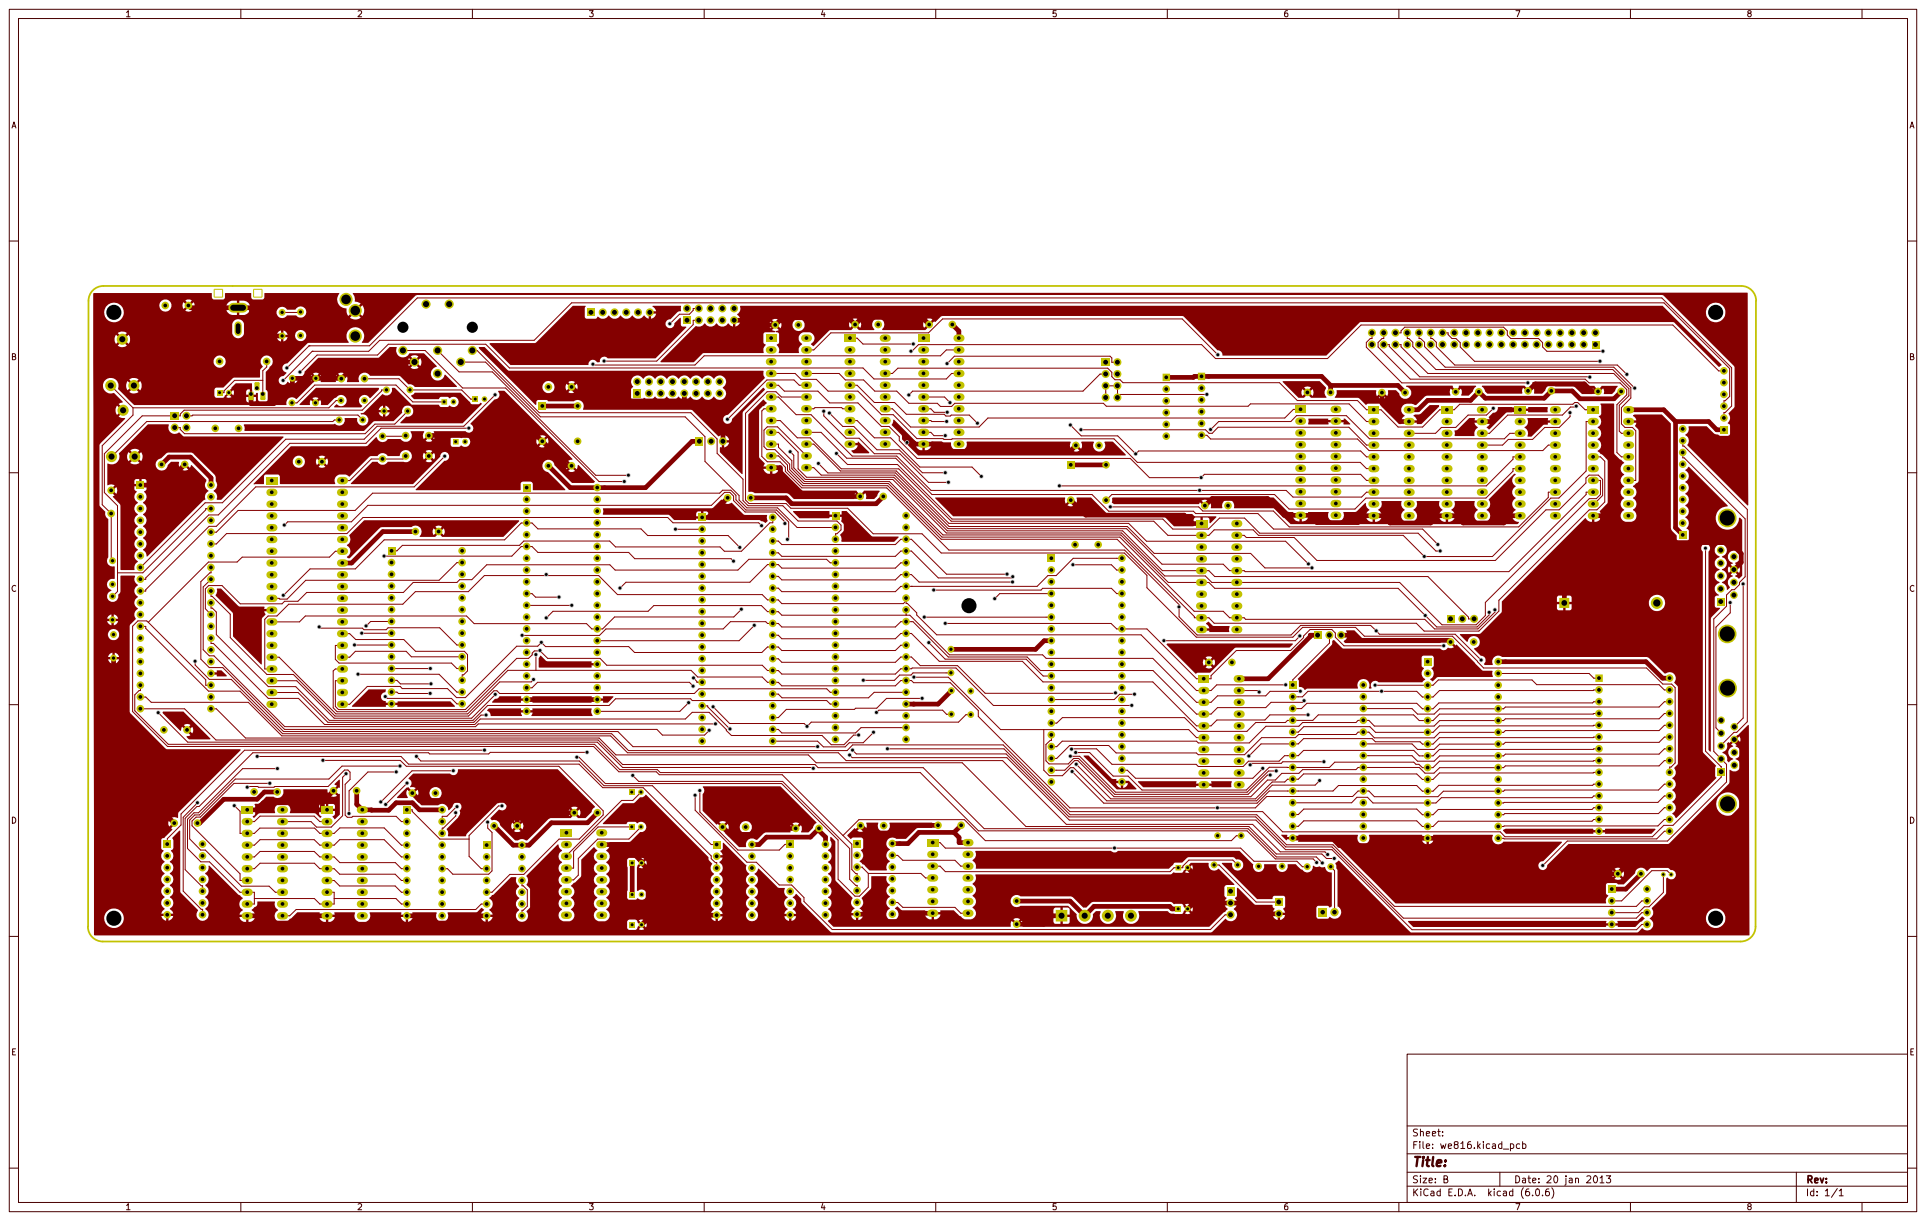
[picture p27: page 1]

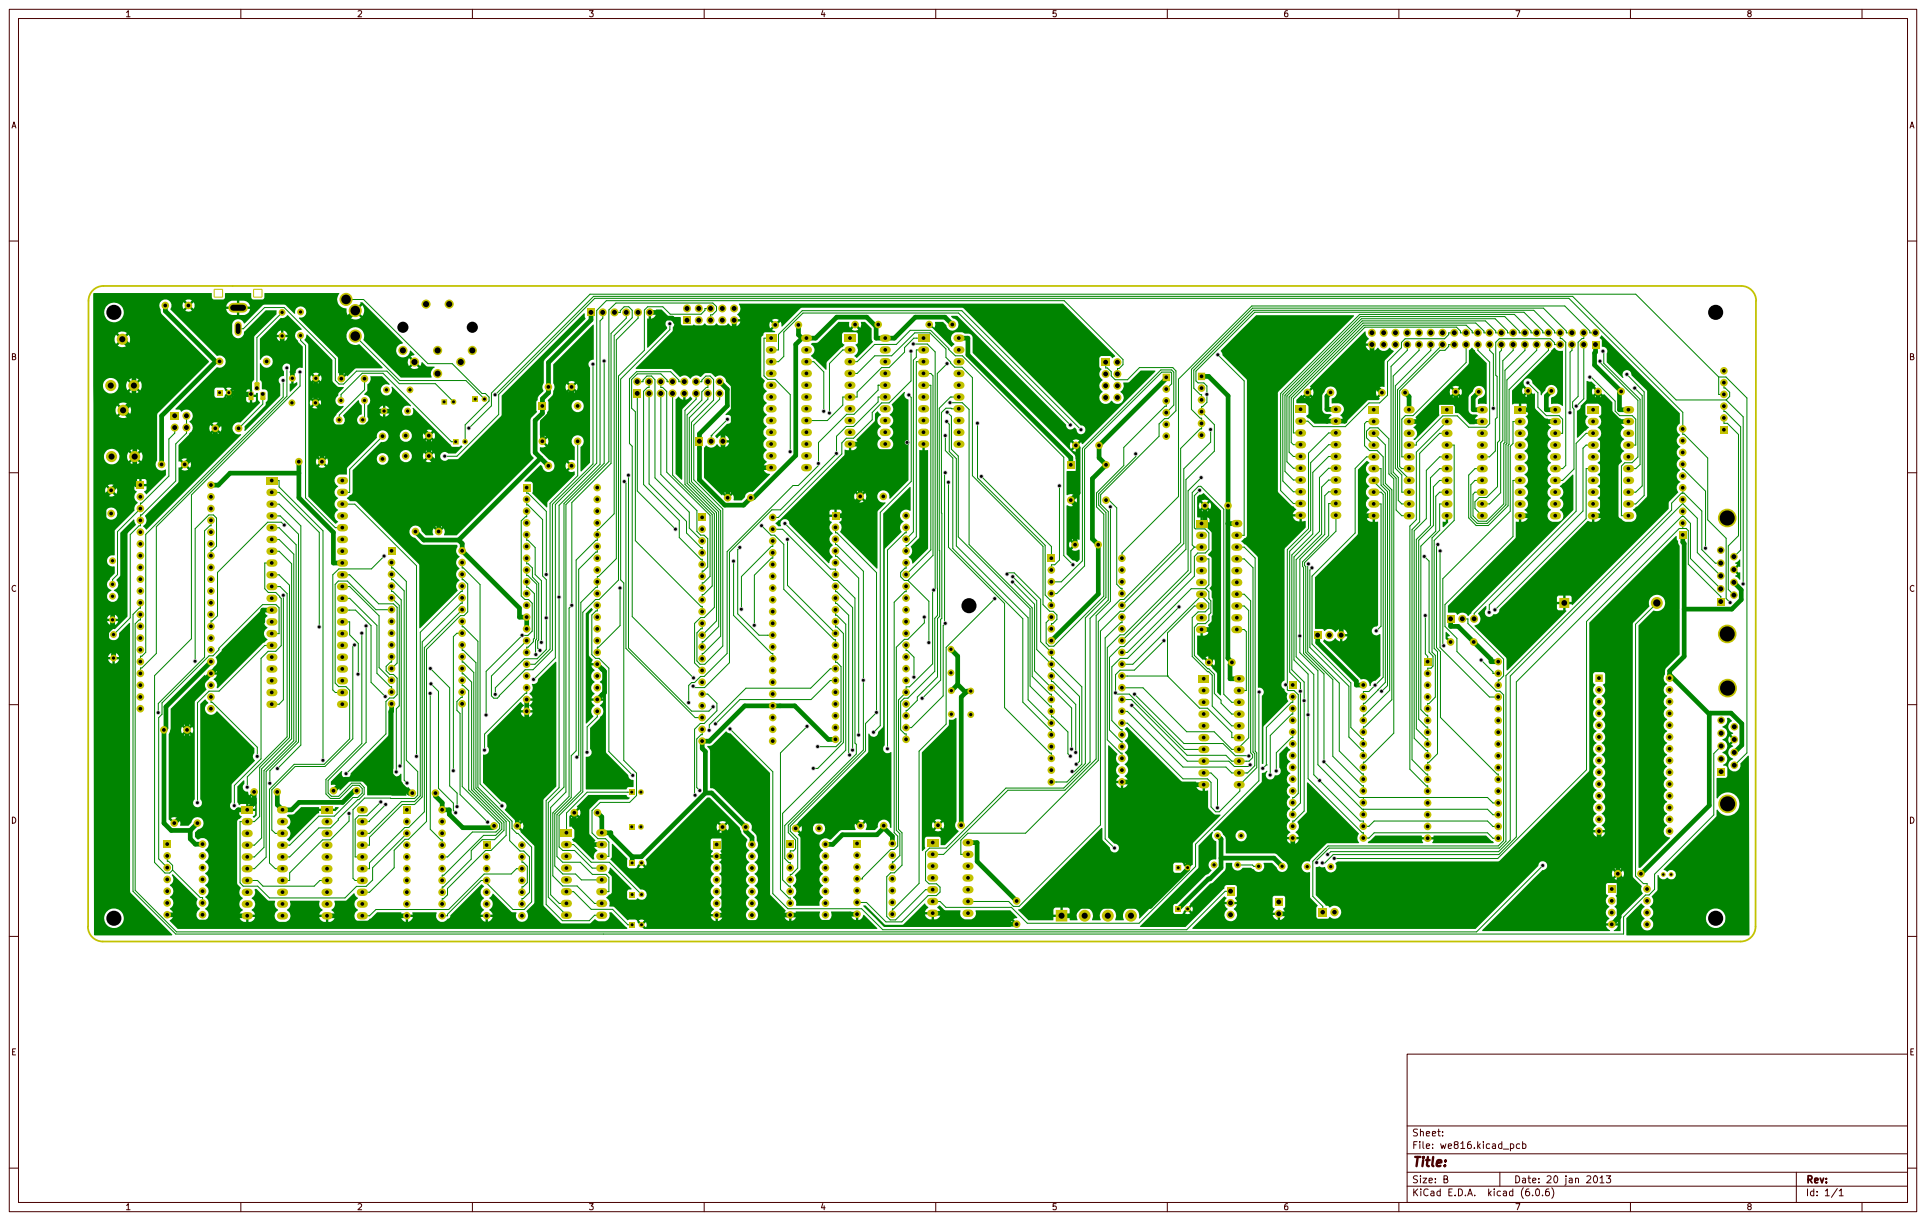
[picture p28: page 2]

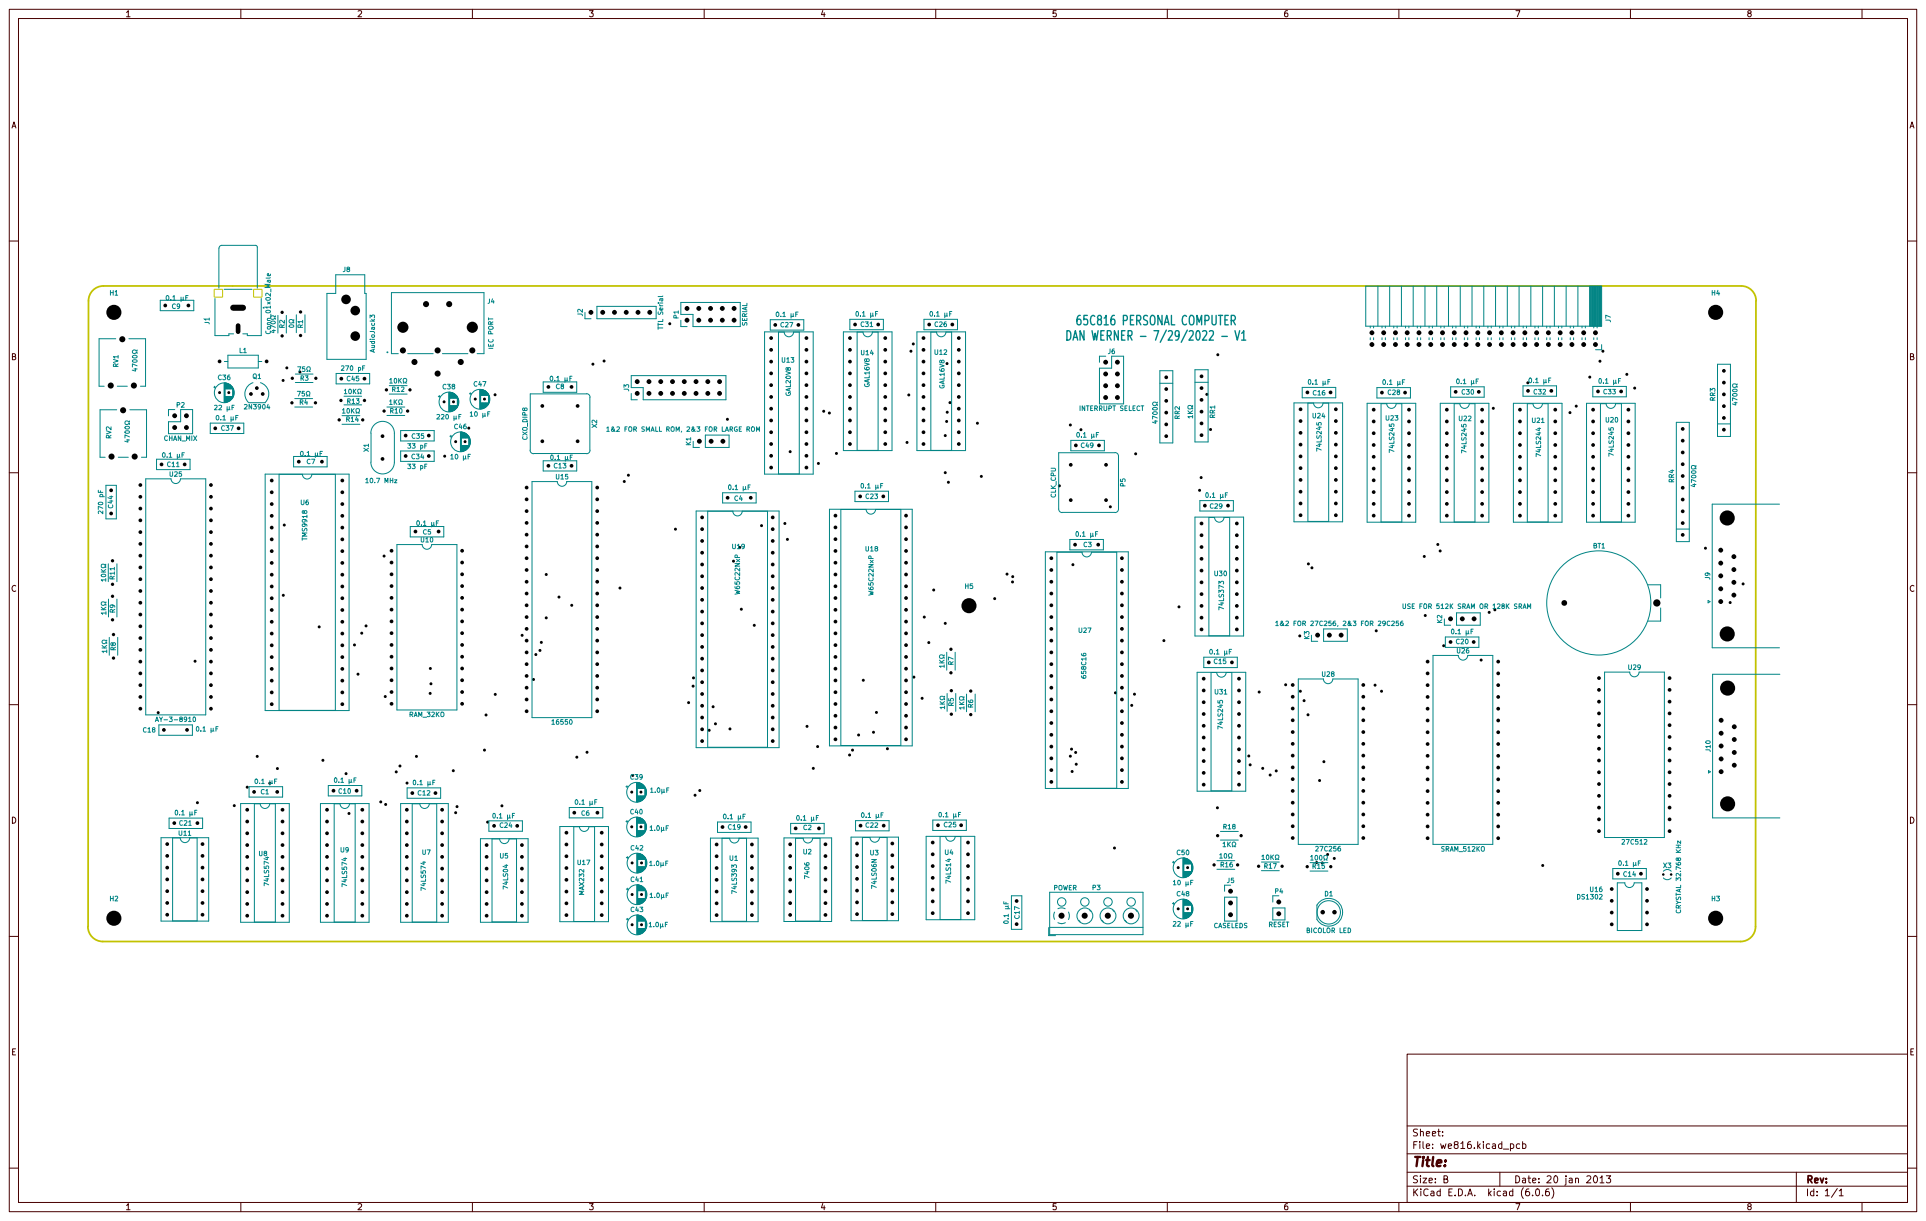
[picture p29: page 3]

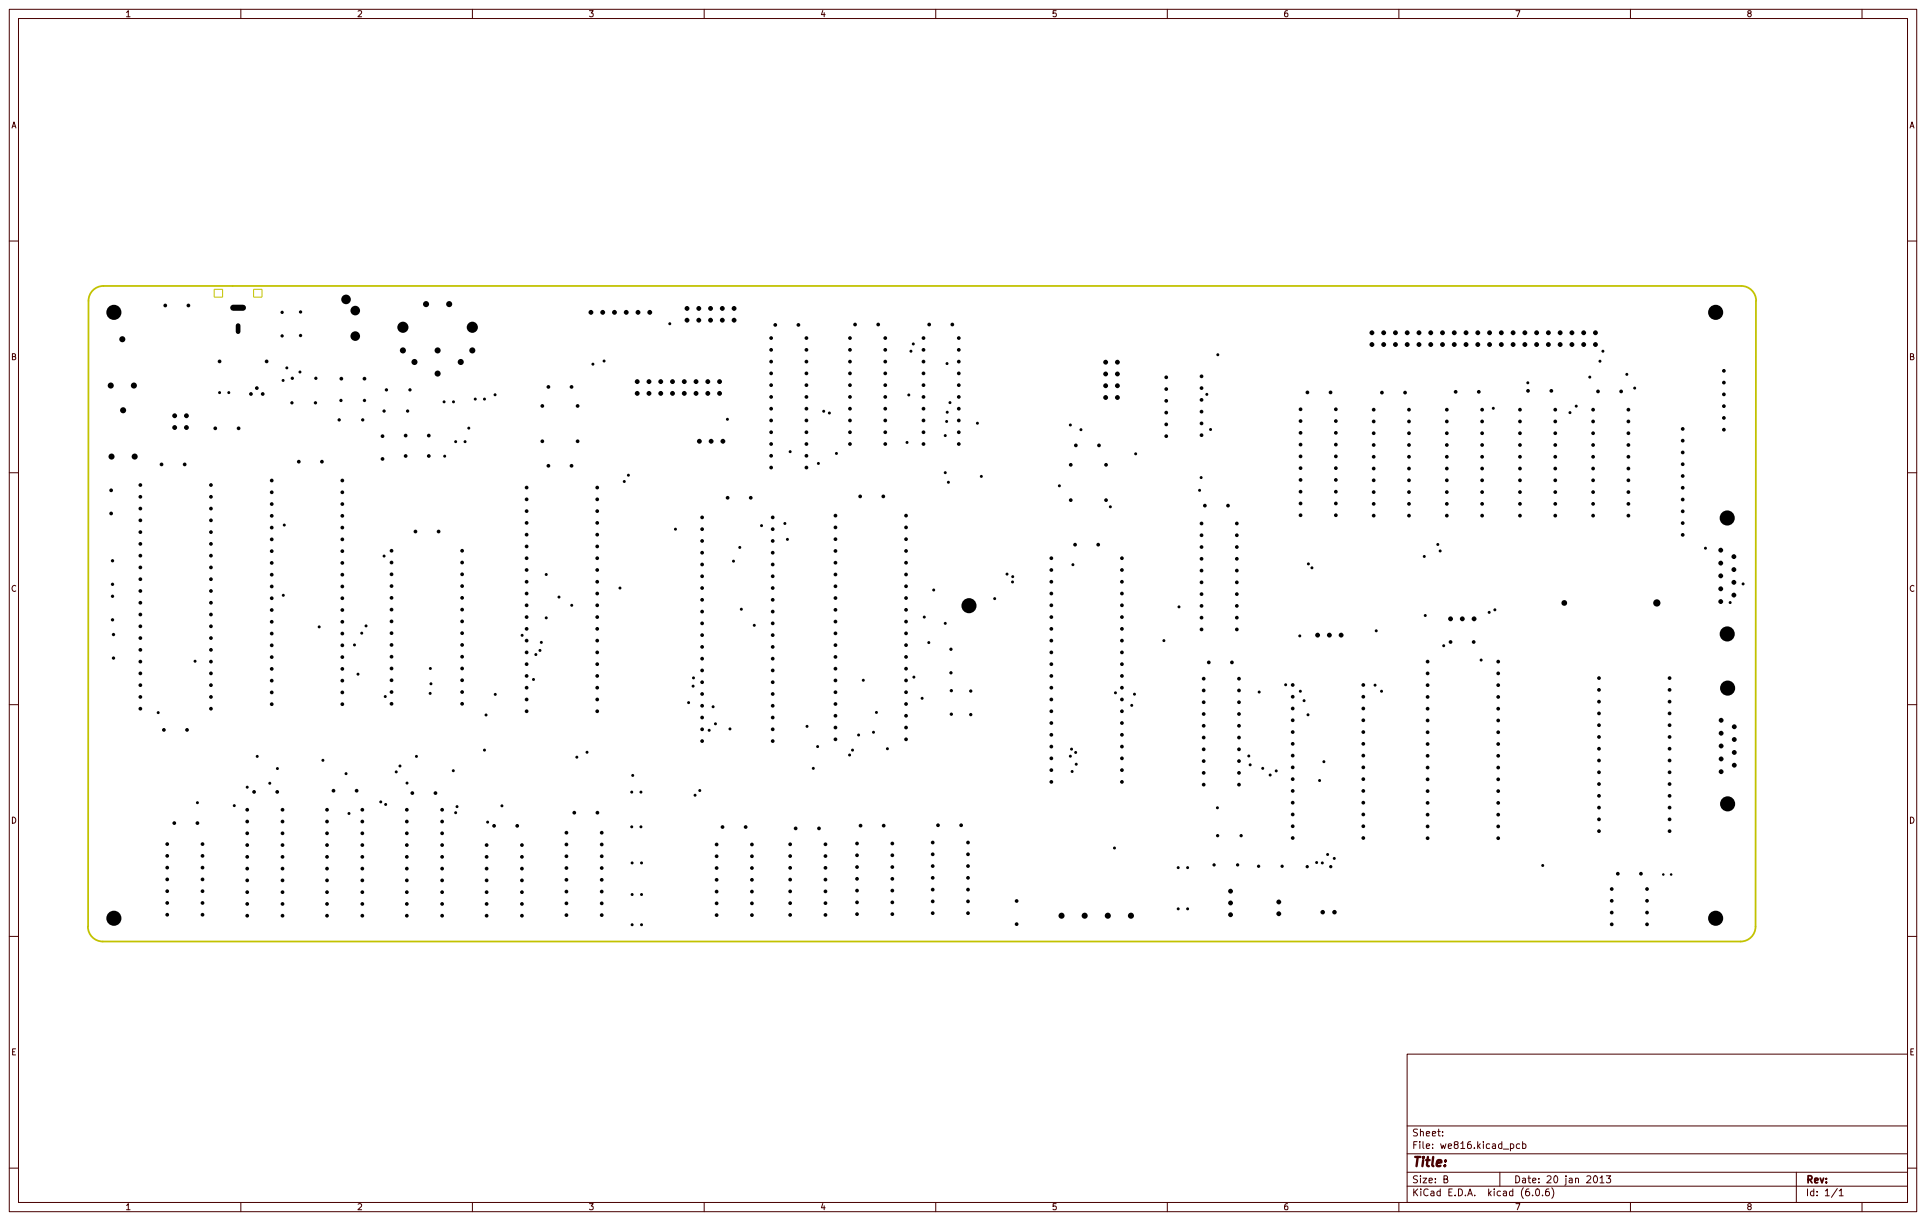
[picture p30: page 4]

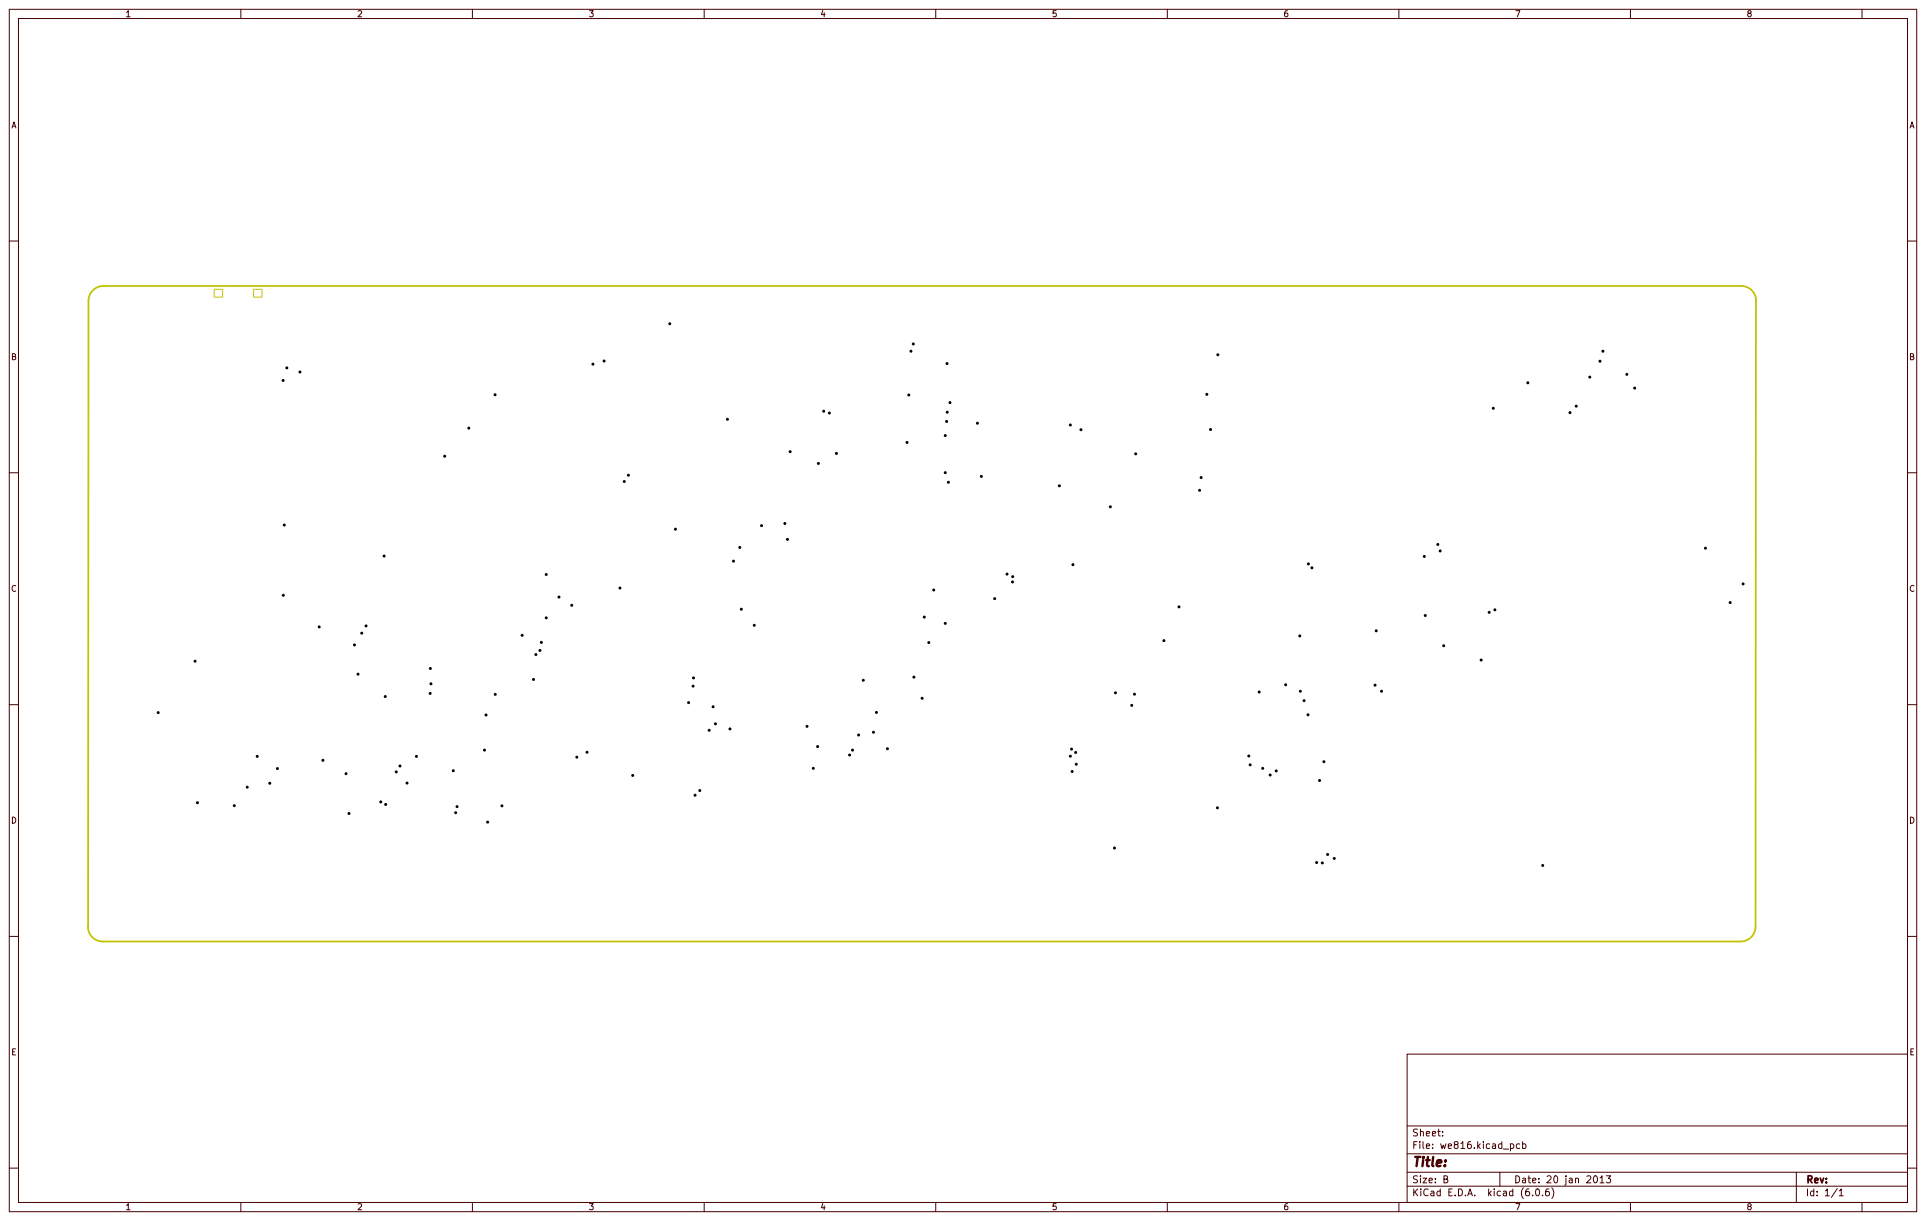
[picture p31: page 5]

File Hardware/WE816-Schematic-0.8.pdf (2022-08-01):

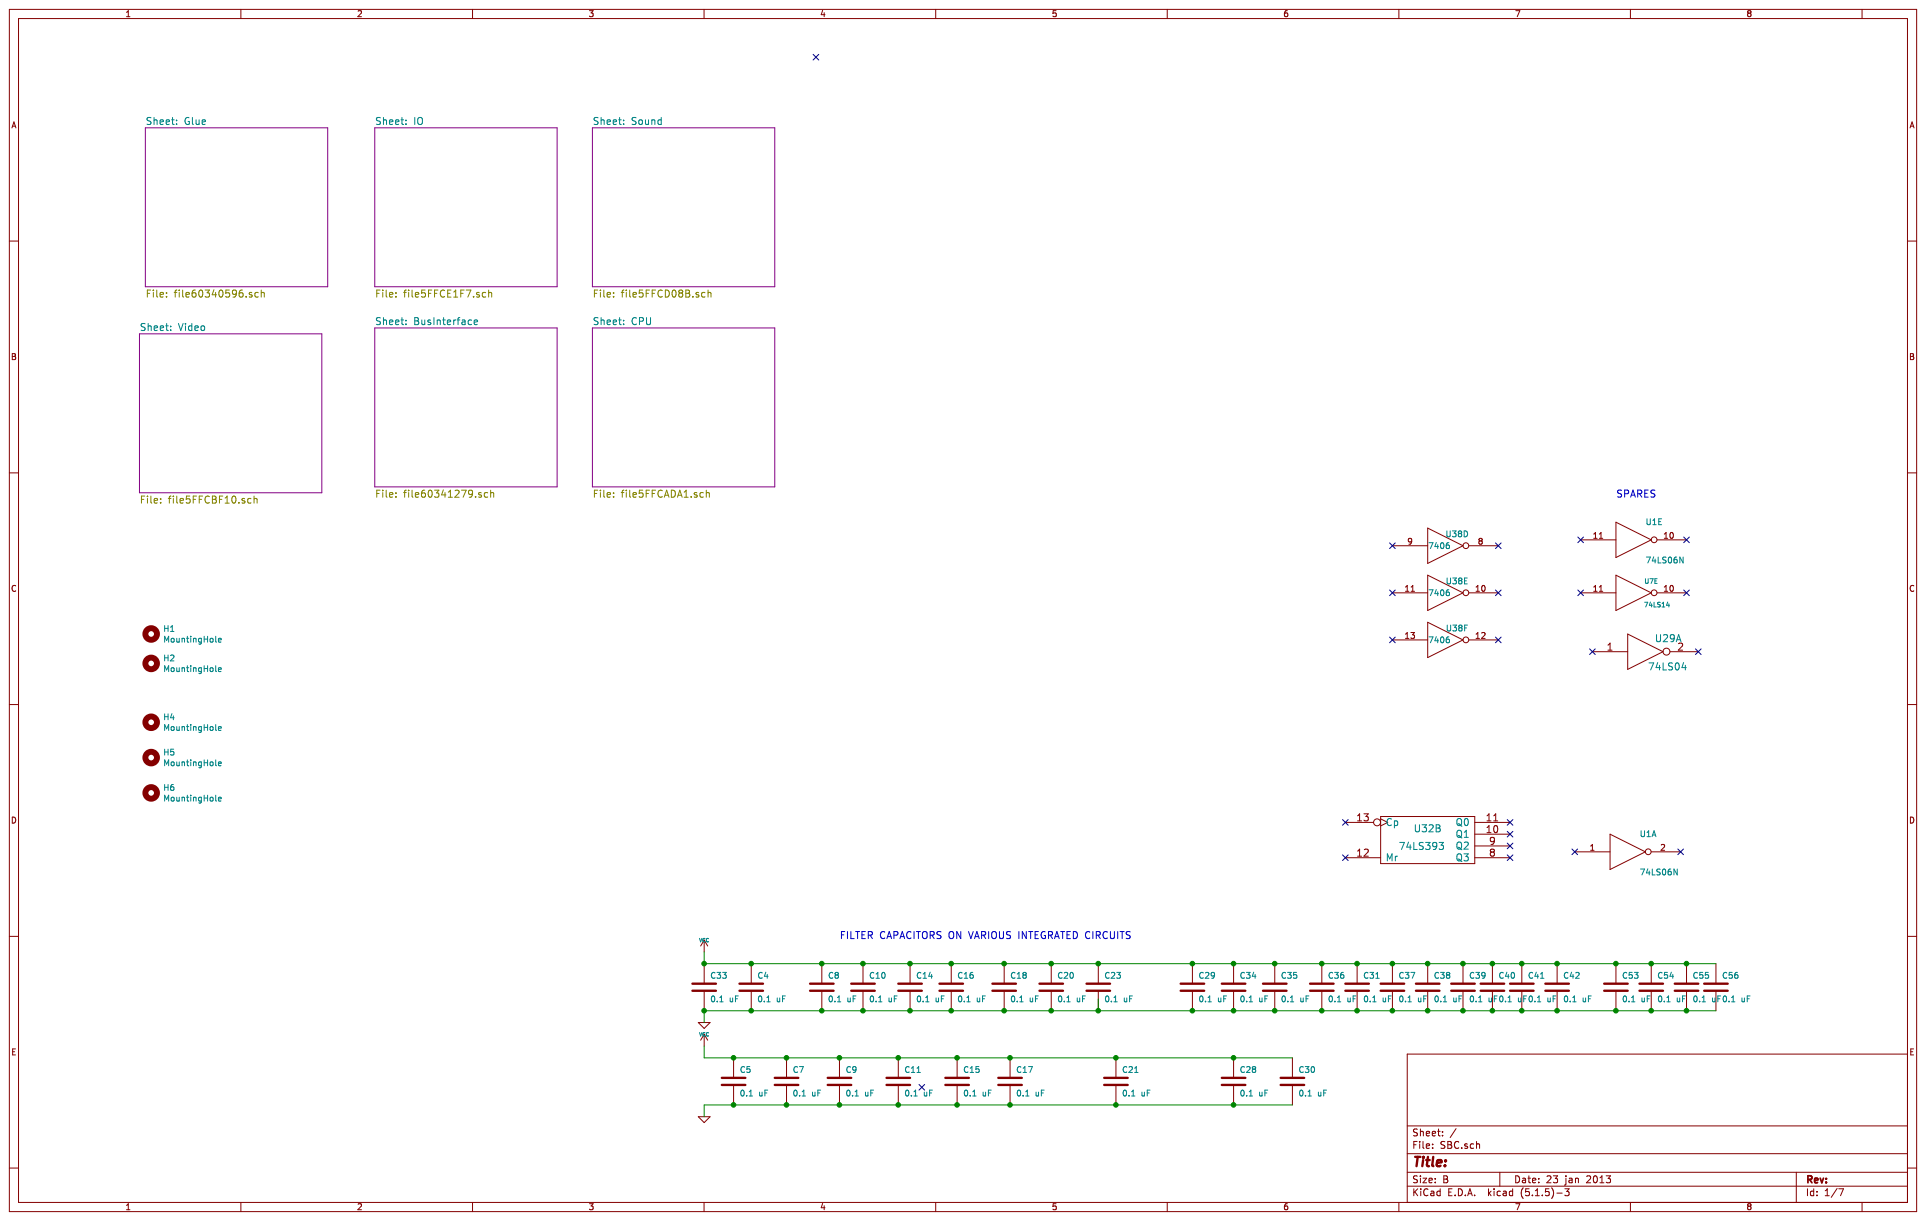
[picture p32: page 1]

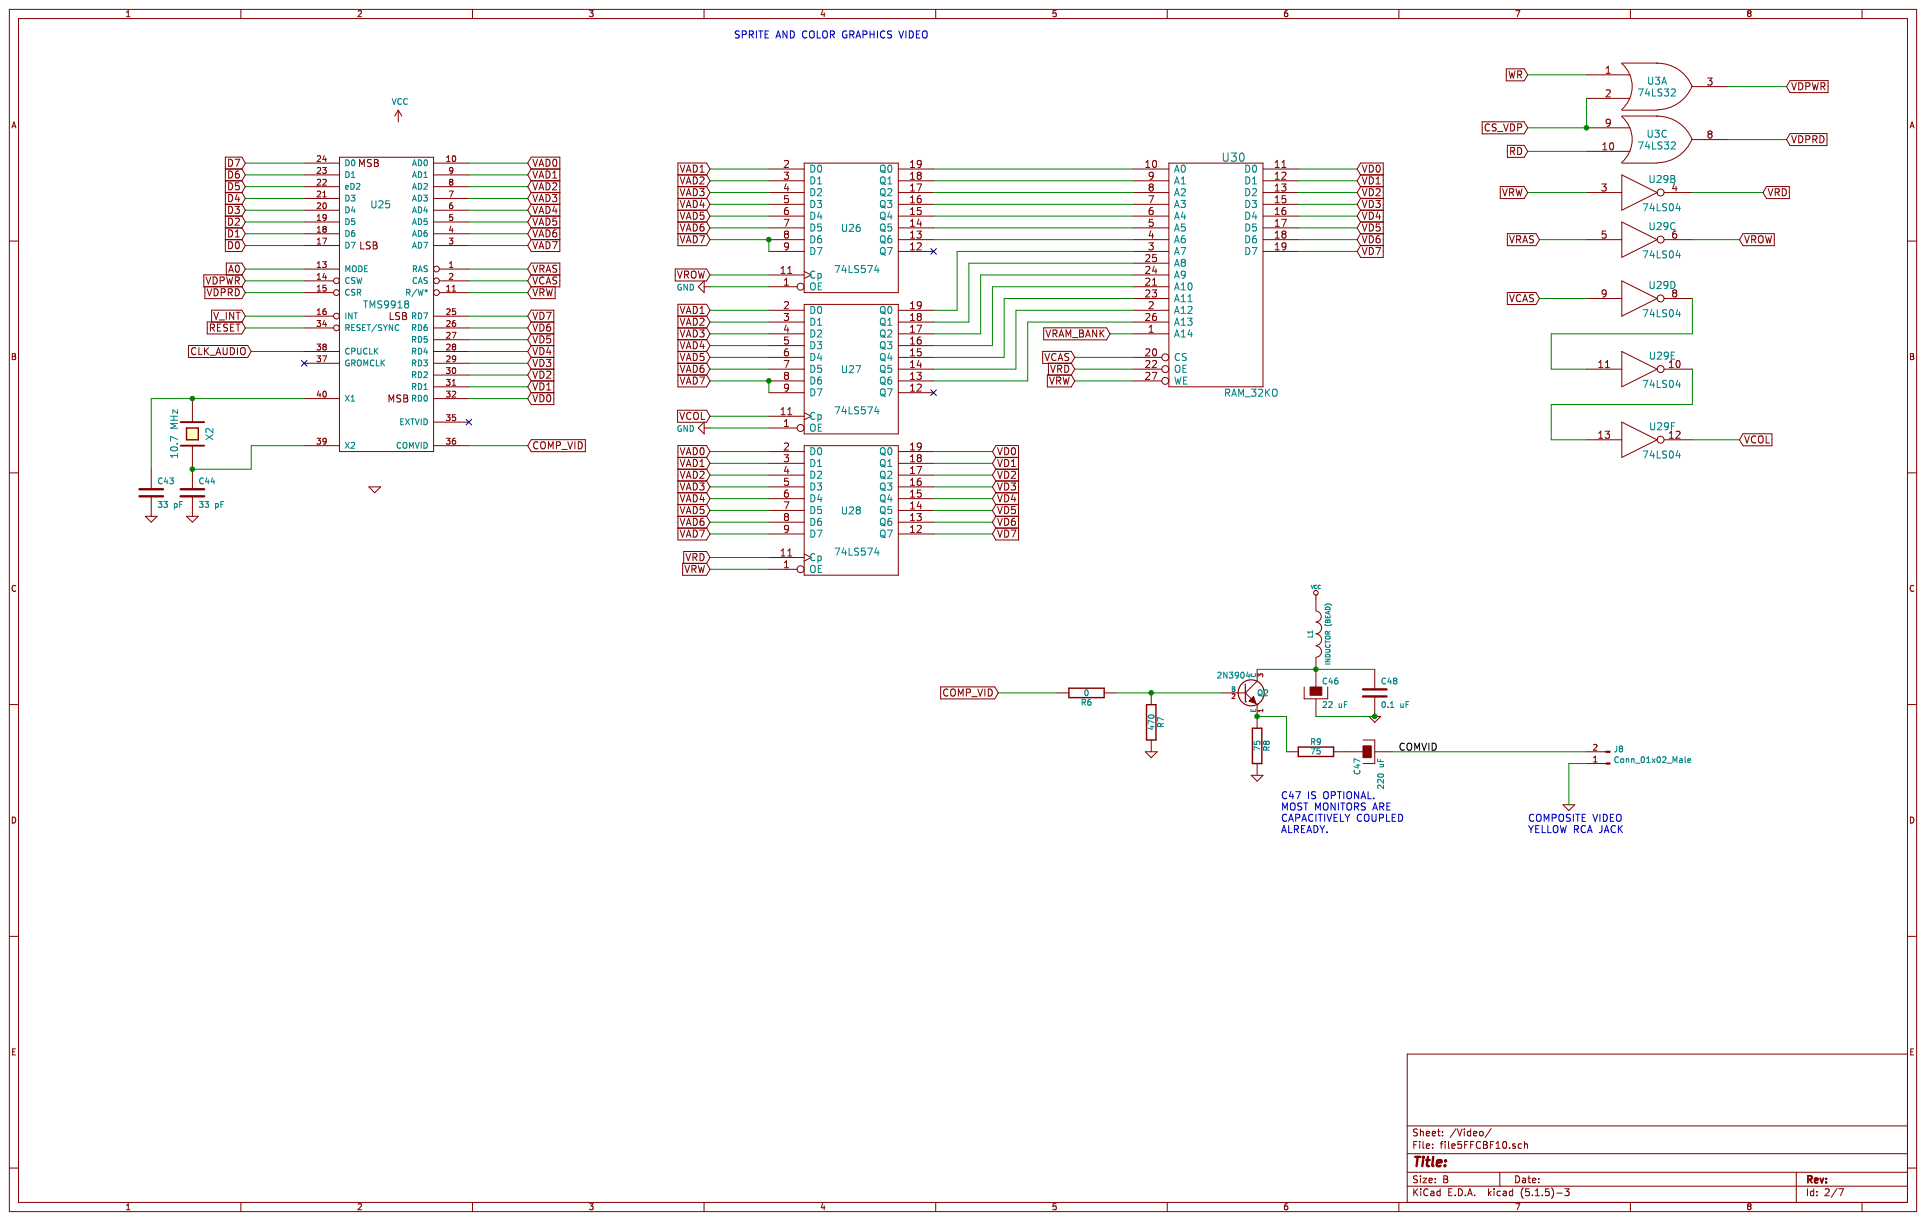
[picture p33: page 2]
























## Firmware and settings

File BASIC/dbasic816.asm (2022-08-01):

; Enhanced BASIC to assemble under 6502 simulator, $ver 2.23
; THIS WORK IS DERIVED FROM ehBASIC BY LEE DAVIDSON
;
; $E7E1 $E7CF $E7C6 $E7D3 $E7D1 $E7D5 $E7CF $E81E $E825

; 2.00	new revision numbers start here
; 2.01	fixed LCASE$() and UCASE$()
; 2.02	new get value routine done
; 2.03	changed RND() to galoise method
; 2.04	fixed SPC()
; 2.05	new get value routine fixedf
; 2.06	changed USR() code
; 2.07	fixed STR$()
; 2.08	changed INPUT and READ to remove need for $00 start to input buffer
; 2.09	fixed RND()
; 2.10	integrated missed changes from an earlier version
; 2.20	added ELSE to IF .. THEN and fixed IF .. GOTO <statement> to cause error
; 2.21	fixed IF .. THEN RETURN to not cause error
; 2.22	fixed RND() breaking the get byte routine
; 2.30  CONVERT TO 65816 ADDRESS SPACE


		CHIP	65816		; SET CHIP
    	LONGA	OFF		; ASSUME EMULATION MODE
    	LONGI	OFF		;
    	PW	128
    	PL 	60
    	INCLIST ON

   	.ORG	0FF1000H
BASICORG:
	JMP 	BASICBEGIN
;____________________________________________________________________________________________
;
; MACROS

	INCLUDE 'MACROS.ASM'

; ZERO PAGE DEFINITIONS
	INCLUDE 'ZEROPAGE.ASM'

; BASIC TOKENS
	INCLUDE 'TOKENS.ASM'

; DEFINITIONS
	INCLUDE 'DEFINITIONS.ASM'

; MESSAGES
	INCLUDE 'MESSAGES.ASM'

; NUMERIC CONSTANTS
	INCLUDE 'NUMCONST.ASM'

; I/O VECTORS
	INCLUDE 'IOVECT.ASM'
;
;____________________________________________________________________________________________


			    	        ;   ensure CPU Context is in a known state
	NOP	; FIX A CODE PAGE ALIGNMENT PROBLEM
BASICBEGIN:

        CLD                 ; VERIFY DECIMAL MODE IS OFF
        CLC                 ;
        XCE                 ; SET NATIVE MODE
   		AccumulatorIndex16
		LDA #STACK 		; get the stack address
   		TCS 			; and set the stack to it
        LDA #$0000            ;
        PHA                 ; Set Direct Register to 0
        PLD                 ;

		IF PROGRAMBANK=DATABANK

		ELSE
		LDX #$1000
		LDY #$1000
		LDA #$1000
		MVN PROGRAMBANK,DATABANK	; COPY TABLES $1000 THROUGH $2000 PLUS OR MINUS :) TO WORKING BANK
		ENDIF
		AccumulatorIndex8
		LDA	#PROGRAMBANK	; SET DATA BANK = TO PROGRAM BANK TO ALLOW FOR INITIALIZATION FROM ROM
		PHA
		PLB					;



LAB_COLD
	LDX	#PG2_TABE-PG2_TABS-1
						; byte count-1
LAB_2D13
	LDA	PG2_TABS,X			; get byte
	LDY	#00				; SET DATA BANK = TO ZERO BANK
	PHY
	PLB					;
	STA	>ccflag,X			; store in page 2
	LDY	#PROGRAMBANK			; SET DATA BANK = TO PROGRAM BANK TO ALLOW FOR INITIALIZATION FROM ROM
	PHY
	PLB					;

	DEX					; decrement count
	BPL	LAB_2D13			; loop if not done

	LDX	#$FF				; set byte
	STX	<Clineh				; set current line high byte (set immediate mode)

	LDA	#$4C				; code for JMP
	STA	<Fnxjmp				; save for jump vector for functions

; copy block from LAB_2CEE to $00BC - $00E0

	LDY	#LAB_2CEE_END-LAB_2CEE		; set byte count
LAB_2D4E
	LDX	LAB_2CEE-1,Y			; get byte from table
	STX	<LAB_IGBY-1,Y			; save byte in page zero
	DEY					; decrement count
	BNE	LAB_2D4E			; loop if not all done

; copy block from StrTab to $0000 - $0012

LAB_GMEM
	LDY	#EndTab-StrTab-1		; set byte count-1
TabLoop
	LDX	StrTab,Y			; get byte from table
	STX	<PLUS_0,Y			; save byte in page zero
	DEY					; decrement count
	BPL	TabLoop				; loop if not all done

; DO TITLE SCREEN
	JSR 	TitleScreen


; set-up start values
	LDA	#DATABANK		; SET DATA BANK = TO DATA BANK, ALL PROGRAM DATA IN THIS AREA
	STA	<Bpntrp			; SET LAB_GBYT PAGE POINTER TO DATA BANK
	PHA
	PLB
	LDA 	#2			;
	STA 	<VIDEOMODE
	LDA	#$00			; clear A
	STA	<NmiBase		; clear NMI handler enabled flag
	STA	<IrqBase		; clear IRQ handler enabled flag
	STA	<FAC1_o			; clear FAC1 overflow byte
	STA	<last_sh		; clear descriptor stack top item pointer high byte

	LDA	#$0E			; set default tab size
	STA	<TabSiz			; save it
	LDA	#$03			; set garbage collect step size for descriptor stack
	STA	<g_step			; save it
	LDX	#<des_sk		; descriptor stack start
	STX	<next_s			; set descriptor stack pointer
	JSR	LAB_CRLF		; print CR/LF

	LDA #<Ram_top
	LDY #>Ram_top
	STA	<Ememl			; set end of mem low byte
	STY	<Ememh			; set end of mem high byte
	STA	<Sstorl			; set bottom of string space low byte
	STY	<Sstorh			; set bottom of string space high byte

	LDY	#<Ram_base		; set start addr low byte
	LDX	#>Ram_base		; set start addr high byte
	STY	<Smeml			; save start of mem low byte
	STX	<Smemh			; save start of mem high byte

	TYA					; clear A
	STA	(<Smeml),Y		; clear first byte
	INC	<Smeml			; increment start of mem low byte
LAB_2E05
	JSR	LAB_CRLF		; print CR/LF
	JSR	LAB_1463		; do "NEW" and "CLEAR"
	LDA	<Ememl			; get end of mem low byte
	SEC				; set carry for subtract
	SBC	<Smeml			; subtract start of mem low byte
	TAX				; copy to X
	LDA	<Ememh			; get end of mem high byte
	SBC	<Smemh			; subtract start of mem high byte
	JSR	LAB_295E		; print XA as unsigned integer (bytes free)
	LDA	#<LAB_SMSG		; point to sign-on message (low addr)
	LDY	#>LAB_SMSG		; point to sign-on message (high addr)
	JSR	LAB_18C3		; print null terminated string from memory
	LDA	#<LAB_1274		; warm start vector low byte
	LDY	#>LAB_1274		; warm start vector high byte
	STA	<Wrmjpl		; save warm start vector low byte
	STY	<Wrmjph		; save warm start vector high byte
	JMP	(Wrmjpl)		; go do warm start

; open up space in memory
; move (<Ostrtl)-(<Obendl) to new block ending at (<Nbendl)

; <Nbendl,<Nbendh - new block end address (A/Y)
; <Obendl,<Obendh - old block end address
; <Ostrtl,<Ostrth - old block start address

; returns with ..

; <Nbendl,<Nbendh - new block start address (high byte - $100)
; <Obendl,<Obendh - old block start address (high byte - $100)
; <Ostrtl,<Ostrth - old block start address (unchanged)

LAB_11CF
	JSR	LAB_121F		; check available memory, "Out of memory" error if no room
					; addr to check is in AY (low/high)
	STA	<Earryl		; save new array mem end low byte
	STY	<Earryh		; save new array mem end high byte

; open up space in memory
; move (<Ostrtl)-(<Obendl) to new block ending at (<Nbendl)
; don't set array end
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

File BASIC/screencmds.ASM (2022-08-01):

;___SCNCLR_________________________________________________
;
; UTILIZE BIOS TO CLEAR SCREEN
;
;
; THIS IS NATIVE '816 CODE
;__________________________________________________________
V_SCNCLR:
        PHB
        SETBANK 0
        JSL LClearScrVec
        PLB
        RTS

;___LOCATE_________________________________________________
;
; UTILIZE BIOS TO LOCATE CURSOR
;
;  TAKES TWO PARAMETERS X,Y
;
; THIS IS NATIVE '816 CODE
;__________________________________________________________
V_LOCATE:
        JSR	LAB_GTBY    ; GET THE FIRST PARAMETER, RETURN IN X (FILE#)
        phx
        JSR	LAB_1C01    ; (AFTER ',') OR SYN ERR
        JSR	LAB_GTBY    ; GET THE SECOND PARAMETER, RETURN IN X (DEVICE)
        PLY
        PHB
        SETBANK 0
        JSL LSetXYVEC
        PLB
        RTS

;___COLOR_________________________________________________
;
; UTILIZE BIOS TO SET COLORS
;
;  TAKES TWO PARAMETERS BACKGROUND,FOREGROUND
;
; THIS IS NATIVE '816 CODE
;__________________________________________________________
V_COLOR:
        JSR	LAB_GTBY    ; GET THE FIRST PARAMETER, RETURN IN X (FILE#)
        TXA
        AND     #$0F
        PHA
        JSR	LAB_1C01    ; (AFTER ',') OR SYN ERR
        JSR	LAB_GTBY    ; GET THE SECOND PARAMETER, RETURN IN X (DEVICE)
        TXA
        AND     #$0F
        CLC
        ASL
        ASL
        ASL
        ASL
        STA <TMPFLG
        pla
        ORA <TMPFLG
        PHB
        SETBANK 0
        JSL LSetColorVEC
        PLB
        RTS

;___V_SPEEK()______________________________________________
;
; GET VALUE FROM SCREEN MEMORY
;
;  TAKES ONE PARAMETER (ADDRESS), RETURNS VALUE
;
; THIS IS NATIVE '816 CODE
;__________________________________________________________
V_SPEEK:
	JSR	LAB_F2FX		; save integer part of FAC1 in temporary integer

       	PHB
        setbank 0
	LDX	#$00			; clear index
        JSR SPEEK_1
        plb
	TAY				; copy byte to Y
	JMP	LAB_1FD0		; convert Y to byte in FAC1 and return

SPEEK_1:
	LDA	<Itempl
	sta	>CMDP
        jsr     DELAY9918
        LDA 	<Itemph
        ORA	#$40
	AND	#$7F
	sta	>CMDP
        jsr     DELAY9918
        LDA     >DATAP
;       REPEATING THE READ FOR RELIABILITY (SOMETIMES ONE READ DOES NOT WORK, IF THE 9918 IS EVER REPLACED WITH A v99x8 THIS CAN BE REMOVED)
	LDA	<Itempl
	sta	>CMDP
        jsr     DELAY9918
        LDA 	<Itemph
        ORA	#$40
	AND	#$7F
	sta	>CMDP
        jsr     DELAY9918
        LDA     >DATAP
	RTS

;___V_SPOKE_________________________________________________
;
; PUT VALUE IN SCREEN MEMORY
;
;  TAKES TWO PARAMETERS ADDRESS,VALUE
;
; THIS IS NATIVE '816 CODE
;__________________________________________________________
V_SPOKE:
	JSR	LAB_GADB		; get two parameters for POKE or WAIT
        PHB
	PHX				; SAVE byte argument
        SETBANK 0
        ; Let's set VDP write address to Itemp
	LDA	<Itempl
	sta	CMDP
        jsr     DELAY9918
        LDA 	<Itemph
	AND	#$7F
        ORA	#$40
	sta	CMDP
        jsr     DELAY9918
        PLA
	STA	DATAP
        PLB
	RTS

;___V_SCREEN_________________________________________________
;
;  SET SCREEN MODE
;
;  TAKES ONE PARAMETER,  SCREEN MODE
;  0=GRAPHICS MODE (32X24)
;  1=MULTICOLOR (64X48 BLOCKS)
;  2=TEXT MODE (40X24)
;  4=GRAPHICS MODE 2 (32X24 MULTICOLOR)
; THIS IS NATIVE '816 CODE
;__________________________________________________________
V_SCREEN:
        JSR	LAB_CKRN    ; check not Direct, back here if ok
        JSR	LAB_GTBY    ; GET THE FIRST PARAMETER, RETURN IN X (MODE)
V_SCREEN1:
        STX     <VIDEOMODE
        CPX     #00
        BNE     *+5
        JMP     SETUPMODE0
        CPX     #01
        BNE     *+5
        JMP     SETUPMODE1
        CPX     #02
        BNE     *+5
        JMP     SETUPMODE2
        CPX     #03
        BNE     *+5
        JMP     SETUPMODE3
        CPX     #04
        BNE     *+5
        JMP     SETUPMODE4

        ldx #$02            ; SYNTAX ERROR
        jsr LAB_XERR
        JMP LAB_1319        ; RESET VARS, STACK AND RETURN CONTROL TO BASIC

        RTS

SETUPMODE0:
       	LDA	#<Mode0Parameters	; point to Parameters for Mode 4
   	LDY	#>Mode0Parameters
        jsr     Set9918Parms
 ;       CLEAR RAM
        INDEX16
        LDX     #$0000
        STX     <LOCALWORK
        INDEX8
        JSR     SET9918ADDRESS
        INDEX16
        LDX     #$4000
        LDA     #$00
SETUPMODE0_1:
        JSR     DELAY9918
        STA     >DATAP
        DEX
        CPX     #$0000
        BNE     SETUPMODE0_1
        INDEX8
        rts
SETUPMODE1:
       	LDA	#<Mode1Parameters	; point to Parameters for Mode 4
   	LDY	#>Mode1Parameters
        jsr     Set9918Parms
        PHB
        setbank 0
        ldy #$00
SETUPMODE1_1:
        ACCUMULATOR16
        TYA
        and #$00FF
        CLC
        ASL     ; a=y*32
        ASL
        ASL
        ASL
        ASL
        CLC
        ADC #1024
        sta <LOCALWORK
        ACCUMULATOR8
	LDA <LOCALWORK
	sta CMDP
        jsr     DELAY9918
	LDA <LOCALWORK+1
	ORA #$40
	AND #$7F
	sta CMDP
        TYA
        and #$FC
        CLC
        ASL
        ASL
        ASL
        sta <Itempl
        ldx #$00
SETUPMODE1_2:
        lda <Itempl
        sta DATAP
        jsr     DELAY9918
        inc <Itempl
        inx
        cpx #32
        bne SETUPMODE1_2
        iny
        cpy #24
        bne SETUPMODE1_1
; CLEAR SCREEN
        INDEX16
        jsr     DELAY9918
        LDA #$00
	sta CMDP
        jsr     DELAY9918
        LDX #$0000
	LDA #$08
	ORA #$40
	AND #$7F
	sta CMDP
        LDA #$00
SETUPMODE1_3:
        jsr     DELAY9918
        STA DATAP
        inx
        CPX #$0601
        BNE SETUPMODE1_3
        INDEX8
        plb
        RTS
SETUPMODE2:
        LDA     #40
        STA     >VIDEOWIDTH
       	LDA	#<Mode2Parameters	; point to Parameters for Mode 4
   	LDY	#>Mode2Parameters
        jsr     Set9918Parms
        PHB
        SETBANK 0
        JSL LLOADFONTVec
        JSL LClearScrVec
        PLB
        RTS
SETUPMODE3:
       	LDA	#<Mode3Parameters	; point to Parameters for Mode 4
   	LDY	#>Mode3Parameters
        jsr     Set9918Parms
 ;       CLEAR RAM
        INDEX16
        LDX     #$0000
        STX     <LOCALWORK
        INDEX8
        JSR     SET9918ADDRESS
        INDEX16
        LDX     #$4000
        LDA     #$00
SETUPMODE3_1:
        JSR     DELAY9918
        STA     >DATAP
        DEX
        CPX     #$0000
        BNE     SETUPMODE3_1
        INDEX8
        rts
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
